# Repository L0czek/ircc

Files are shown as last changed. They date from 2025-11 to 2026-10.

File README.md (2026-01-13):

# Resonant Converter Controller

This repository contains a work-in-progress resonant converter controller project based on the STM32G474 microcontroller. The system splits responsibilities between the MCU (`controller`) and a host application (`host`) running on an x86 machine for configuration, logging, and waveform retrieval.

**Goals**
- Implement a phase-shifted resonant converter controller using the STM32G474 high-resolution timers.
- Provide over-current and other protections using built-in ADCs and comparator peripherals.
- Log waveforms to local SRAM for later retrieval by the host.
- Provide a PC-side host binary to configure and interact with the MCU.

Repository layout
- [controller](controller): MCU firmware (STM32 HAL-based). Core control logic lives here.
- [host](host): Host-side application that communicates with the MCU (x86 binary).
- [target](target): CubeMX / board-specific projects and HAL integration for different targets/boards.
- [pcb](pcb): KiCad PCB design files for the controller hardware.
- [protocol](protocol): Protocol definitions and protobufs used by host/MCU.
- [external](external): Third-party libraries and dependencies (e.g., nanpb, drivers).
- [build](build): Top-level build artifacts and CMake cache (generated during builds).

Quick start

Build host part (x86):

1. Enter the host directory and create a build directory:

```bash
cd host
mkdir -p build && cd build
cmake ..
make -j
```

The produced host binary will be in `host/build` (or as specified by the host CMakeLists).

Build MCU firmware:

1. Edit or inspect the CubeMX project in the appropriate `target/*` folder (for your chosen board). Generate code from CubeMX if you modify pin/peripheral configuration.
2. Use CMake from the top-level CMake to build the firmware. Example (from project root):

```bash
mkdir -p build-mcu && cd build-mcu
cmake -DCMAKE_TOOLCHAIN_FILE=cmake/gcc-arm-none-eabi.cmake ..
make -j
```

Flashing and debugging
- An OpenOCD config is available at `build/openocd.cfg` for target debugging.
- Typical workflow using the repository make targets:

	1. Start OpenOCD to provide the debug server:

		 ```bash
		 make openocd
		 ```

	2. In a separate terminal, flash or debug the firmware:

		 - To flash and run the firmware:

			 ```bash
			 make run
			 ```

		 - To spawn `gdb` for interactive debugging (connects to the OpenOCD server):

			 ```bash
			 make gdb
			 ```

- Or use your preferred OpenOCD/ST-Link workflow if you have a different setup.

Protocol and message formats
- Communication between host and MCU uses a UART serial link and the message definitions in the [protocol](protocol) directory (protobuf/nanopb). Regenerate or inspect generated code if you change `.proto` files.

Design notes
- The controller firmware uses the STM32G474 high-resolution timers to implement phase-shift control for MOSFET/IGBT bridge switching.
- ADCs, comparators, and timers are used for protections, sampling, and logging to SRAM.

Acknowledgements
- Third-party libraries are located in `external/` — see their respective LICENSE files for details.

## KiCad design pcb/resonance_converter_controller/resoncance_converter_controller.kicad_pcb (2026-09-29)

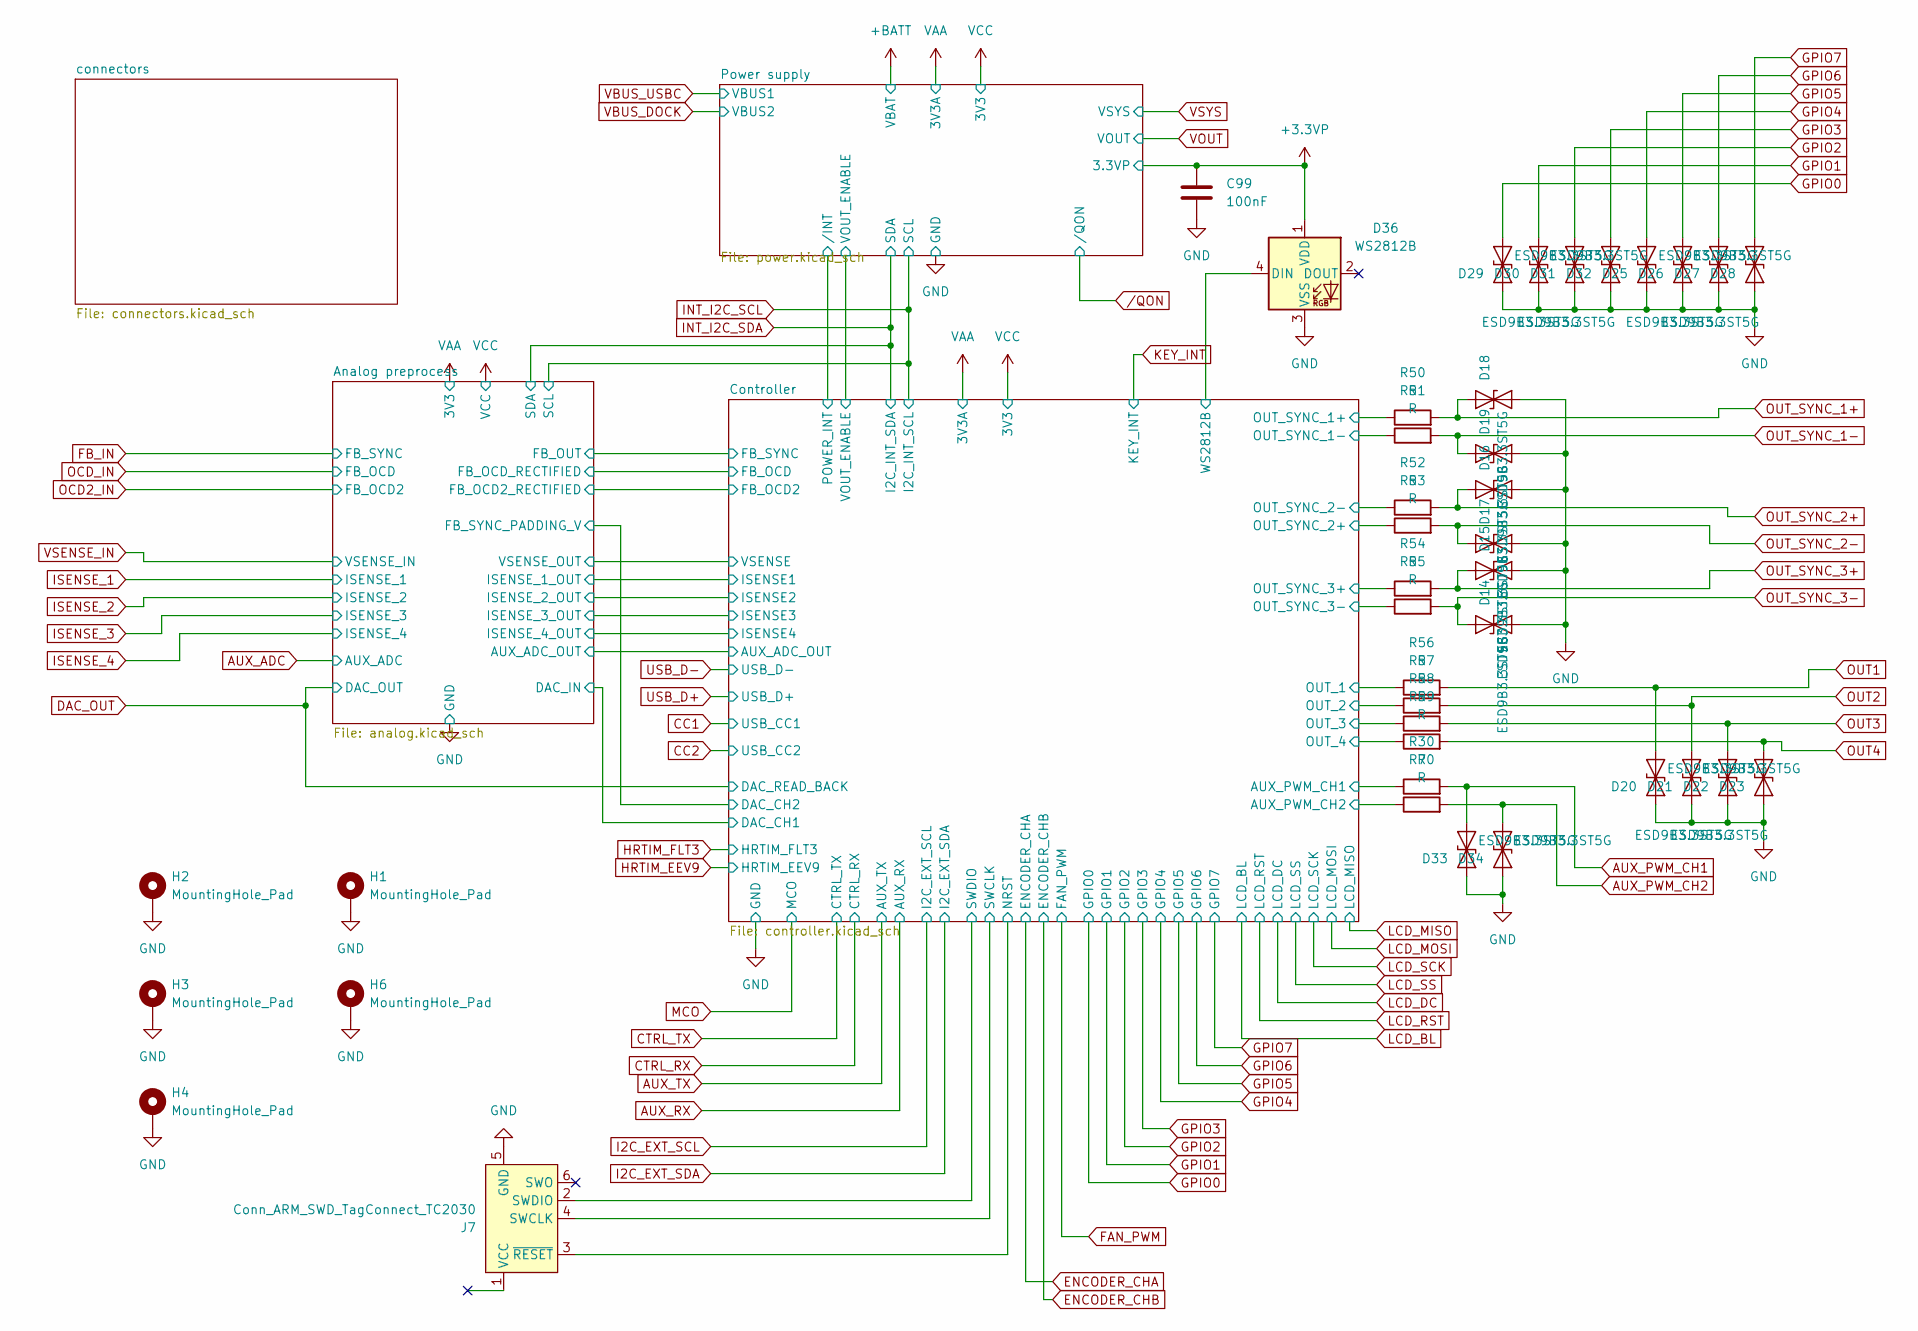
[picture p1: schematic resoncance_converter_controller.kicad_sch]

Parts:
C99: 100nF; C_0402_1005Metric
D14, D15, D16, D17, D18, D19, D20, D21, D22, D23, D25, D26, D27, D28, D29, D30, D31, D32, D33, D34: ESD9B3.3ST5G; D_SOD-923
D36: WS2812B; LED_WS2812B-Mini_PLCC4_3.5x3.5mm
H1, H2, H3, H4, H6: MountingHole_Pad; MountingHole_2.2mm_M2_Pad_Via
J7: Conn_ARM_SWD_TagConnect_TC2030; Tag-Connect_TC2030-IDC-FP_2x03_P1.27mm_Vertical
R30, R50, R51, R52, R53, R54, R55, R56, R57, R58, R59, R70: R; R_0402_1005Metric

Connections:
+3.3VP: C99.1, D36.1 (VDD); also elsewhere on the board
/Controller/AUX_PWM_CH1: R30.1; also elsewhere on the board
/Controller/AUX_PWM_CH2: R70.1; also elsewhere on the board
/Controller/OUT_1: R56.1; also elsewhere on the board
/Controller/OUT_2: R57.1; also elsewhere on the board
/Controller/OUT_3: R58.1; also elsewhere on the board
/Controller/OUT_4: R59.1; also elsewhere on the board
/Controller/OUT_SYNC_1+: R50.1; also elsewhere on the board
/Controller/OUT_SYNC_1-: R51.1; also elsewhere on the board
/Controller/OUT_SYNC_2+: R53.1; also elsewhere on the board
/Controller/OUT_SYNC_2-: R52.1; also elsewhere on the board
/Controller/OUT_SYNC_3+: R54.1; also elsewhere on the board
/Controller/OUT_SYNC_3-: R55.1; also elsewhere on the board
/Controller/WS2812B: D36.4 (DIN); also elsewhere on the board
AUX_PWM_CH1: D33.1 (A1), R30.2; also elsewhere on the board
AUX_PWM_CH2: D34.1 (A1), R70.2; also elsewhere on the board
GND: C99.2, D14.1 (A1), D15.1 (A1), D16.1 (A1), D17.1 (A1), D18.1 (A1), D19.1 (A1), D20.2 (A2), D21.2 (A2), D22.2 (A2), D23.2 (A2), D25.2 (A2), D26.2 (A2), D27.2 (A2), D28.2 (A2), D29.2 (A2), D30.2 (A2), D31.2 (A2), D32.2 (A2), D33.2 (A2), D34.2 (A2), D36.3 (VSS), H1.1 (1_1), H2.1 (1_1), H3.1 (1_1), H4.1 (1_1), H6.1 (1_1), J7.5 (GND); also elsewhere on the board
GPIO0: D29.1 (A1); also elsewhere on the board
GPIO1: D30.1 (A1); also elsewhere on the board
GPIO2: D31.1 (A1); also elsewhere on the board
GPIO3: D32.1 (A1); also elsewhere on the board
GPIO4: D25.1 (A1); also elsewhere on the board
GPIO5: D26.1 (A1); also elsewhere on the board
GPIO6: D27.1 (A1); also elsewhere on the board
GPIO7: D28.1 (A1); also elsewhere on the board
NRST: J7.3 (~RESET); also elsewhere on the board
OUT1: D20.1 (A1), R56.2; also elsewhere on the board
OUT2: D21.1 (A1), R57.2; also elsewhere on the board
OUT3: D22.1 (A1), R58.2; also elsewhere on the board
OUT4: D23.1 (A1), R59.2; also elsewhere on the board
OUT_SYNC_1+: D18.2 (A2), R50.2; also elsewhere on the board
OUT_SYNC_1-: D19.2 (A2), R51.2; also elsewhere on the board
OUT_SYNC_2+: D16.2 (A2), R52.2; also elsewhere on the board
OUT_SYNC_2-: D17.2 (A2), R53.2; also elsewhere on the board
OUT_SYNC_3+: D15.2 (A2), R54.2; also elsewhere on the board
OUT_SYNC_3-: D14.2 (A2), R55.2; also elsewhere on the board
SWCLK: J7.4 (SWCLK); also elsewhere on the board
SWDIO: J7.2 (SWDIO); also elsewhere on the board

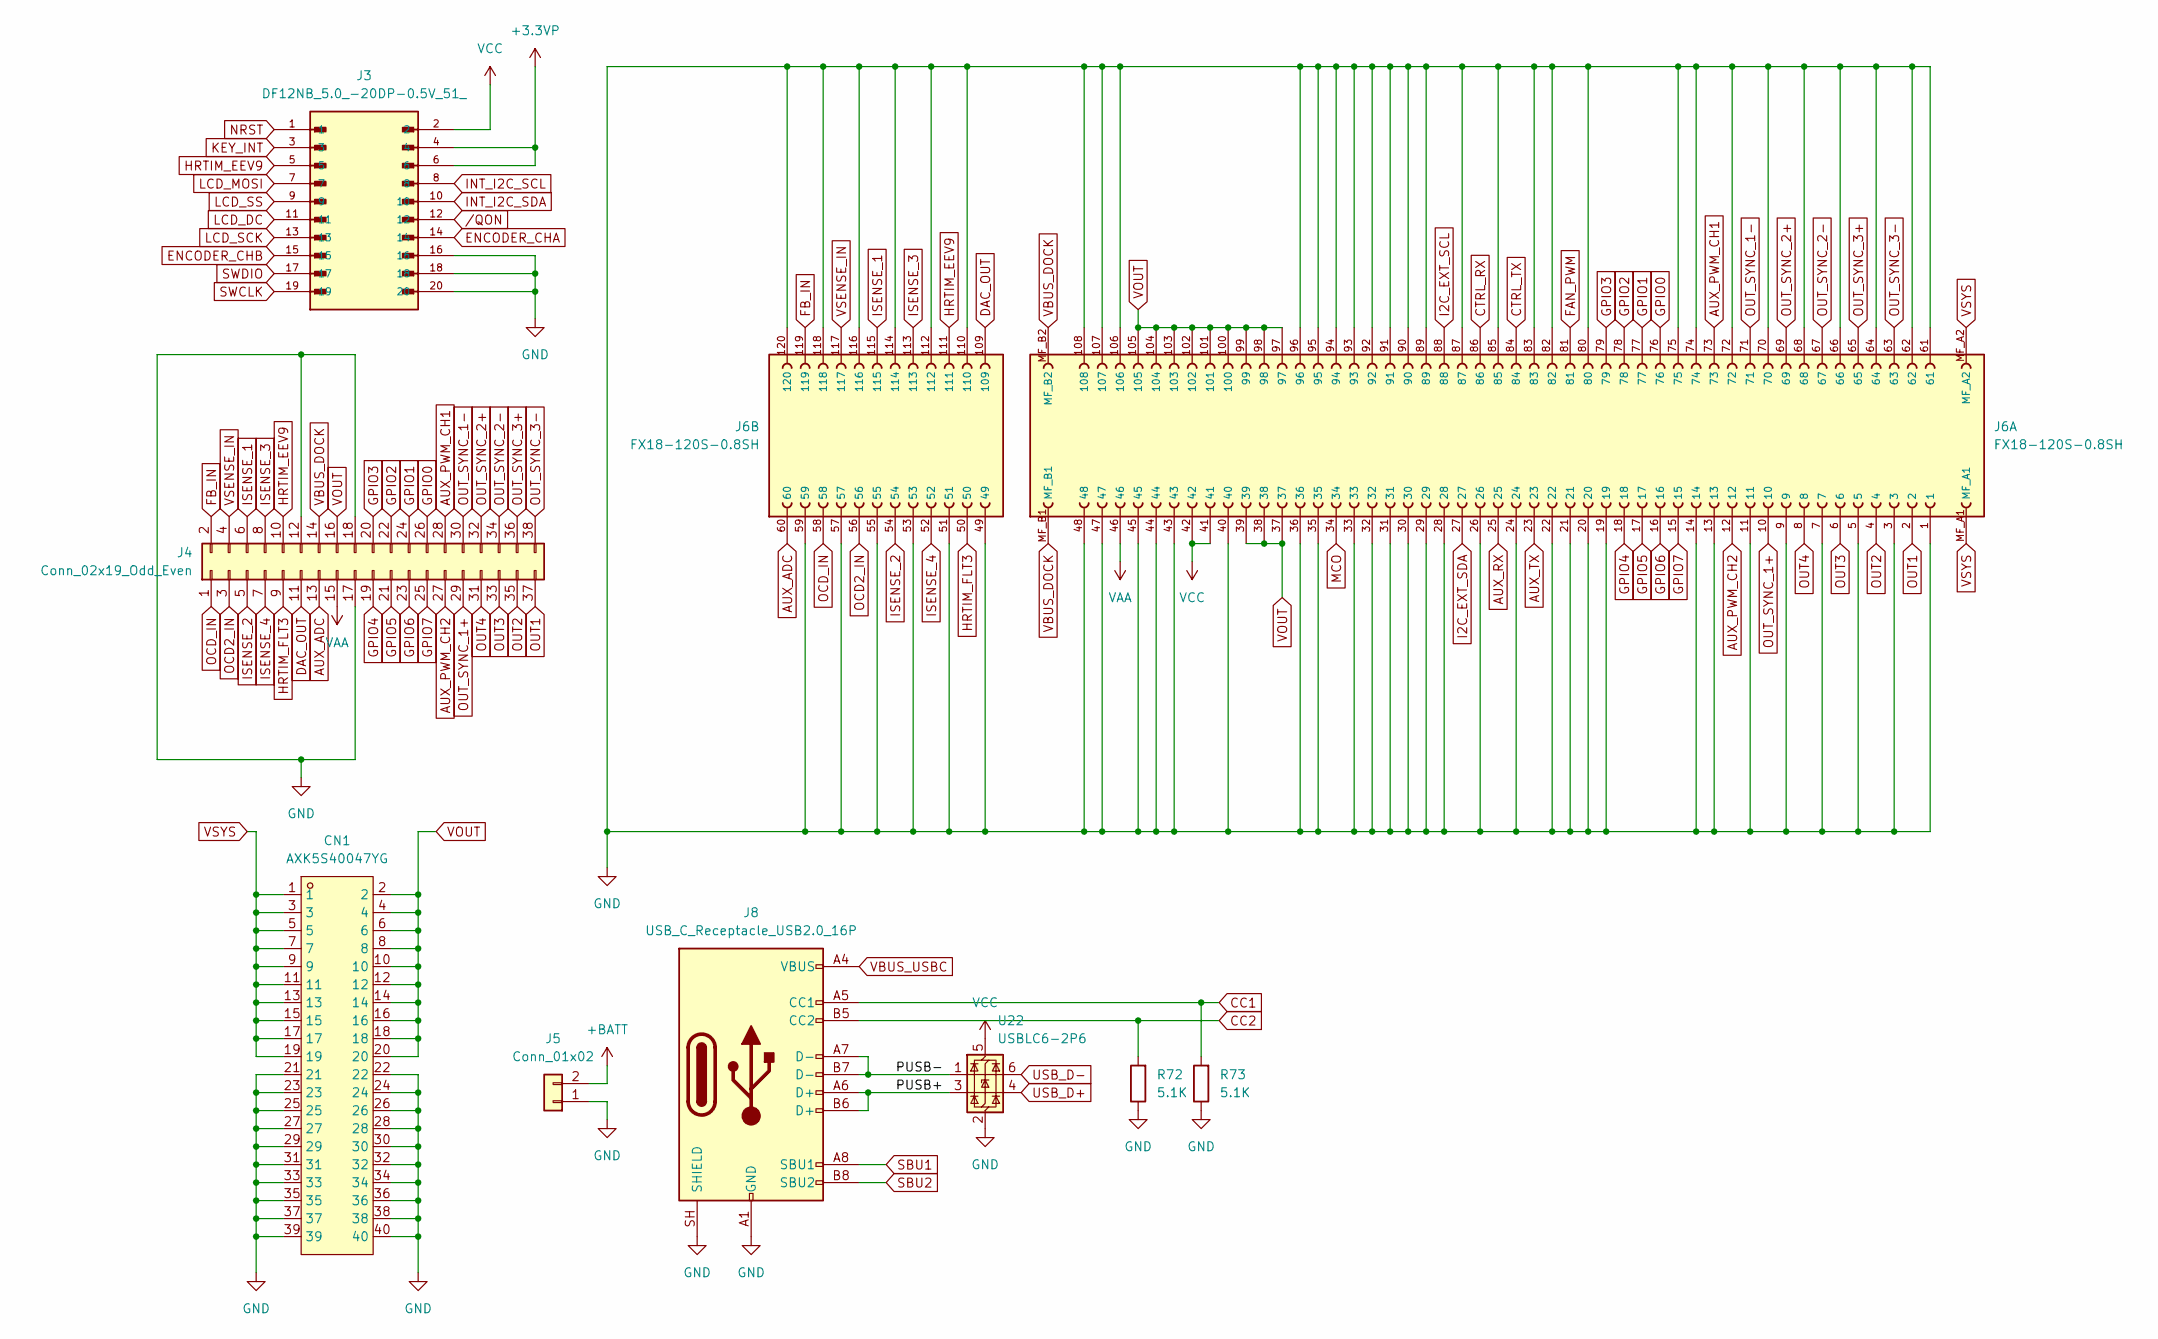
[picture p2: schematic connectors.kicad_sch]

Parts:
CN1: AXK5S40047YG; CONN-SMD_40P-P0.50_AXK5S40047YG; LCSC Part C3647996
J3: DF12NB_5.0_-20DP-0.5V_51_; HRS_DF12NB_5.0_-20DP-0.5V_51_
J4: Conn_02x19_Odd_Even; PinSocket_2x19_P2.54mm_Vertical_SMD
J5: Conn_01x02; AMASS_XT30U-M_1x02_P5.0mm_Vertical
J6: FX18-120S-0.8SH; HIROSE_FX18-120S-0.8SH; PARTREV 1
J8: USB_C_Receptacle_USB2.0_16P; USB_C_Receptacle_GCT_USB4105-xx-A_16P_TopMnt_Horizontal
R72, R73: 5.1K; R_0402_1005Metric
U22: USBLC6-2P6; SOT-666

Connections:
+3.3VP: J3.4, J3.6; also elsewhere on the board
+BATT: J5.2; also elsewhere on the board
/connectors/PUSB+: J8.A6 (D+), J8.B6 (D+), U22.3 (I/O2)
/connectors/PUSB-: J8.A7 (D-), J8.B7 (D-), U22.1 (I/O1)
AUX_ADC: J4.13, J6.60; also elsewhere on the board
AUX_PWM_CH1: J4.28, J6.73; also elsewhere on the board
AUX_PWM_CH2: J4.27, J6.12; also elsewhere on the board
AUX_RX: J6.25; also elsewhere on the board
AUX_TX: J6.23; also elsewhere on the board
CC1: J8.A5 (CC1), R73.2; also elsewhere on the board
CC2: J8.B5 (CC2), R72.2; also elsewhere on the board
CTRL_RX: J6.86; also elsewhere on the board
CTRL_TX: J6.84; also elsewhere on the board
DAC_OUT: J4.11, J6.109; also elsewhere on the board
ENCODER_CHA: J3.14; also elsewhere on the board
ENCODER_CHB: J3.15; also elsewhere on the board
FAN_PWM: J6.81; also elsewhere on the board
FB_IN: J4.2, J6.119; also elsewhere on the board
GND: CN1.21, CN1.22, CN1.23, CN1.24, CN1.25, CN1.26, CN1.27, CN1.28, CN1.29, CN1.30, CN1.31, CN1.32, CN1.33, CN1.34, CN1.35, CN1.36, CN1.37, CN1.38, CN1.39, CN1.40, J3.16, J3.18, J3.20, J4.12, J4.17, J4.18, J5.1, J6.1, J6.3, J6.5, J6.7, J6.9, J6.11, J6.13, J6.14, J6.19, J6.20, J6.21, J6.22, J6.24, J6.26, J6.28, J6.29, J6.30, J6.31, J6.32, J6.33, J6.35, J6.36, J6.40, J6.43, J6.44, J6.45, J6.47, J6.48, J6.49, J6.51, J6.53, J6.55, J6.57, J6.59, J6.61, J6.62, J6.64, J6.66, J6.68, J6.70, J6.72, J6.74, J6.75, J6.80, J6.82, J6.83, J6.85, J6.87, J6.89, J6.90, J6.91, J6.92, J6.93, J6.94, J6.95, J6.96, J6.106, J6.107, J6.108, J6.110, J6.112, J6.114, J6.116, J6.118, J6.120, J8.A1 (GND), J8.A12 (GND), J8.B1 (GND), J8.B12 (GND), J8.SH (SHIELD), R72.1, R73.1, U22.2 (GND); also elsewhere on the board
GPIO0: J4.26, J6.76; also elsewhere on the board
GPIO1: J4.24, J6.77; also elsewhere on the board
GPIO2: J4.22, J6.78; also elsewhere on the board
GPIO3: J4.20, J6.79; also elsewhere on the board
GPIO4: J4.19, J6.18; also elsewhere on the board
GPIO5: J4.21, J6.17; also elsewhere on the board
GPIO6: J4.23, J6.16; also elsewhere on the board
GPIO7: J4.25, J6.15; also elsewhere on the board
HRTIM_EEV9: J3.5, J4.10, J6.111; also elsewhere on the board
HRTIM_FLT3: J4.9, J6.50; also elsewhere on the board
I2C_EXT_SCL: J6.88; also elsewhere on the board
I2C_EXT_SDA: J6.27; also elsewhere on the board
INT_I2C_SCL: J3.8; also elsewhere on the board
INT_I2C_SDA: J3.10; also elsewhere on the board
ISENSE_1: J4.6, J6.115; also elsewhere on the board
ISENSE_2: J4.5, J6.54; also elsewhere on the board
ISENSE_3: J4.8, J6.113; also elsewhere on the board
ISENSE_4: J4.7, J6.52; also elsewhere on the board
KEY_INT: J3.3; also elsewhere on the board
LCD_DC: J3.11; also elsewhere on the board
LCD_MOSI: J3.7; also elsewhere on the board
LCD_SCK: J3.13; also elsewhere on the board
LCD_SS: J3.9; also elsewhere on the board
MCO: J6.34; also elsewhere on the board
NRST: J3.1; also elsewhere on the board
OCD2_IN: J4.3, J6.56; also elsewhere on the board
OCD_IN: J4.1, J6.58; also elsewhere on the board
OUT1: J4.37, J6.2; also elsewhere on the board
OUT2: J4.35, J6.4; also elsewhere on the board
OUT3: J4.33, J6.6; also elsewhere on the board
OUT4: J4.31, J6.8; also elsewhere on the board
OUT_SYNC_1+: J4.29, J6.10; also elsewhere on the board
OUT_SYNC_1-: J4.30, J6.71; also elsewhere on the board
OUT_SYNC_2+: J4.32, J6.69; also elsewhere on the board
OUT_SYNC_2-: J4.34, J6.67; also elsewhere on the board
OUT_SYNC_3+: J4.36, J6.65; also elsewhere on the board
OUT_SYNC_3-: J4.38, J6.63; also elsewhere on the board
SBU1: J8.A8 (SBU1); also elsewhere on the board
SBU2: J8.B8 (SBU2); also elsewhere on the board
SWCLK: J3.19; also elsewhere on the board
SWDIO: J3.17; also elsewhere on the board
USB_D+: U22.4 (I/O2); also elsewhere on the board
USB_D-: U22.6 (I/O1); also elsewhere on the board
VAA: J4.15, J6.46; also elsewhere on the board
VBUS_DOCK: J4.14, J6.MF_B1, J6.MF_B2; also elsewhere on the board
VBUS_USBC: J8.A4 (VBUS), J8.A9 (VBUS), J8.B4 (VBUS), J8.B9 (VBUS); also elsewhere on the board
VCC: J3.2, J6.41, J6.42, U22.5 (VBUS); also elsewhere on the board
VOUT: CN1.2, CN1.4, CN1.6, CN1.8, CN1.10, CN1.12, CN1.14, CN1.16, CN1.18, CN1.20, J4.16, J6.37, J6.38, J6.39, J6.97, J6.98, J6.99, J6.100, J6.101, J6.102, J6.103, J6.104, J6.105; also elsewhere on the board
VSENSE_IN: J4.4, J6.117; also elsewhere on the board
VSYS: CN1.1, CN1.3, CN1.5, CN1.7, CN1.9, CN1.11, CN1.13, CN1.15, CN1.17, CN1.19, J6.MF_A1, J6.MF_A2; also elsewhere on the board
/QON: J3.12; also elsewhere on the board

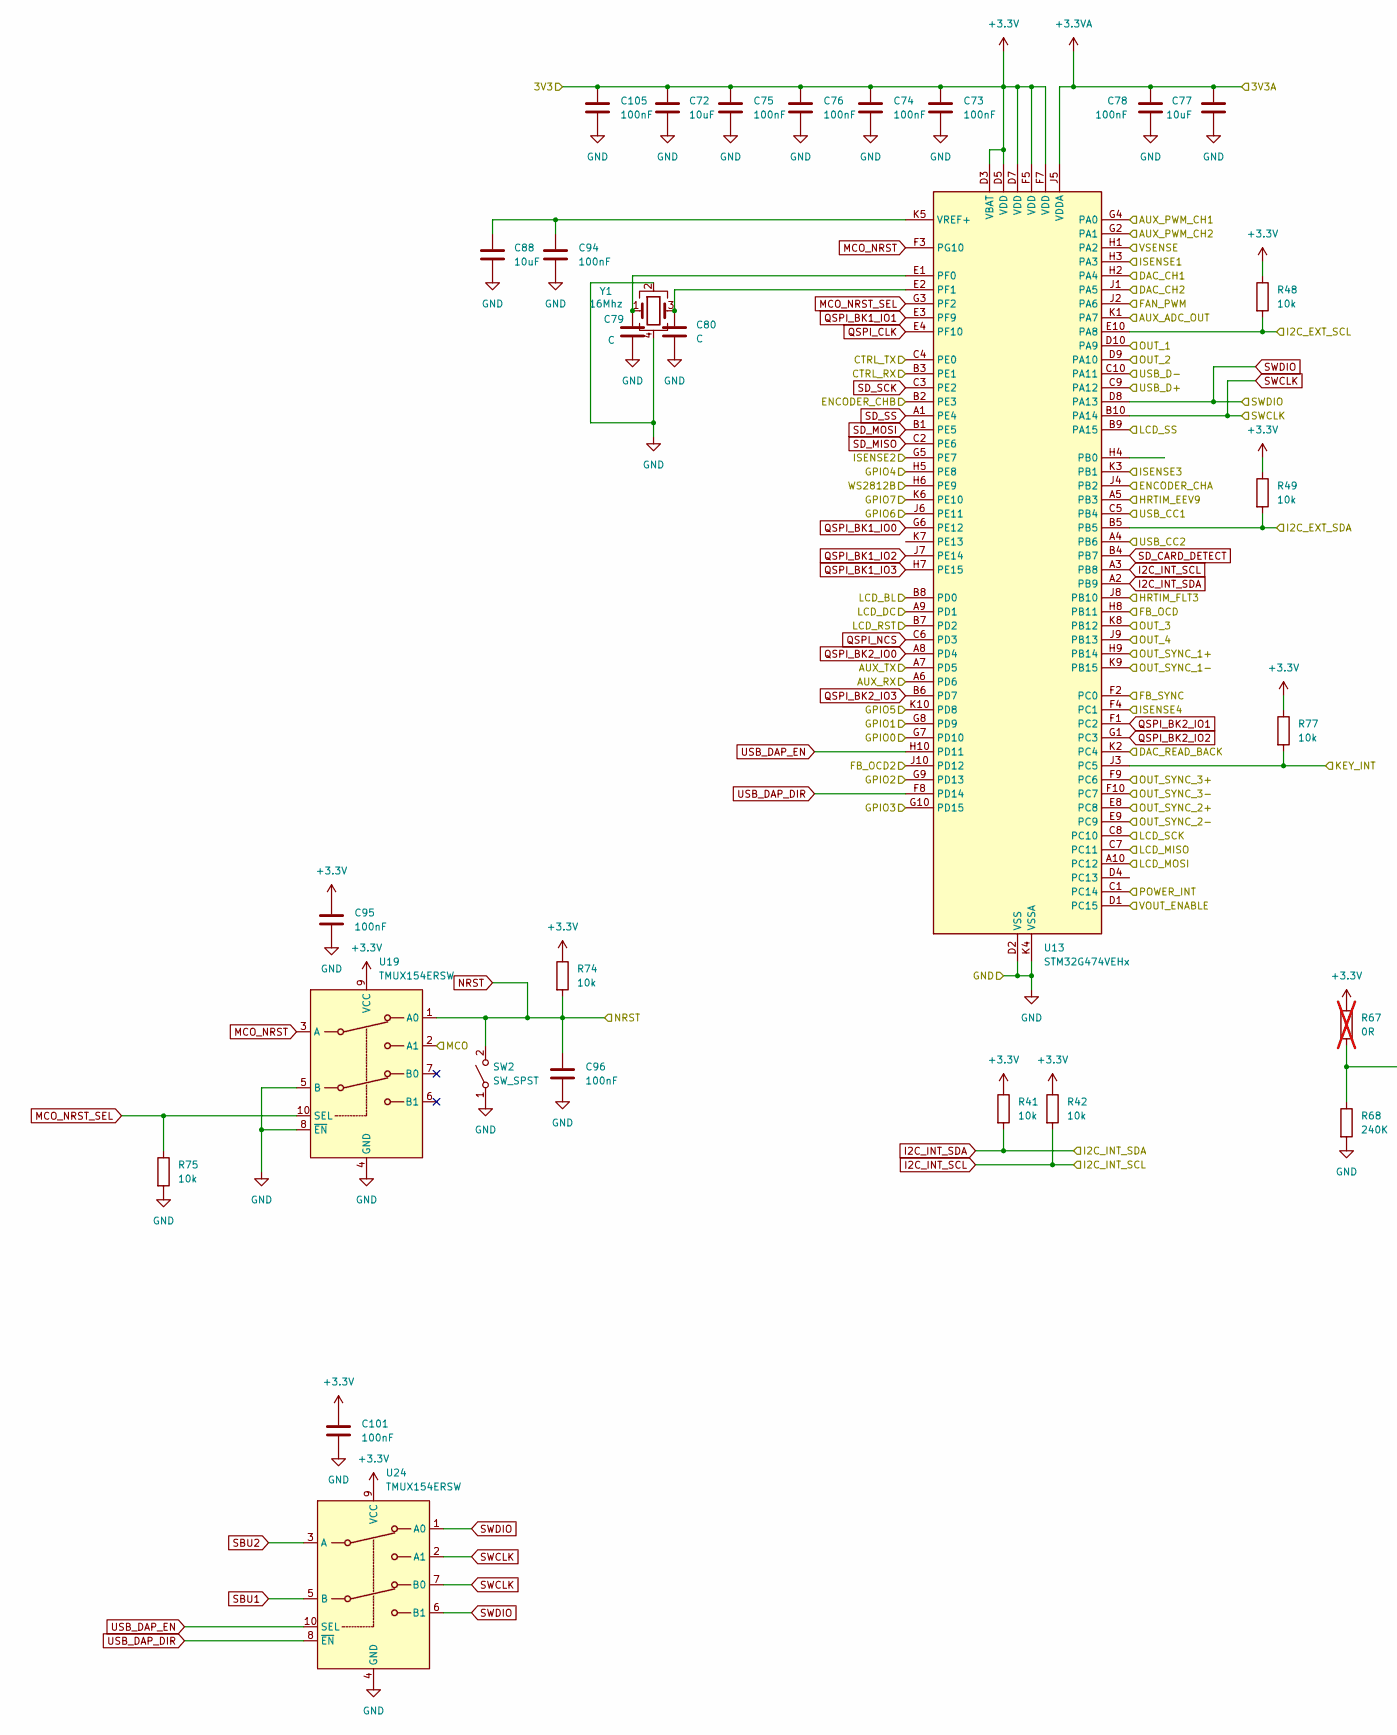
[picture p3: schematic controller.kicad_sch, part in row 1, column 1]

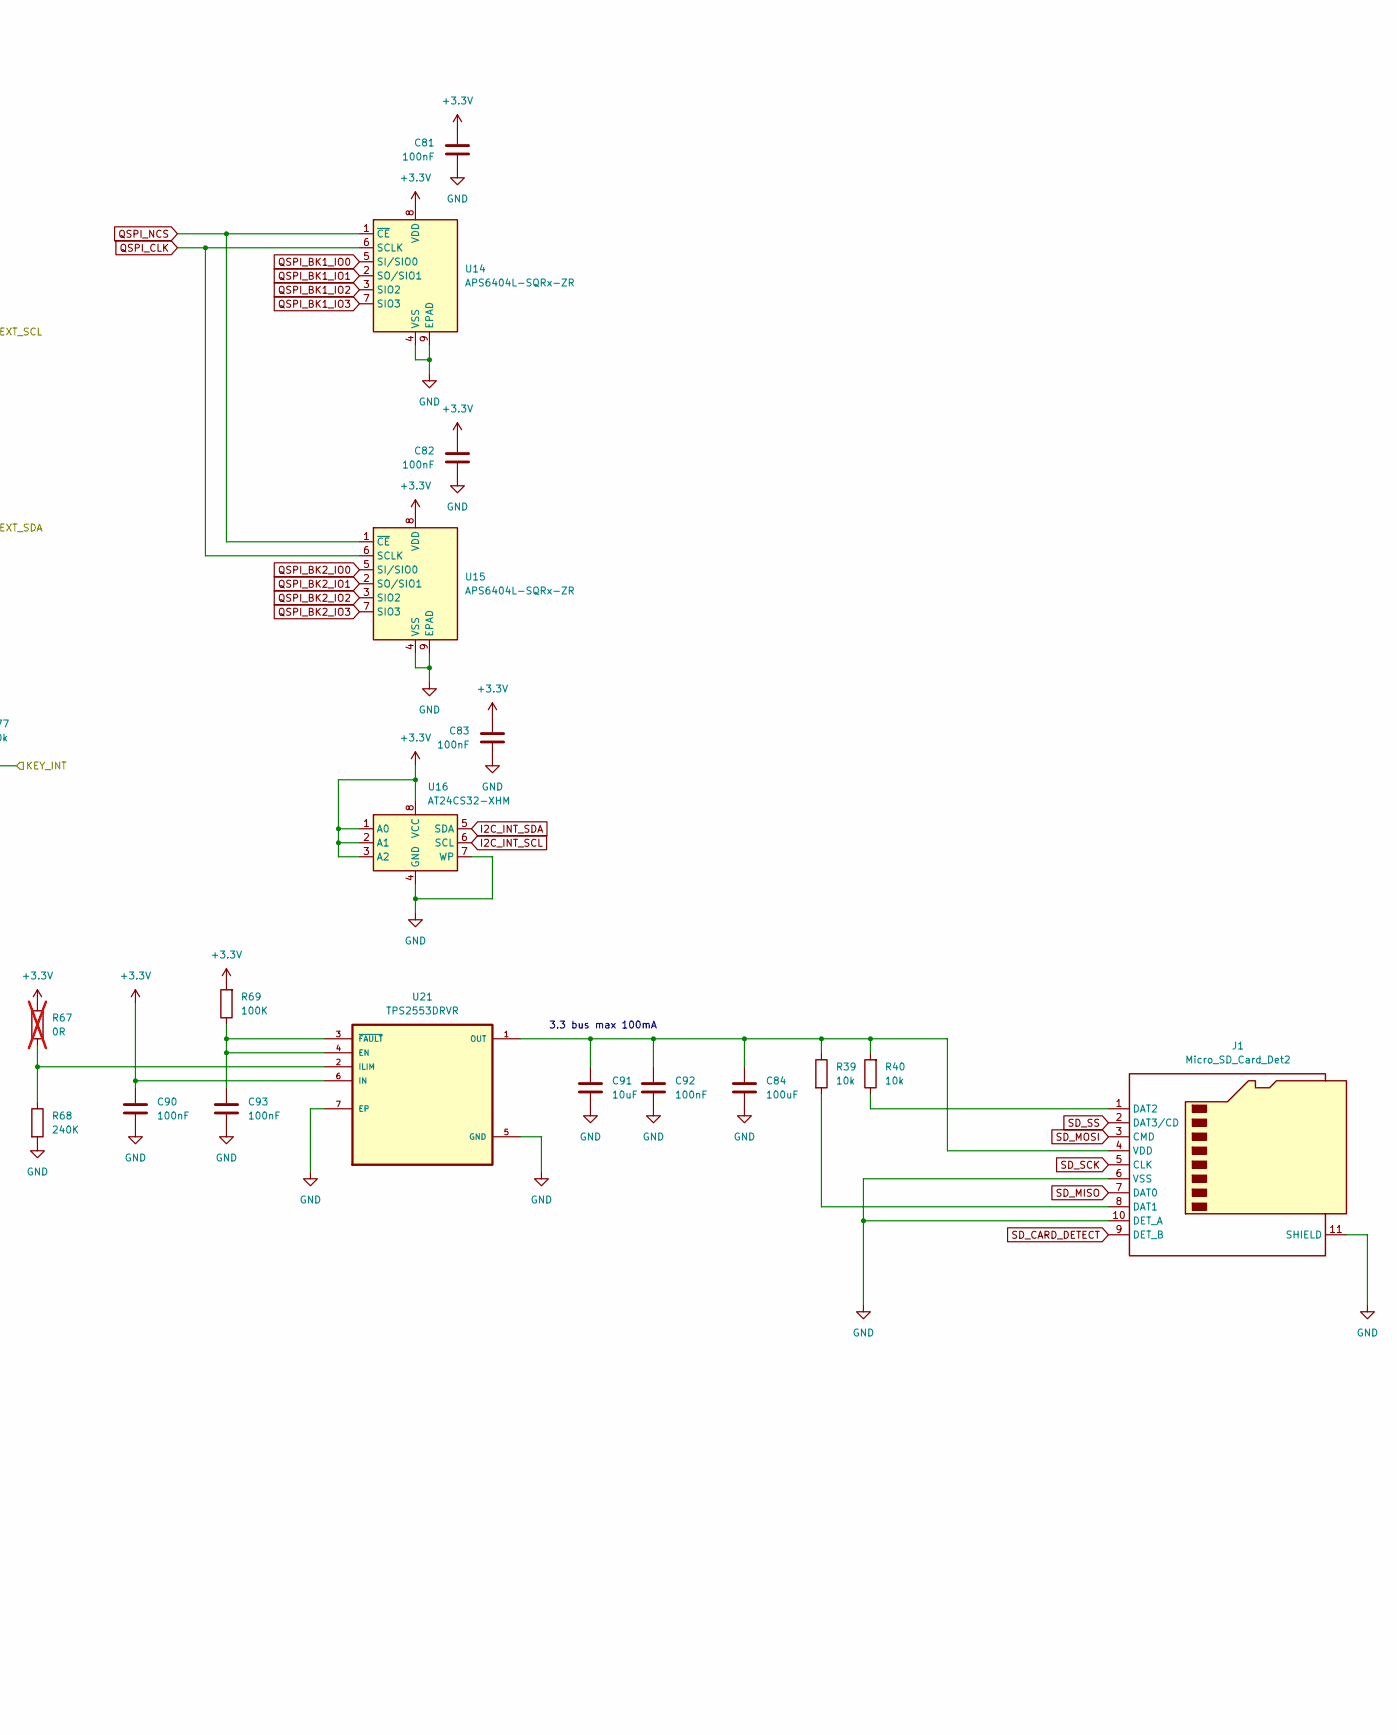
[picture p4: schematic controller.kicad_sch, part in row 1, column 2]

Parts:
C72, C77: 10uF; C_0805_2012Metric
C73, C74, C75, C76, C78, C81, C82, C83, C90, C92, C93, C94, C95, C96, C101, C105: 100nF; C_0402_1005Metric
C79, C80: C; C_0402_1005Metric
C84: 100uF; C_1206_3216Metric
C88: 10uF; C_0402_1005Metric
C91: 10uF; C_1206_3216Metric
J1: Micro_SD_Card_Det2; microSD_HC_Hirose_DM3BT-DSF-PEJS
R39, R40, R41, R42, R48, R49, R74, R75, R77: 10k; R_0402_1005Metric
R67: 0R; R_0402_1005Metric; not fitted
R68: 240K; R_0402_1005Metric
R69: 100K; R_0402_1005Metric
SW2: SW_SPST; SW_SPST_EVQPE1
U13: STM32G474VEHx; TFBGA-100_8x8mm_Layout10x10_P0.8mm
U14, U15: APS6404L-SQRx-ZR; Winbond_USON-8-1EP_3x2mm_P0.5mm_EP0.2x1.6mm
U16: AT24CS32-XHM; TSSOP-8_4.4x3mm_P0.65mm
U19, U24: TMUX154ERSW; UQFN-10_1.4x1.8mm_P0.4mm
U21: TPS2553DRVR; SON65P200X200X80-7N
Y1: 16Mhz; Crystal_SMD_3225-4Pin_3.2x2.5mm

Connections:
/Analog preprocess/DAC_IN: U13.H2 (PA4); also elsewhere on the board
/Analog preprocess/FB_OCD2_RECTIFIED: U13.J10 (PD12); also elsewhere on the board
/Analog preprocess/FB_OCD_RECTIFIED: U13.H8 (PB11); also elsewhere on the board
/Analog preprocess/FB_OUT: U13.F2 (PC0); also elsewhere on the board
/Analog preprocess/FB_SYNC_PADDING_V: U13.J1 (PA5); also elsewhere on the board
/Analog preprocess/VSENSE_OUT: U13.H1 (PA2); also elsewhere on the board
/Controller/AUX_PWM_CH1: U13.G4 (PA0); also elsewhere on the board
/Controller/AUX_PWM_CH2: U13.G2 (PA1); also elsewhere on the board
/Controller/OUT_1: U13.D10 (PA9); also elsewhere on the board
/Controller/OUT_2: U13.D9 (PA10); also elsewhere on the board
/Controller/OUT_3: U13.K8 (PB12); also elsewhere on the board
/Controller/OUT_4: U13.J9 (PB13); also elsewhere on the board
/Controller/OUT_SYNC_1+: U13.H9 (PB14); also elsewhere on the board
/Controller/OUT_SYNC_1-: U13.K9 (PB15); also elsewhere on the board
/Controller/OUT_SYNC_2+: U13.E8 (PC8); also elsewhere on the board
/Controller/OUT_SYNC_2-: U13.E9 (PC9); also elsewhere on the board
/Controller/OUT_SYNC_3+: U13.F9 (PC6); also elsewhere on the board
/Controller/OUT_SYNC_3-: U13.F10 (PC7); also elsewhere on the board
/Controller/VOUT_ENABLE: U13.D1 (PC15); also elsewhere on the board
/Controller/WS2812B: U13.H6 (PE9); also elsewhere on the board
AUX_ADC: U13.K1 (PA7); also elsewhere on the board
AUX_RX: U13.A6 (PD6); also elsewhere on the board
AUX_TX: U13.A7 (PD5); also elsewhere on the board
CC1: U13.C5 (PB4); also elsewhere on the board
CC2: U13.A4 (PB6); also elsewhere on the board
CTRL_RX: U13.B3 (PE1); also elsewhere on the board
CTRL_TX: U13.C4 (PE0); also elsewhere on the board
DAC_OUT: U13.K2 (PC4); also elsewhere on the board
ENCODER_CHA: U13.J4 (PB2); also elsewhere on the board
ENCODER_CHB: U13.B2 (PE3); also elsewhere on the board
FAN_PWM: U13.J2 (PA6); also elsewhere on the board
GND: C72.2, C73.2, C74.2, C75.2, C76.2, C77.2, C78.2, C79.2, C80.2, C81.2, C82.2, C83.2, C84.2, C88.2, C90.2, C91.2, C92.2, C93.2, C94.2, C95.2, C96.2, C101.2, C105.2, J1.6 (VSS), J1.10 (DET_A), J1.11 (SHIELD), R68.2, R75.2, SW2.1 (A), U13.D2 (VSS), U13.D6 (VSS), U13.E5 (VSS), U13.E6 (VSS), U13.E7 (VSS), U13.F6 (VSS), U13.K4 (VSSA), U14.4 (VSS), U14.9 (EPAD), U15.4 (VSS), U15.9 (EPAD), U16.4 (GND), U16.7 (WP), U19.4 (GND), U19.5 (B), U19.8 (~EN), U21.5 (GND), U21.7 (EP), U24.4 (GND), Y1.2, Y1.4; also elsewhere on the board
GPIO0: U13.G7 (PD10); also elsewhere on the board
GPIO1: U13.G8 (PD9); also elsewhere on the board
GPIO2: U13.G9 (PD13); also elsewhere on the board
GPIO3: U13.G10 (PD15); also elsewhere on the board
GPIO4: U13.H5 (PE8); also elsewhere on the board
GPIO5: U13.K10 (PD8); also elsewhere on the board
GPIO6: U13.J6 (PE11); also elsewhere on the board
GPIO7: U13.K6 (PE10); also elsewhere on the board
HRTIM_EEV9: U13.A5 (PB3); also elsewhere on the board
HRTIM_FLT3: U13.J8 (PB10); also elsewhere on the board
I2C_EXT_SCL: R48.2, U13.E10 (PA8); also elsewhere on the board
I2C_EXT_SDA: R49.2, U13.B5; also elsewhere on the board
INT_I2C_SCL: R42.2, U13.A3 (PB8), U16.6 (SCL); also elsewhere on the board
INT_I2C_SDA: R41.2, U13.A2 (PB9), U16.5 (SDA); also elsewhere on the board
ISENSE_1_DPOT: U13.H3 (PA3); also elsewhere on the board
ISENSE_2_DPOT: U13.G5 (PE7); also elsewhere on the board
ISENSE_3_DPOT: U13.K3 (PB1); also elsewhere on the board
ISENSE_4_DPOT: U13.F4 (PC1); also elsewhere on the board
KEY_INT: R77.2, U13.J3 (PC5); also elsewhere on the board
LCD_BL: U13.B8 (PD0)
LCD_DC: U13.A9 (PD1); also elsewhere on the board
LCD_MISO: U13.C7 (PC11)
LCD_MOSI: U13.A10 (PC12); also elsewhere on the board
LCD_RST: U13.B7 (PD2)
LCD_SCK: U13.C8 (PC10); also elsewhere on the board
LCD_SS: U13.B9 (PA15); also elsewhere on the board
MCO: U19.2 (A1); also elsewhere on the board
MCO_NRST: U13.F3 (PG10), U19.3 (A)
MCO_NRST_SEL: R75.1, U13.G3 (PF2), U19.10 (SEL)
NRST: C96.1, R74.2, SW2.2 (B), U19.1 (A0); also elsewhere on the board
unnamed: J1.8 (DAT1), R39.2
unnamed: J1.1 (DAT2), R40.1
unnamed: C84.1, C91.1, C92.1, J1.4 (VDD), R39.1, R40.2, U21.1 (OUT)
unnamed: C79.1, U13.E1 (PF0), Y1.1
unnamed: C80.1, U13.E2 (PF1), Y1.3
unnamed: C88.1, C94.1, U13.K5 (VREF+)
unnamed: C93.1, R69.1, U21.3 (~FAULT), U21.4 (EN)
unnamed: R67.2, R68.1, U21.2 (ILIM)
QSPI_BK1_IO0: U13.G6 (PE12), U14.5 (SI/SIO0)
QSPI_BK1_IO1: U13.E3 (PF9), U14.2 (SO/SIO1)
QSPI_BK1_IO2: U13.J7 (PE14), U14.3 (SIO2)
QSPI_BK1_IO3: U13.H7 (PE15), U14.7 (SIO3)
QSPI_BK2_IO0: U13.A8 (PD4), U15.5 (SI/SIO0)
QSPI_BK2_IO1: U13.F1 (PC2), U15.2 (SO/SIO1)
QSPI_BK2_IO2: U13.G1 (PC3), U15.3 (SIO2)
QSPI_BK2_IO3: U13.B6 (PD7), U15.7 (SIO3)
QSPI_CLK: U13.E4 (PF10), U14.6 (SCLK), U15.6 (SCLK)
QSPI_NCS: U13.C6 (PD3), U14.1 (~CE), U15.1 (~CE)
SBU1: U24.5 (B); also elsewhere on the board
SBU2: U24.3 (A); also elsewhere on the board
SD_CARD_DETECT: J1.9 (DET_B), U13.B4 (PB7)
SD_MISO: J1.7 (DAT0), U13.C2 (PE6)
SD_MOSI: J1.3 (CMD), U13.B1 (PE5)
SD_SCK: J1.5 (CLK), U13.C3 (PE2)
SD_SS: J1.2 (DAT3/CD), U13.A1 (PE4)
SWCLK: U13.B10 (PA14), U24.2 (A1), U24.7 (B0); also elsewhere on the board
SWDIO: U13.D8 (PA13), U24.1 (A0), U24.6 (B1); also elsewhere on the board
USB_D+: U13.C9 (PA12); also elsewhere on the board
USB_D-: U13.C10 (PA11); also elsewhere on the board
USB_DAP_DIR: U13.F8 (PD14), U24.8 (~EN)
USB_DAP_EN: U13.H10 (PD11), U24.10 (SEL)
VAA: C77.1, C78.1, U13.J5 (VDDA); also elsewhere on the board
VCC: C72.1, C73.1, C74.1, C75.1, C76.1, C81.1, C82.1, C83.1, C90.1, C95.1, C101.1, C105.1, R41.1, R42.1, R48.1, R49.1, R67.1, R69.2, R74.1, R77.1, U13.D3 (VBAT), U13.D5 (VDD), U13.D7 (VDD), U13.F5 (VDD), U13.F7 (VDD), U14.8 (VDD), U15.8 (VDD), U16.1 (A0), U16.2 (A1), U16.3 (A2), U16.8 (VCC), U19.9 (VCC), U21.6 (IN), U24.9 (VCC); also elsewhere on the board
/INT: U13.C1 (PC14); also elsewhere on the board

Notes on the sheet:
3.3 bus max 100mA

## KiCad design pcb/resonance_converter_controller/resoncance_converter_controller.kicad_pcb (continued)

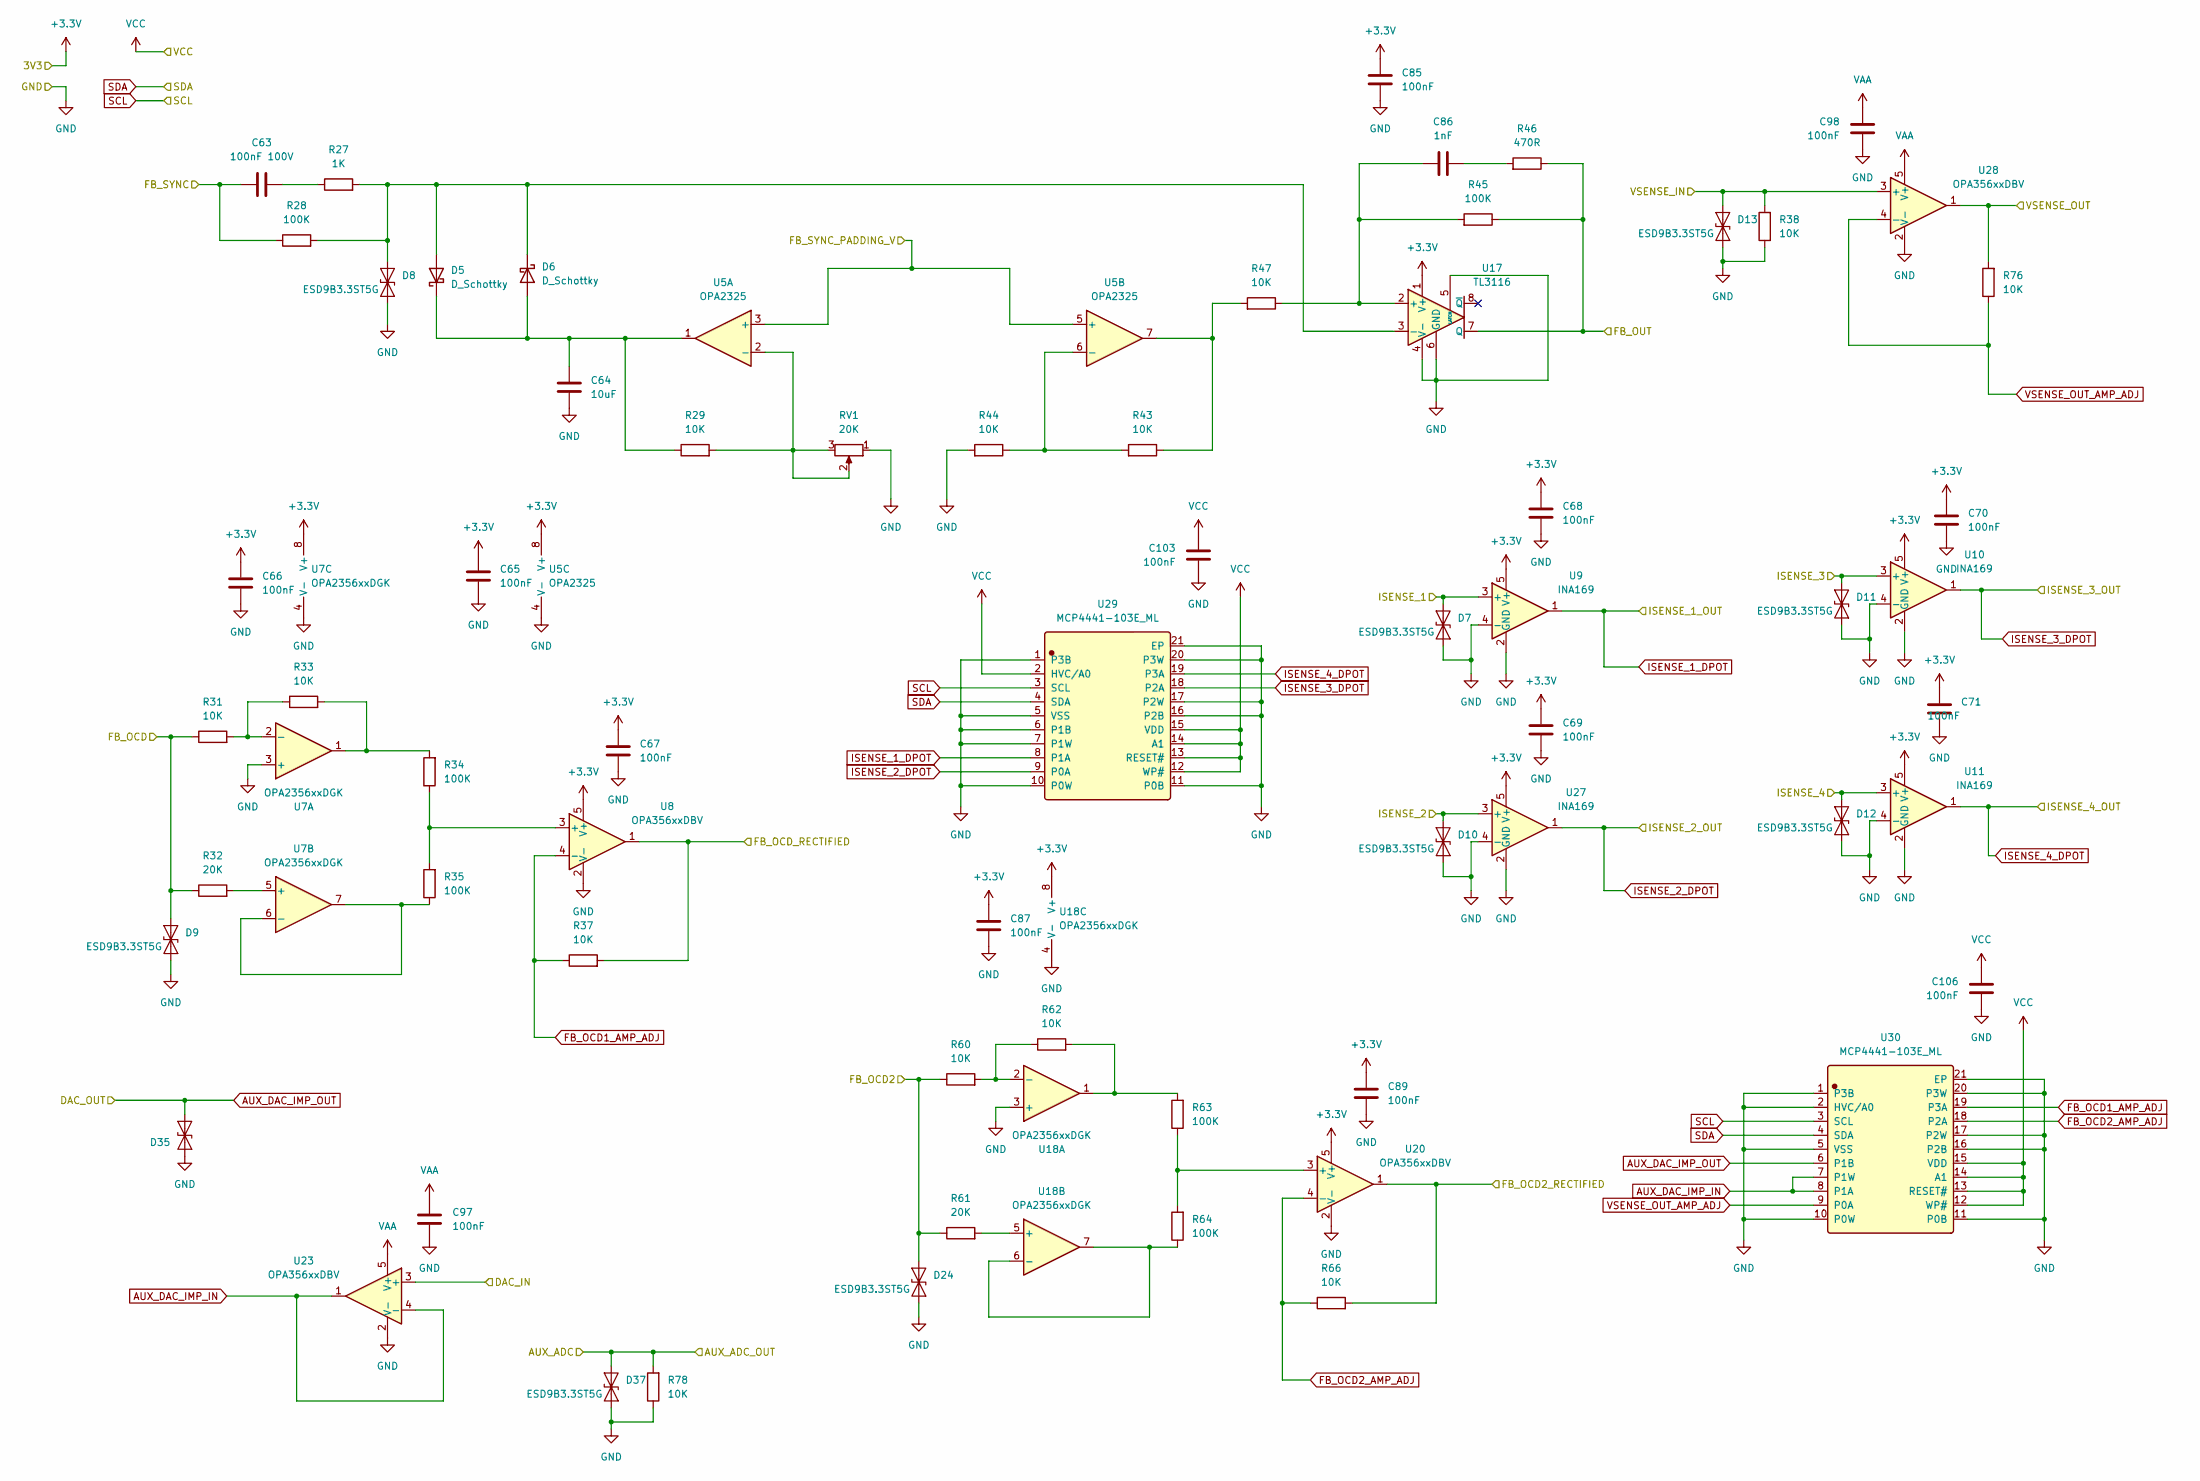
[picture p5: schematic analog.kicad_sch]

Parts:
C63: 100nF 100V; C_1206_3216Metric
C64: 10uF; C_1210_3225Metric
C65, C66, C67, C68, C69, C70, C71, C85, C87, C89, C97, C98, C103, C106: 100nF; C_0402_1005Metric
C86: 1nF; C_0402_1005Metric
D5, D6: D_Schottky; D_SOD-123
D7, D8, D9, D10, D11, D12, D13, D24, D35, D37: ESD9B3.3ST5G; D_SOD-923
R27: 1K; R_1206_3216Metric
R28: 100K; R_1206_3216Metric
R29, R31, R33, R37, R38, R43, R44, R47, R60, R62, R66, R76, R78: 10K; R_0402_1005Metric
R32, R61: 20K; R_0402_1005Metric
R34, R35, R45, R63, R64: 100K; R_0402_1005Metric
R46: 470R; R_0402_1005Metric
RV1: 20K; Potentiometer_Bourns_3269W_Vertical
U5: OPA2325; VSSOP-8_3x3mm_P0.65mm
U7, U18: OPA2356xxDGK; VSSOP-8_3x3mm_P0.65mm
U8, U20, U23, U28: OPA356xxDBV; SOT-23-5
U9, U10, U11, U27: INA169; SOT-23-5
U17: TL3116; TSSOP-8_4.4x3mm_P0.65mm
U29, U30: MCP4441-103E_ML; Texas_RGP0020H_VQFN-20-1EP_4x4mm_P0.5mm_EP2.4x2.4mm_Thermal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; Manufacturer Part MCP4441-103E/ML; LCSC C637735

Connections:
/Analog preprocess/DAC_IN: U23.3 (+); also elsewhere on the board
/Analog preprocess/FB_OCD2_RECTIFIED: R66.2, U20.1; also elsewhere on the board
/Analog preprocess/FB_OCD_RECTIFIED: R37.2, U8.1; also elsewhere on the board
/Analog preprocess/FB_OUT: R45.1, R46.1, U17.7 (Q); also elsewhere on the board
/Analog preprocess/FB_SYNC_PADDING_V: U5.3 (+), U5.5 (+); also elsewhere on the board
/Analog preprocess/VSENSE_OUT: R76.2, U28.1; also elsewhere on the board
AUX_ADC: D37.2 (A2), R78.2; also elsewhere on the board
AUX_DAC_IMP_IN: U23.1, U23.4 (-), U30.7 (P1W), U30.8 (P1A)
DAC_OUT: D35.1 (A1), U30.6 (P1B); also elsewhere on the board
FB_IN: C63.1, R28.1; also elsewhere on the board
FB_OCD1_AMP_ADJ: R37.1, U8.4 (-), U30.19 (P3A)
FB_OCD2_AMP_ADJ: R66.1, U20.4 (-), U30.18 (P2A)
GND: C64.1, C65.1, C66.1, C67.1, C68.1, C69.1, C70.1, C71.1, C85.1, C87.1, C89.1, C97.2, C98.2, C103.2, C106.2, D7.1 (A1), D8.1 (A1), D9.1 (A1), D10.1 (A1), D11.1 (A1), D12.1 (A1), D13.1 (A1), D24.1 (A1), D35.2 (A2), D37.1 (A1), R38.1, R44.2, R78.1, RV1.1, U5.4 (V-), U7.3 (+), U7.4 (V-), U8.2 (V-), U9.2 (GND), U9.4 (-), U10.2 (GND), U10.4 (-), U11.2 (GND), U11.4 (-), U17.4 (V-), U17.5 (LATCH), U17.6 (GND), U18.3 (+), U18.4 (V-), U20.2 (V-), U23.2 (V-), U27.2 (GND), U27.4 (-), U28.2 (V-), U29.1 (P3B), U29.5 (VSS), U29.6 (P1B), U29.7 (P1W), U29.10 (P0W), U29.11 (P0B), U29.16 (P2B), U29.17 (P2W), U29.20 (P3W), U29.21 (EP), U30.1 (P3B), U30.2 (HVC/A0), U30.5 (VSS), U30.10 (P0W), U30.11 (P0B), U30.16 (P2B), U30.17 (P2W), U30.20 (P3W), U30.21 (EP); also elsewhere on the board
INT_I2C_SCL: U29.3 (SCL), U30.3 (SCL); also elsewhere on the board
INT_I2C_SDA: U29.4 (SDA), U30.4 (SDA); also elsewhere on the board
ISENSE_1: D7.2 (A2), U9.3 (+); also elsewhere on the board
ISENSE_1_DPOT: U9.1, U29.8 (P1A); also elsewhere on the board
ISENSE_2: D10.2 (A2), U27.3 (+); also elsewhere on the board
ISENSE_2_DPOT: U27.1, U29.9 (P0A); also elsewhere on the board
ISENSE_3: D11.2 (A2), U10.3 (+); also elsewhere on the board
ISENSE_3_DPOT: U10.1, U29.18 (P2A); also elsewhere on the board
ISENSE_4: D12.2 (A2), U11.3 (+); also elsewhere on the board
ISENSE_4_DPOT: U11.1, U29.19 (P3A); also elsewhere on the board
unnamed: C63.2, R27.1
unnamed: C86.1, R46.2
unnamed: D5.2 (A), D6.1 (K), D8.2 (A2), R27.2, R28.2, U17.3 (-)
unnamed: C64.2, D5.1 (K), D6.2 (A), R29.1, U5.1
unnamed: R33.2, R34.2, U7.1
unnamed: R43.1, R47.2, U5.7
unnamed: R62.2, R63.2, U18.1
unnamed: R29.2, RV1.2, RV1.3, U5.2 (-)
unnamed: R43.2, R44.1, U5.6 (-)
unnamed: R31.2, R33.1, U7.2 (-)
unnamed: R32.2, U7.5 (+)
unnamed: R35.1, U7.6 (-), U7.7
unnamed: R34.1, R35.2, U8.3 (+)
unnamed: C86.2, R45.2, R47.1, U17.2 (+)
unnamed: R60.2, R62.1, U18.2 (-)
unnamed: R61.2, U18.5 (+)
unnamed: R64.1, U18.6 (-), U18.7
unnamed: R63.1, R64.2, U20.3 (+)
OCD2_IN: D24.2 (A2), R60.1, R61.1; also elsewhere on the board
OCD_IN: D9.2 (A2), R31.1, R32.1; also elsewhere on the board
VAA: C65.2, C66.2, C67.2, C68.2, C69.2, C70.2, C71.2, C85.2, C87.2, C89.2, C97.1, C98.1, U5.8 (V+), U7.8 (V+), U8.5 (V+), U9.5 (V+), U10.5 (V+), U11.5 (V+), U17.1 (V+), U18.8 (V+), U20.5 (V+), U23.5 (V+), U27.5 (V+), U28.5 (V+); also elsewhere on the board
VCC: C103.1, C106.1, U29.2 (HVC/A0), U29.12 (WP#), U29.13 (RESET#), U29.14 (A1), U29.15 (VDD), U30.12 (WP#), U30.13 (RESET#), U30.14 (A1), U30.15 (VDD); also elsewhere on the board
VSENSE_IN: D13.2 (A2), R38.2, U28.3 (+); also elsewhere on the board
VSENSE_OUT_AMP_ADJ: R76.1, U28.4 (-), U30.9 (P0A)

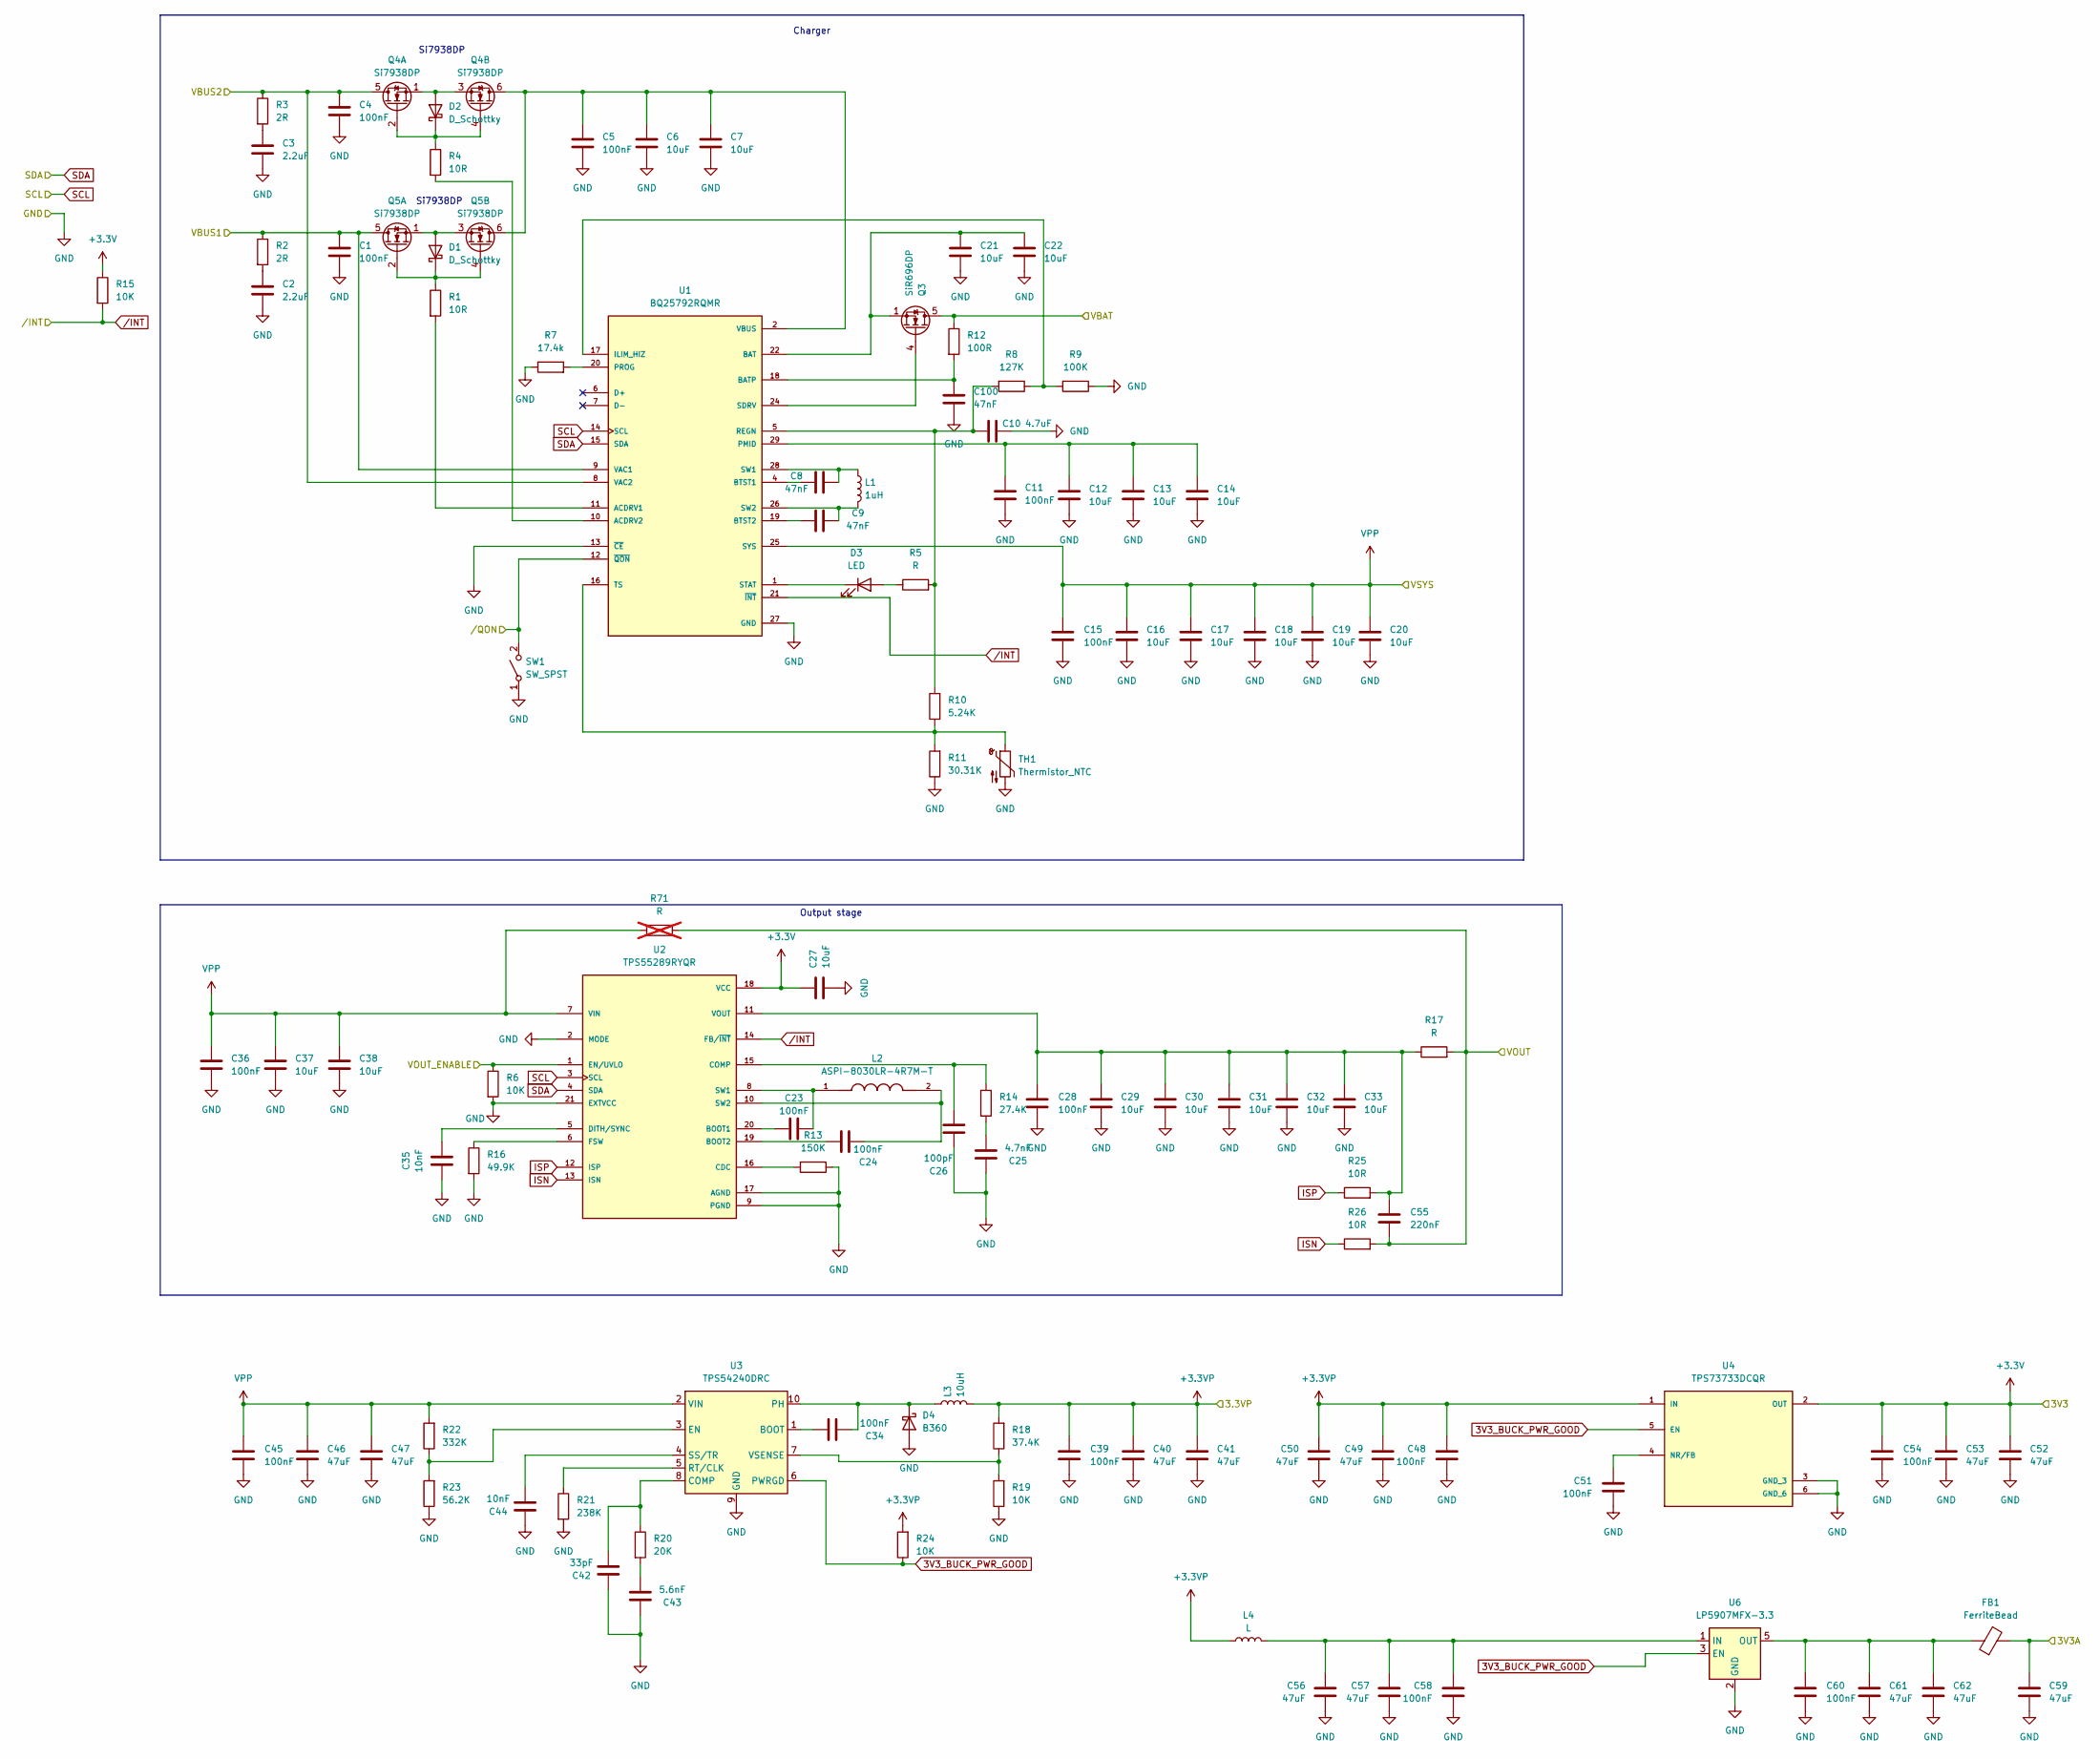
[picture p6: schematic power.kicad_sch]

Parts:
C1, C4, C5, C11, C15, C23, C24, C28, C34, C36, C39, C45, C48, C51, C54, C58, C60: 100nF; C_0402_1005Metric
C2, C3: 2.2uF; C_1206_3216Metric
C6, C7, C12, C13, C14, C16, C17, C18, C19, C20, C21, C22, C27, C29, C30, C31, C32, C33, C37, C38: 10uF; C_1206_3216Metric
C8, C9, C100: 47nF; C_0402_1005Metric
C10: 4.7uF; C_1206_3216Metric
C25: 4.7nF; C_0402_1005Metric
C26: 100pF; C_0402_1005Metric
C35, C44: 10nF; C_0402_1005Metric
C40, C41, C46, C47, C49, C50, C52, C53, C56, C57, C59, C61, C62: 47uF; C_1206_3216Metric
C42: 33pF; C_0402_1005Metric
C43: 5.6nF; C_0402_1005Metric
C55: 220nF; C_0402_1005Metric
D1, D2: D_Schottky; D_SOD-123
D3: LED; LED_0805_2012Metric
D4: B360; D_SMB
FB1: FerriteBead; L_0805_2012Metric
L1: 1uH; L_10.4x10.4_H4.8
L2: ASPI-8030LR-4R7M-T; IND_ASPI-8030LR-4R7M-T; PARTREV 6/28/2021
L3: 10uH; C_2220_5750Metric
L4: L; L_1812_4532Metric
Q3: SiR696DP; PowerPAK_SO-8_Single
Q4, Q5: Si7938DP; PowerPAK_SO-8_Dual
R1, R4, R25, R26: 10R; R_0402_1005Metric
R2, R3: 2R; R_1206_3216Metric
R5: R; R_0402_1005Metric
R6, R15, R19, R24: 10K; R_0402_1005Metric
R7: 17.4k; R_0402_1005Metric
R8: 127K; R_0402_1005Metric
R9: 100K; R_0402_1005Metric
R10: 5.24K; R_0402_1005Metric
R11: 30.31K; R_0402_1005Metric
R12: 100R; R_0402_1005Metric
R13: 150K; R_0402_1005Metric
R14: 27.4K; R_0402_1005Metric
R16: 49.9K; R_0402_1005Metric
R17: R; R_2512_6332Metric
R18: 37.4K; R_0402_1005Metric
R20: 20K; R_0402_1005Metric
R21: 238K; R_0402_1005Metric
R22: 332K; R_0402_1005Metric
R23: 56.2K; R_0402_1005Metric
R71: R; R_1206_3216Metric; not fitted
SW1: SW_SPST; SW_SPST_EVQPE1
TH1: Thermistor_NTC; R_0603_1608Metric
U1: BQ25792RQMR; QFN40P400X400X100-29N; PARTREV 11/2019
U2: TPS55289RYQR; VREG_TPS55289RYQR; PARTREV August 2022
U3: TPS54240DRC; Texas_DRC0010J_ThermalVias
U4: TPS73733DCQR; IC_TPS73733DCQR; PARTREV R
U6: LP5907MFX-3.3; SOT-23-5

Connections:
3V3_BUCK_PWR_GOOD: R24.1, U3.6 (PWRGD), U4.5 (EN), U6.3 (EN)
+3.3VP: C39.1, C40.1, C41.1, C48.1, C49.1, C50.1, L3.2, L4.1, R18.2, R24.2, U4.1 (IN); also elsewhere on the board
+BATT: Q3.5 (D), R12.1; also elsewhere on the board
/Controller/VOUT_ENABLE: R6.1, U2.1 (EN/UVLO); also elsewhere on the board
BAT: C21.1, C22.1, Q3.1 (S), Q3.2 (S), Q3.3 (S), U1.22 (BAT), U1.23 (BAT)
GND: C1.2, C2.2, C3.2, C4.2, C5.2, C6.2, C7.2, C10.2, C11.2, C12.2, C13.2, C14.2, C15.2, C16.2, C17.2, C18.2, C19.2, C20.2, C21.2, C22.2, C25.1, C26.1, C27.2, C28.2, C29.2, C30.2, C31.2, C32.2, C33.2, C35.1, C36.2, C37.2, C38.2, C39.2, C40.2, C41.2, C42.1, C43.1, C44.1, C45.2, C46.2, C47.2, C48.2, C49.2, C50.2, C51.2, C52.2, C53.2, C54.2, C56.2, C57.2, C58.2, C59.2, C60.2, C61.2, C62.2, C100.2, D4.2 (A), R6.2, R7.1, R9.1, R11.1, R13.1, R16.2, R19.1, R21.2, R23.1, SW1.1 (A), TH1.2, U1.13 (~CE), U1.27 (GND), U2.2 (MODE), U2.9 (PGND), U2.17 (AGND), U2.21 (EXTVCC), U3.9 (GND), U3.11 (GND), U4.3 (GND_3), U4.6 (GND_6), U6.2 (GND); also elsewhere on the board
INT_I2C_SCL: U1.14 (SCL), U2.3 (SCL); also elsewhere on the board
INT_I2C_SDA: U1.15 (SDA), U2.4 (SDA); also elsewhere on the board
ISN: R26.1, U2.13 (ISN)
ISP: R25.1, U2.12 (ISP)
unnamed: C2.1, R2.2
unnamed: C3.1, R3.2
unnamed: C25.2, R14.2
unnamed: C43.2, R20.2
unnamed: D1.2 (A), Q5.1 (S1), Q5.3 (S2)
unnamed: D1.1 (K), Q5.2 (G1), Q5.4 (G2), R1.1
unnamed: D2.2 (A), Q4.1 (S1), Q4.3 (S2)
unnamed: D2.1 (K), Q4.2 (G1), Q4.4 (G2), R4.1
unnamed: D3.2 (A), R5.1
unnamed: D3.1 (K), U1.1 (STAT)
unnamed: C34.1, D4.1 (K), L3.1, U3.10 (PH)
unnamed: Q3.4 (G), U1.24 (SDRV)
unnamed: R1.2, U1.11 (ACDRV1)
unnamed: R4.2, U1.10 (ACDRV2)
unnamed: C100.1, R12.2, U1.18 (BATP)
unnamed: C8.1, U1.4 (BTST1)
unnamed: C9.1, U1.19 (BTST2)
unnamed: R8.1, R9.2, U1.17 (ILIM_HIZ)
unnamed: C11.1, C12.1, C13.1, C14.1, U1.29 (PMID)
unnamed: R7.2, U1.20 (PROG)
unnamed: C10.1, R5.2, R8.2, R10.2, U1.5 (REGN)
unnamed: C8.2, L1.1, U1.28 (SW1)
unnamed: C9.2, L1.2, U1.26 (SW2)
unnamed: R10.1, R11.2, TH1.1, U1.16 (TS)
unnamed: C23.1, U2.20 (BOOT1)
unnamed: C24.2, U2.19 (BOOT2)
unnamed: R13.2, U2.16 (CDC)
unnamed: C26.2, R14.1, U2.15 (COMP)
unnamed: C35.2, U2.5 (DITH/SYNC)
unnamed: R16.1, U2.6 (FSW)
unnamed: C23.2, L2.1, U2.8 (SW1)
unnamed: C24.1, L2.2, U2.10 (SW2)
unnamed: C28.1, C29.1, C30.1, C31.1, C32.1, C33.1, C55.1, R17.1, R25.2, U2.11 (VOUT)
unnamed: C34.2, U3.1 (BOOT)
unnamed: C42.2, R20.1, U3.8 (COMP)
unnamed: R22.1, R23.2, U3.3 (EN)
unnamed: R21.1, U3.5 (RT/CLK)
unnamed: C44.2, U3.4 (SS/TR)
unnamed: R18.1, R19.2, U3.7 (VSENSE)
unnamed: C51.1, U4.4 (NR/FB)
unnamed: C56.1, C57.1, C58.1, L4.2, U6.1 (IN)
unnamed: C60.1, C61.1, C62.1, FB1.1, U6.5 (OUT)
VAA: C59.1, FB1.2; also elsewhere on the board
VBUS: C5.1, C6.1, C7.1, Q4.6 (D2), Q5.6 (D2), U1.2 (VBUS), U1.3 (VBUS)
VBUS_DOCK: C4.1, Q4.5 (D1), R3.1, U1.8 (VAC2); also elsewhere on the board
VBUS_USBC: C1.1, Q5.5 (D1), R2.1, U1.9 (VAC1); also elsewhere on the board
VCC: C27.1, C52.1, C53.1, C54.1, R15.1, U2.18 (VCC), U4.2 (OUT); also elsewhere on the board
VOUT: C55.2, R17.2, R26.2, R71.2; also elsewhere on the board
VSYS: C15.1, C16.1, C17.1, C18.1, C19.1, C20.1, C36.1, C37.1, C38.1, C45.1, C46.1, C47.1, R22.2, R71.1, U1.25 (SYS), U2.7 (VIN), U3.2 (VIN); also elsewhere on the board
/INT: R15.2, U1.21 (~INT), U2.14 (FB/~INT); also elsewhere on the board
/QON: SW1.2 (B), U1.12 (~QON); also elsewhere on the board

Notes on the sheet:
Output stage
Si7938DP
Charger

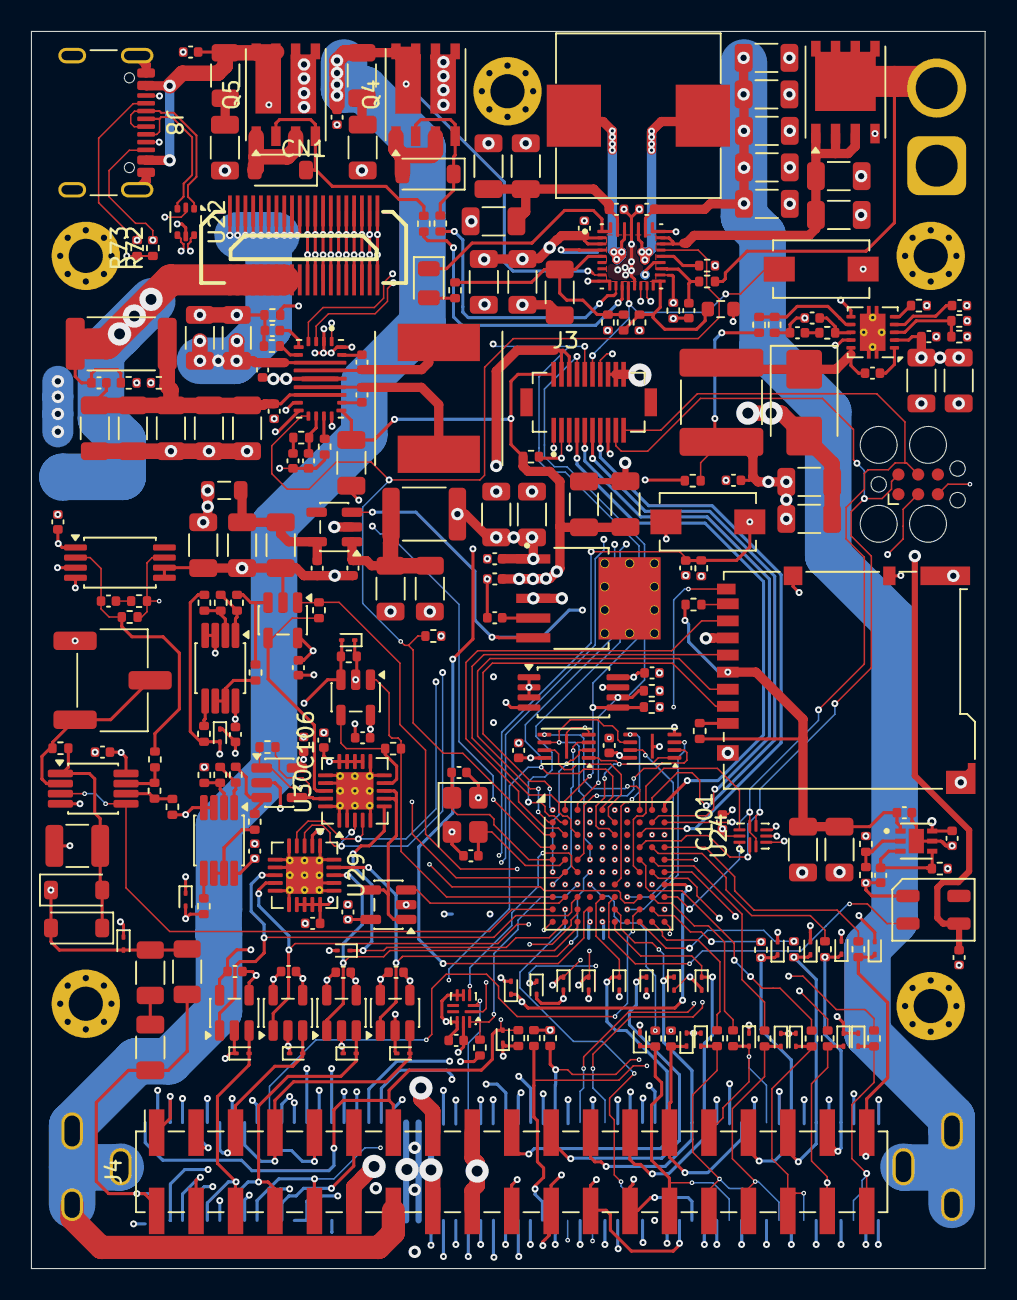
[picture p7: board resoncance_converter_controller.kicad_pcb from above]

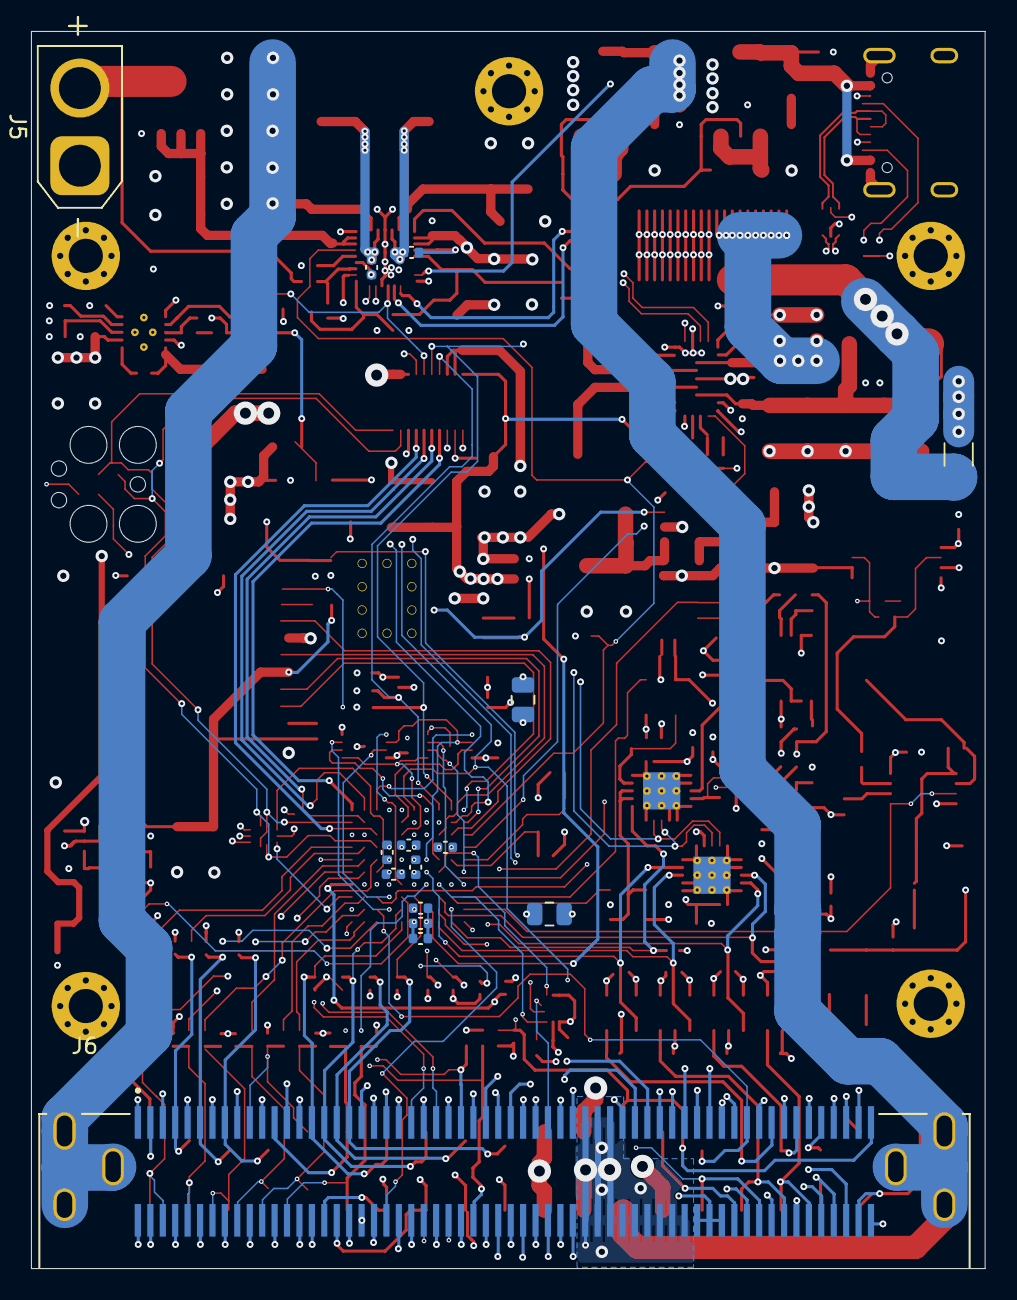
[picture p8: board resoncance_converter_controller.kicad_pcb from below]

Board: 6 copper layers, 61.4 x 79.7 mm, 270 parts (15 on the bottom side), 191 nets.

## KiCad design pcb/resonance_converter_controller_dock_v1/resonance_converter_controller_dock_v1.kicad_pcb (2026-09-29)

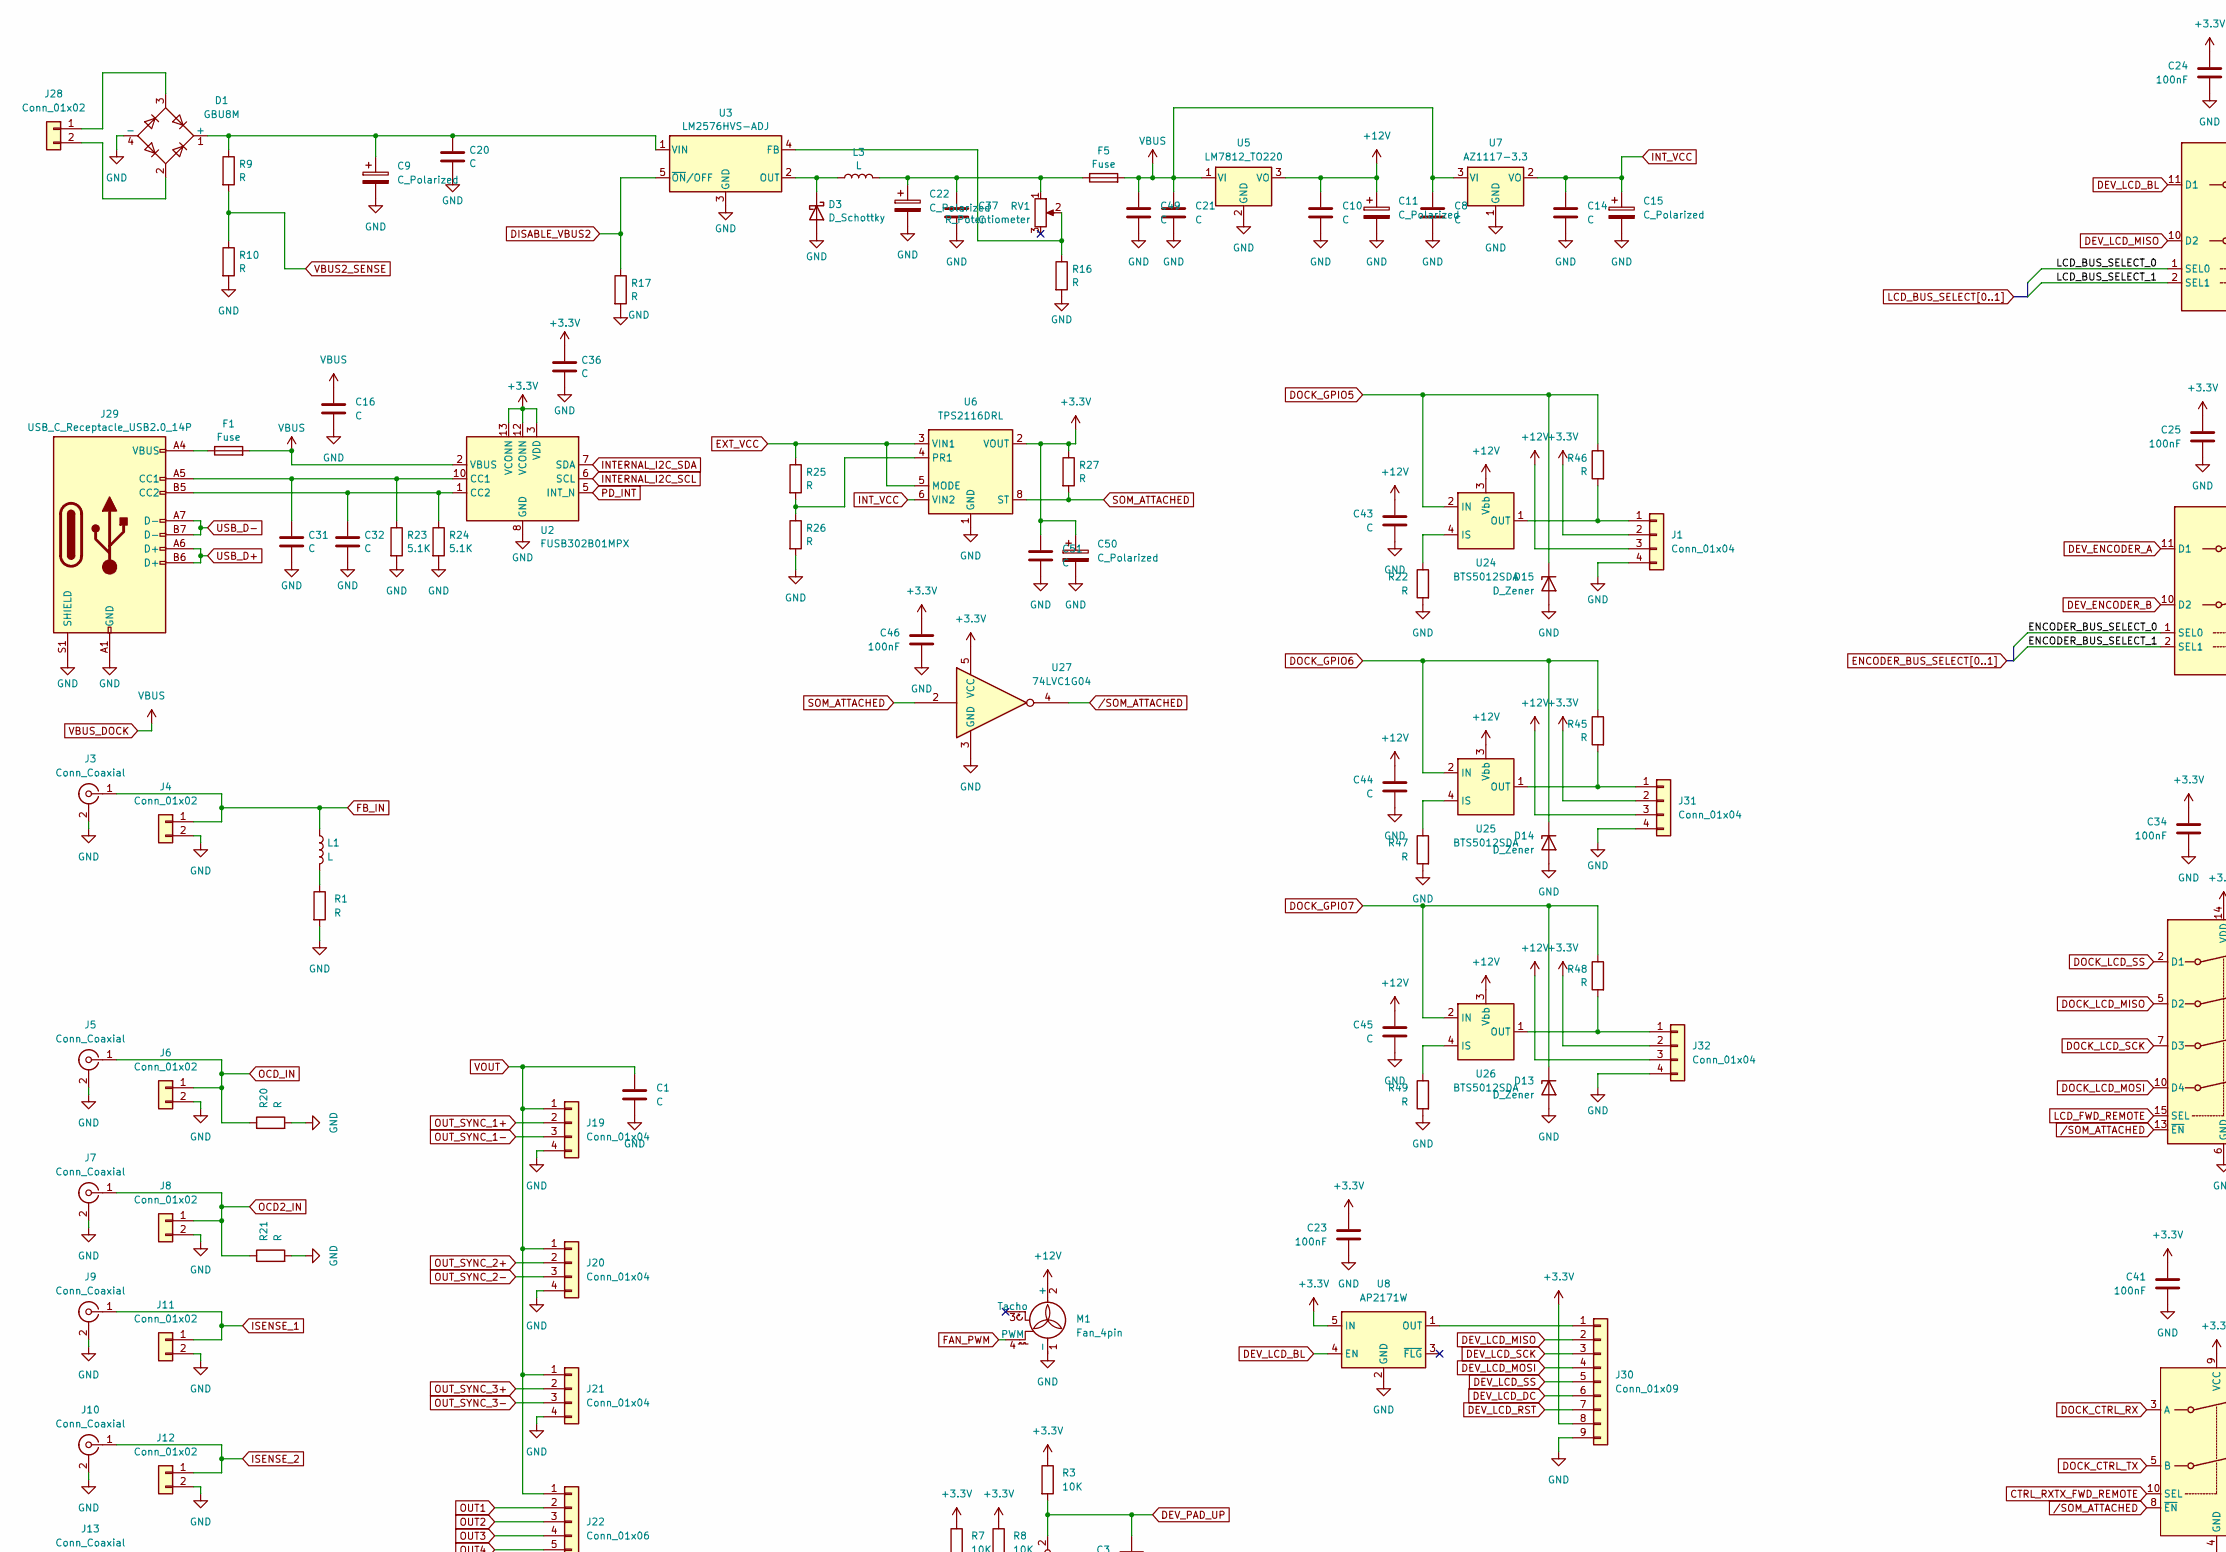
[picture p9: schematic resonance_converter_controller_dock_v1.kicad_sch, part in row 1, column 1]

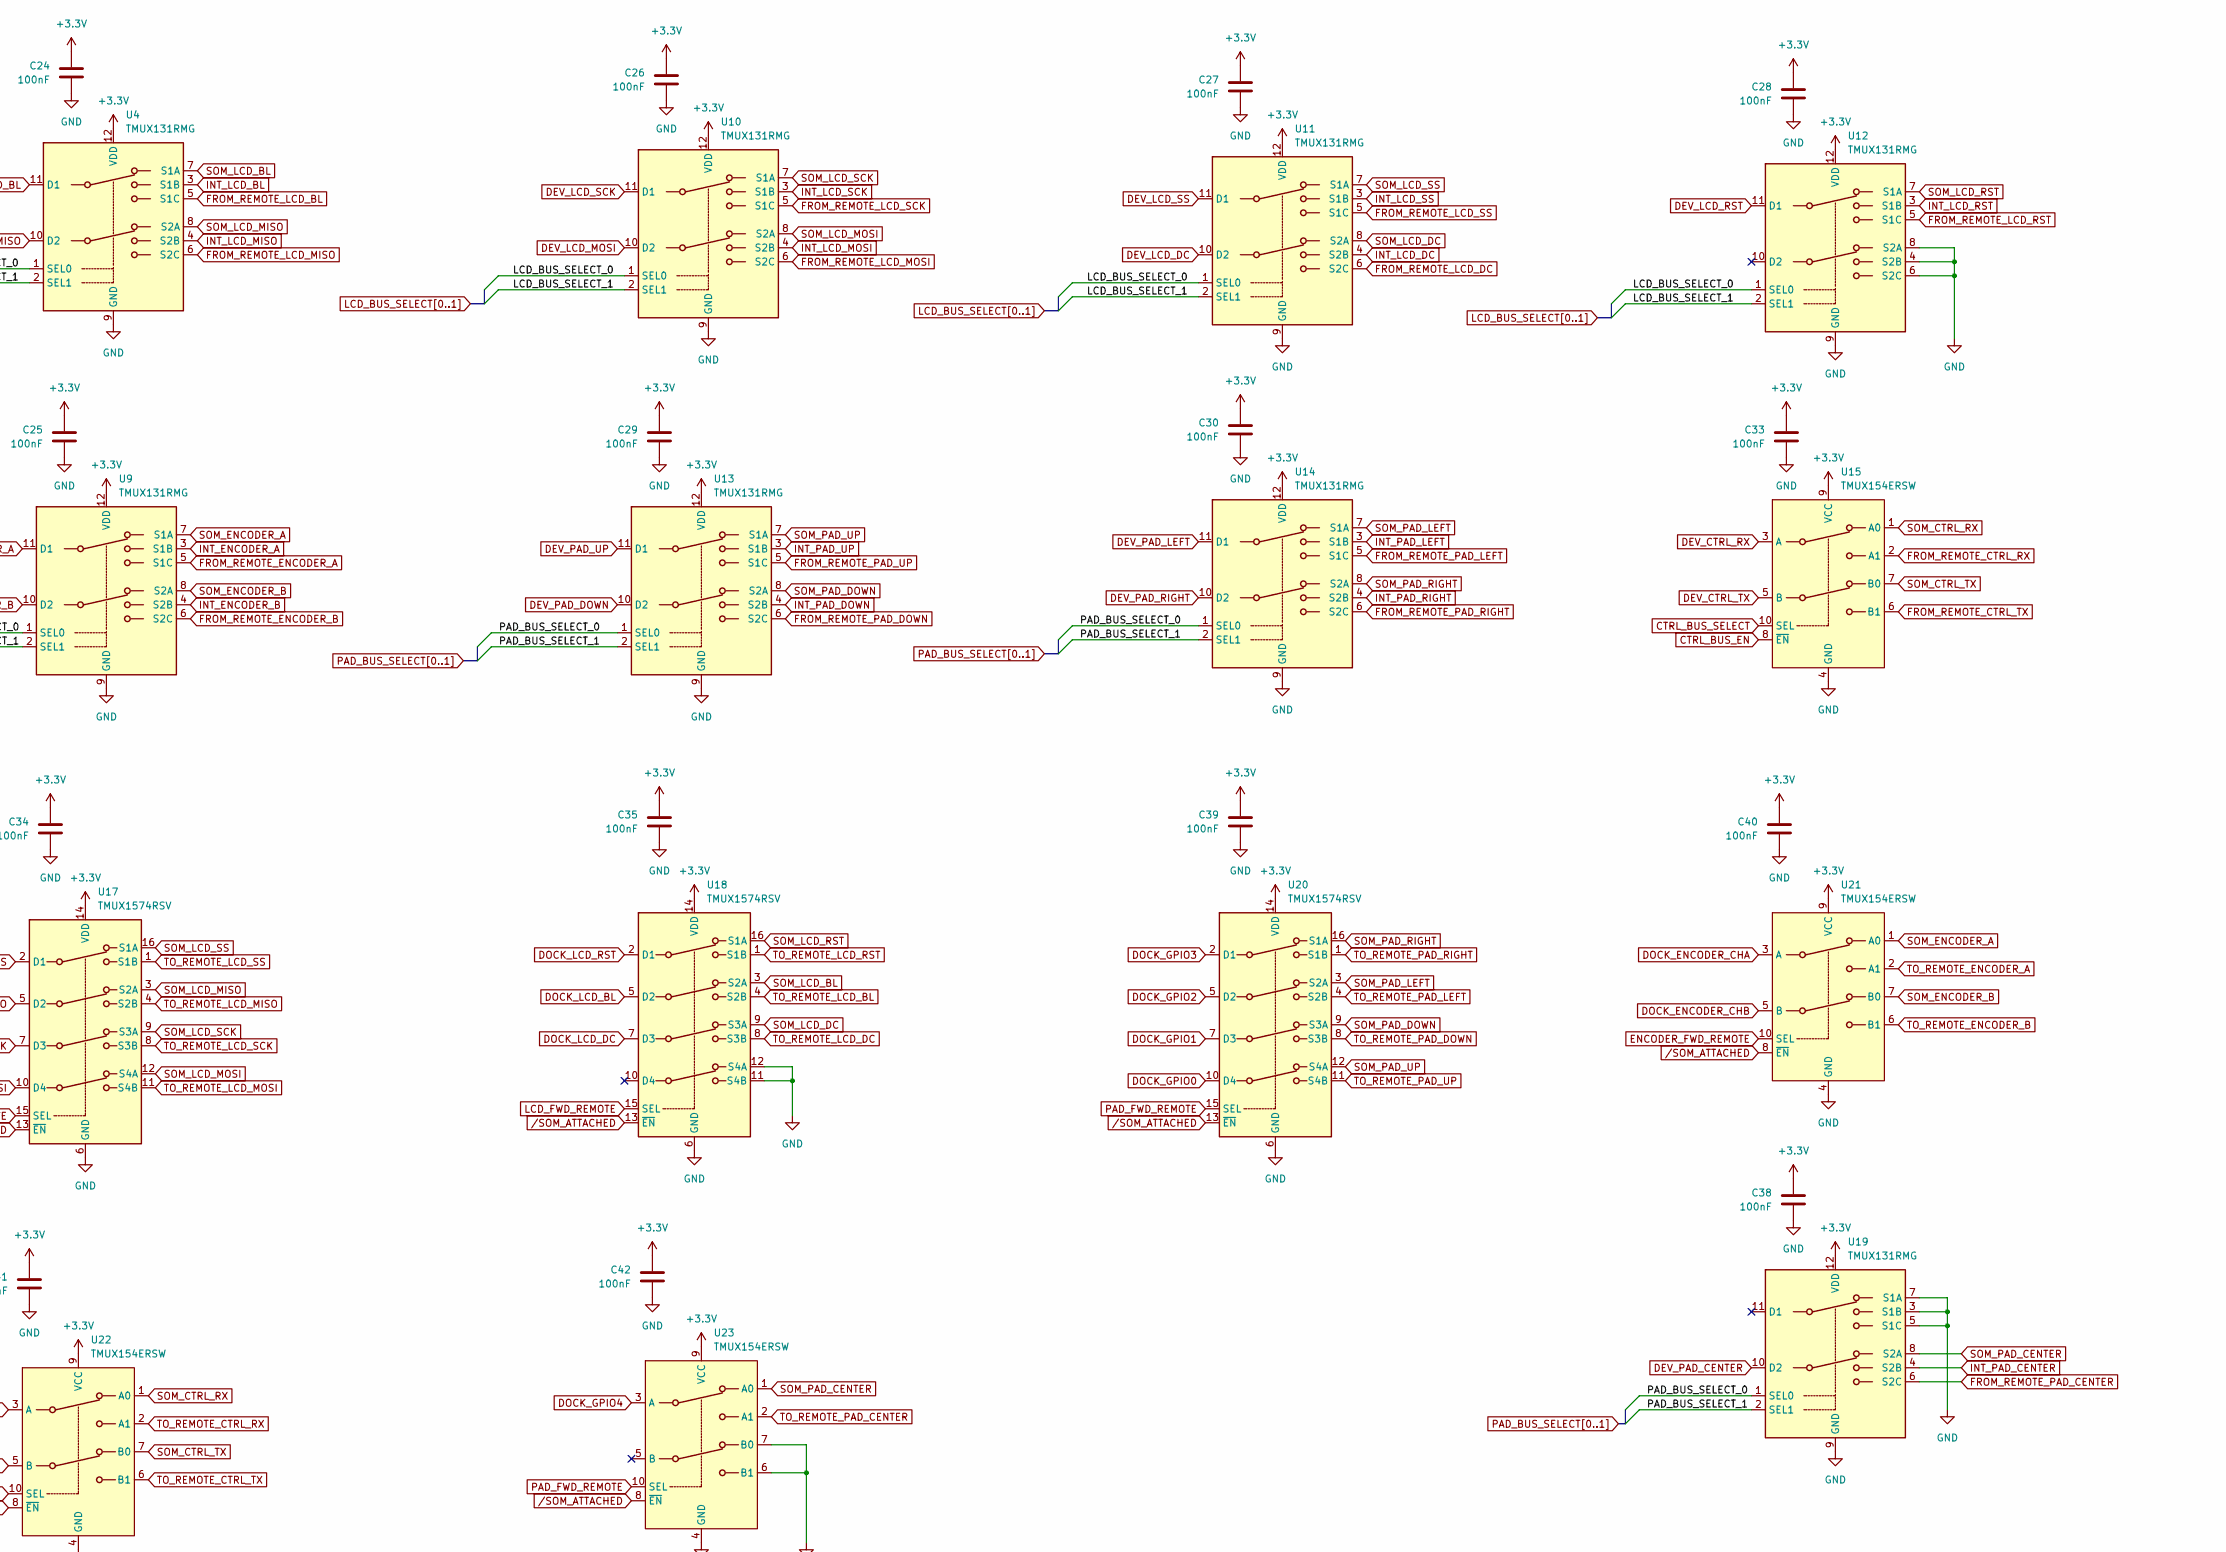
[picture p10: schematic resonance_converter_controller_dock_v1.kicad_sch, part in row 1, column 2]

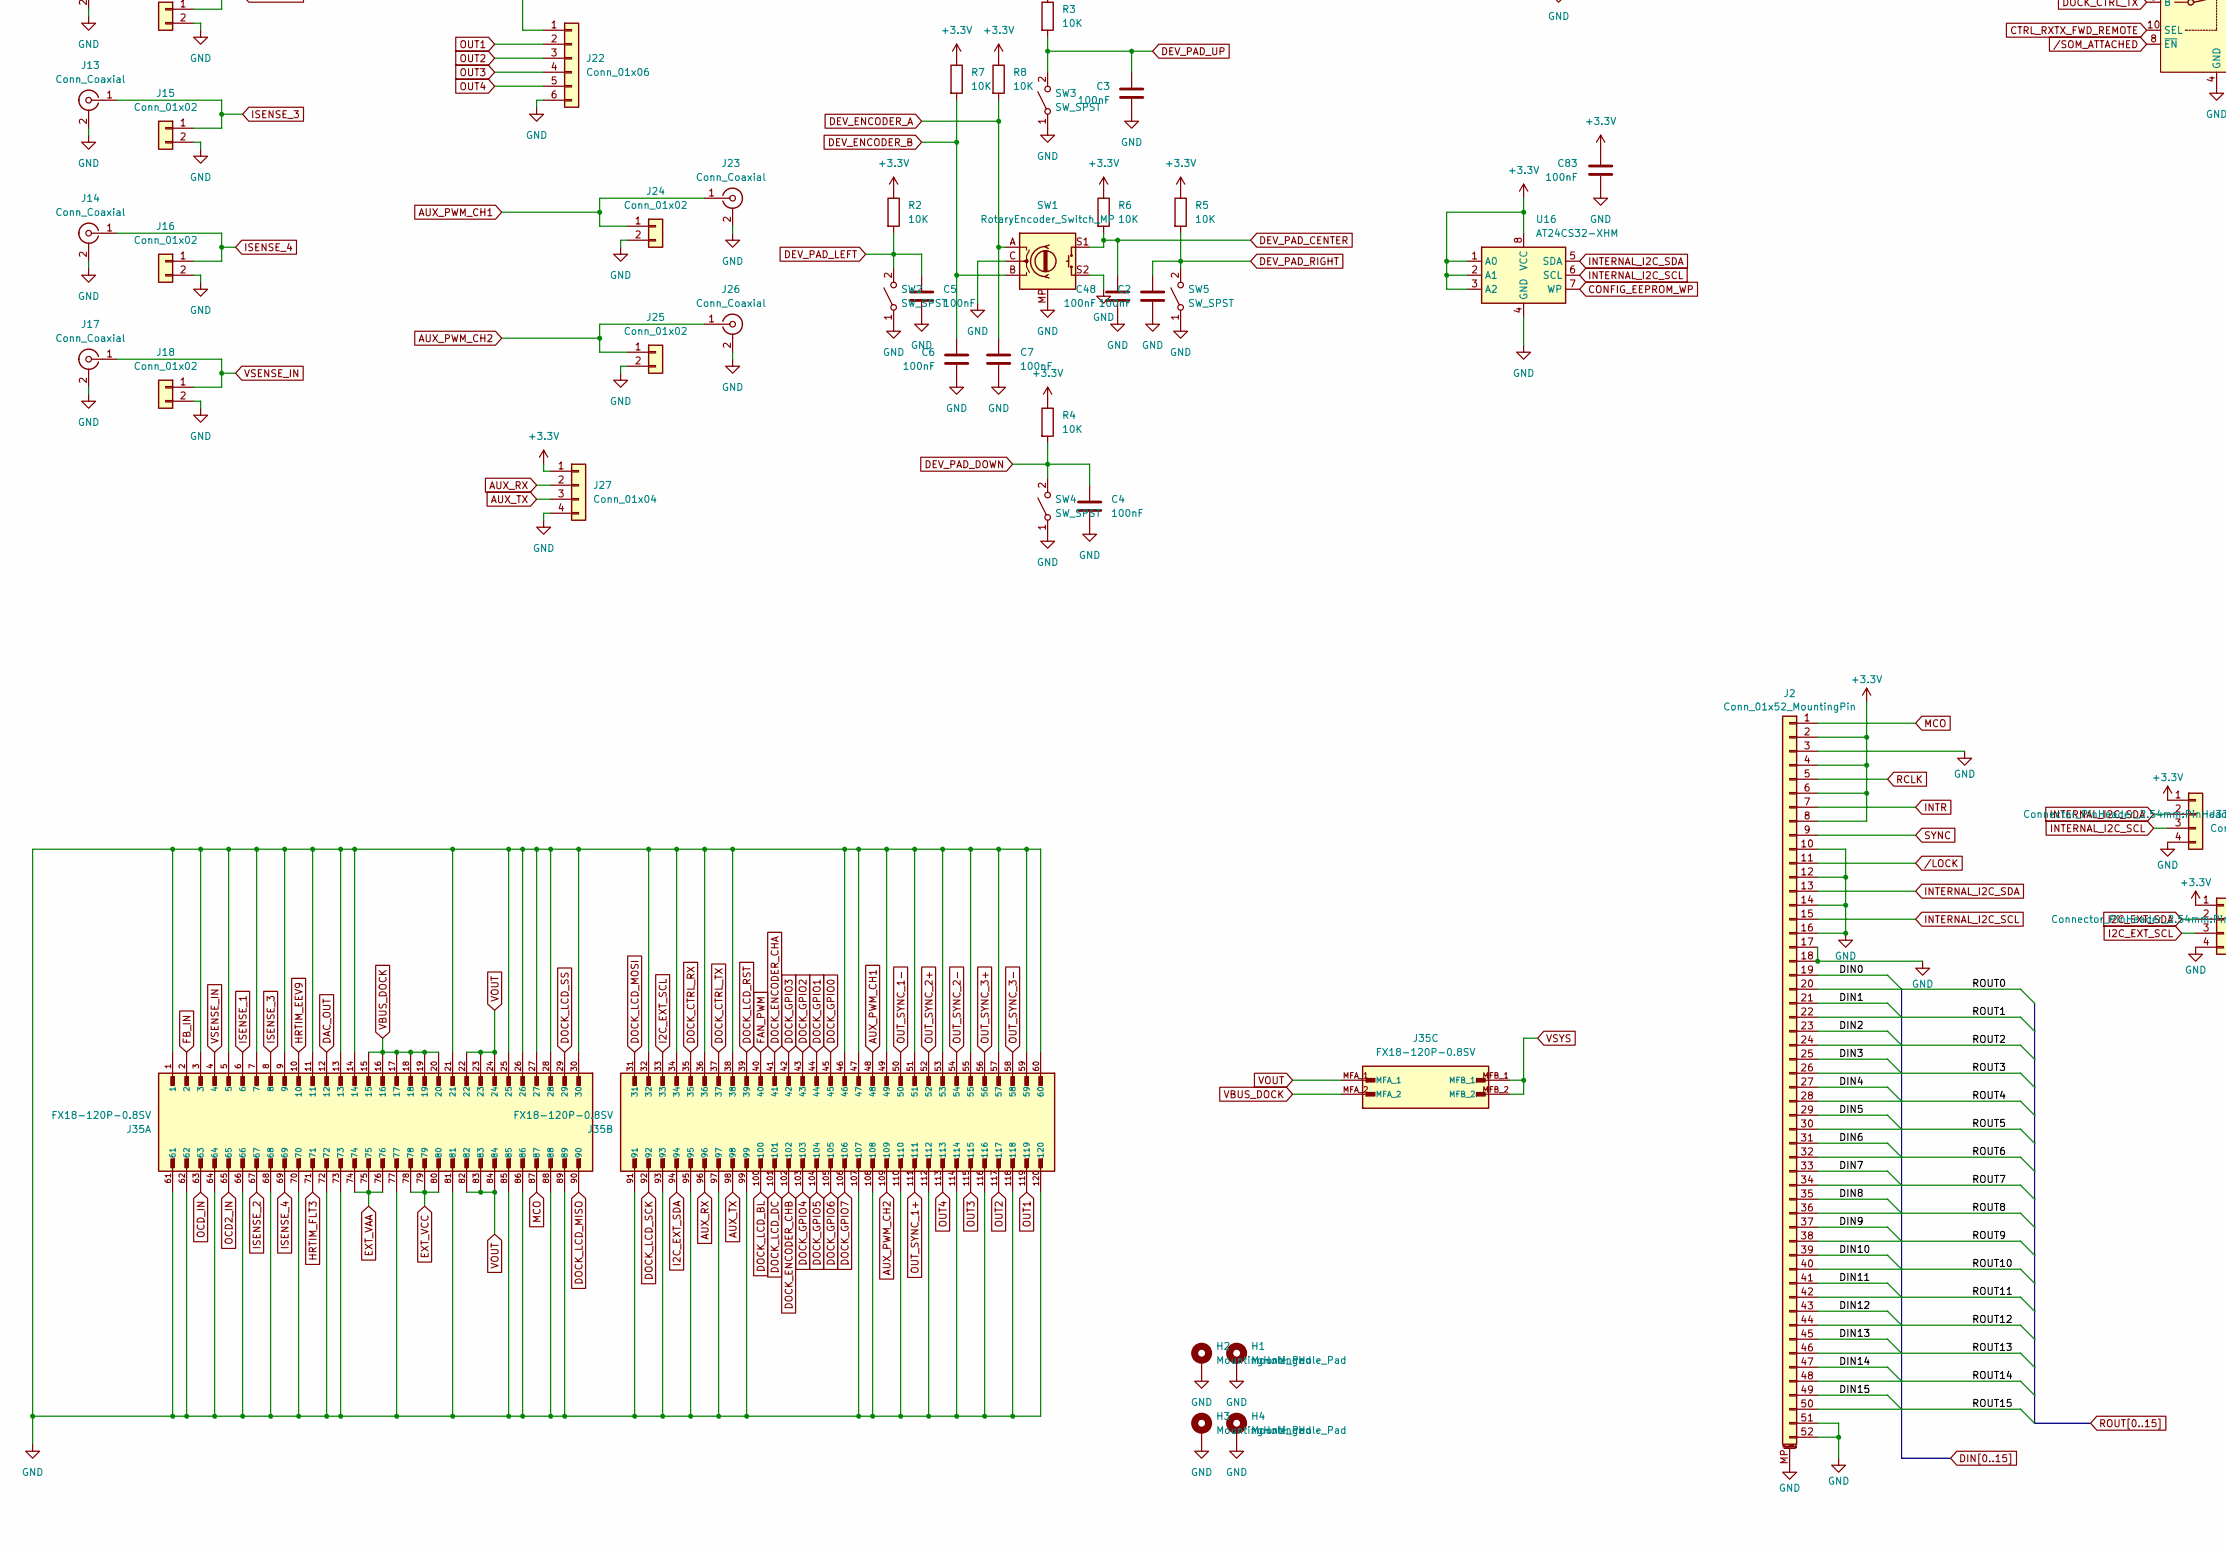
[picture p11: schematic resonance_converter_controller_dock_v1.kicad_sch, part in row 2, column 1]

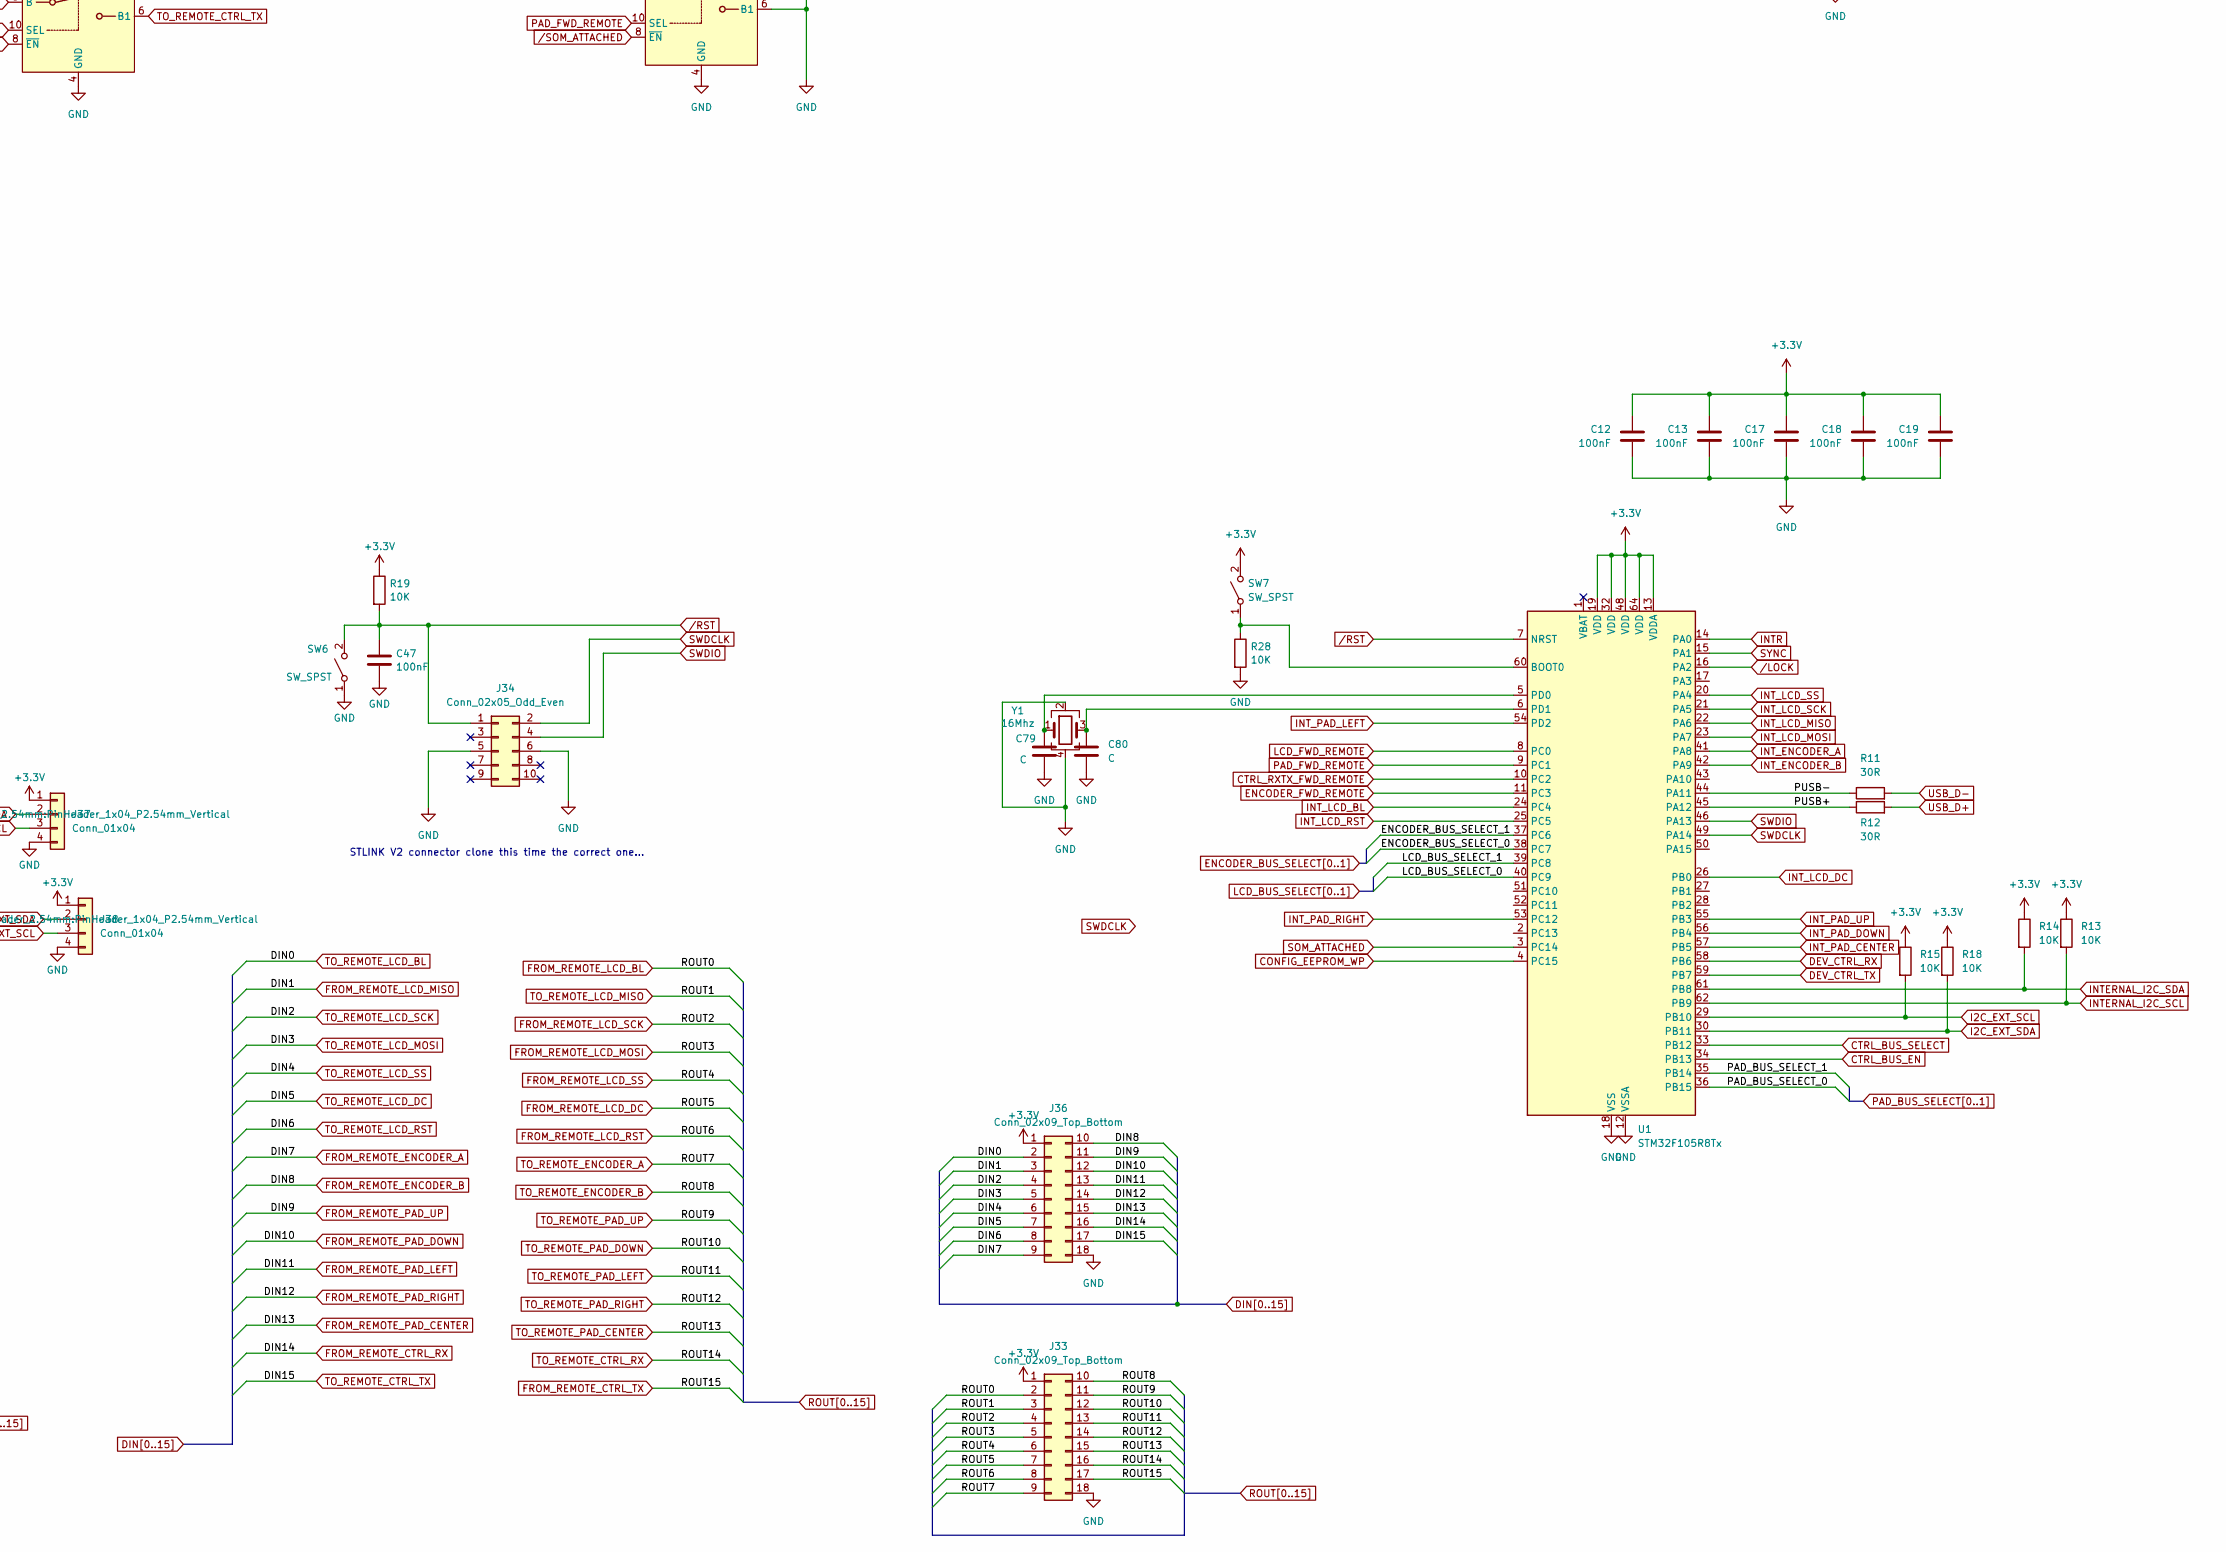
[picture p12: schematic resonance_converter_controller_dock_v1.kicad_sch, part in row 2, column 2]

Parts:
C1, C16, C37, C49, C51: C; C_2220_5750Metric
C2, C3, C4, C5, C6, C7, C12, C13, C17, C18, C19, C23, C24, C25, C26, C27, C28, C29, C30, C33, C34, C35, C38, C39, C40, C41, C42, C46, C47, C48, C83: 100nF; C_0402_1005Metric
C8, C10, C14, C20, C21, C31, C32, C36, C43, C44, C45, C79, C80: C; C_0402_1005Metric
C9, C22: C_Polarized; CP_Radial_D30.0mm_P10.00mm_SnapIn
C11, C15, C50: C_Polarized; CP_Radial_D10.0mm_P5.00mm_P7.50mm
D1: GBU8M; Diode_Bridge_Vishay_GBU
D3: D_Schottky; D_SMB
D13, D14, D15: D_Zener; D_SOD-323
F1, F5: Fuse; Fuse_0805_2012Metric
H1, H2, H3, H4: MountingHole_Pad; MountingHole_3.2mm_M3_Pad_Via
J1, J19, J20, J21, J27, J31, J32: Conn_01x04; JST_PH_S4B-PH-K_1x04_P2.00mm_Horizontal
J2: Conn_01x52_MountingPin; BUS_PCI_Express_Mini_Full
J3, J5, J7, J9, J10, J13, J14, J17, J23, J26: Conn_Coaxial; SMA_Amphenol_901-143_Horizontal
J4, J6, J8, J11, J12, J15, J16, J18, J24, J25, J28: Conn_01x02; PhoenixContact_MCV_1,5_2-G-5.08_1x02_P5.08mm_Vertical
J22: Conn_01x06; JST_PH_S6B-PH-K_1x06_P2.00mm_Horizontal
J29: USB_C_Receptacle_USB2.0_14P; USB_C_Receptacle_G-Switch_GT-USB-7010ASV
J30: Conn_01x09; JST_XH_B9B-XH-AM_1x09_P2.50mm_Vertical
J33, J36: Conn_02x09_Top_Bottom; PinHeader_2x09_P2.54mm_Vertical
J34: Conn_02x05_Odd_Even; IDC-Header_2x05_P2.54mm_Vertical
J35: FX18-120P-0.8SV; HIROSE_FX18-120P-0.8SV; PARTREV 11.07.21
J37, J38: Conn_01x04; PinHeader_1x04_P2.54mm_Vertical
L1: L; L_Radial_D10.0mm_P5.00mm_Neosid_SD12k_style3
L3: L; L_Bourns_SRP1038C_10.0x10.0mm
M1: Fan_4pin; FanPinHeader_1x04_P2.54mm_Vertical
R1, R20, R21: R; R_Axial_Power_L20.0mm_W6.4mm_P22.40mm
R2, R3, R4, R5, R6, R7, R8, R13, R14, R15, R18, R19, R28: 10K; R_0402_1005Metric
R9, R10, R16, R17, R22, R25, R26, R27, R45, R46, R47, R48, R49: R; R_0402_1005Metric
R11, R12: 30R; R_0402_1005Metric
R23, R24: 5.1K; R_0402_1005Metric
RV1: R_Potentiometer; Potentiometer_Bourns_3269W_Vertical
SW1: RotaryEncoder_Switch_MP; RotaryEncoder_Alps_EC11E-Switch_Vertical_H20mm_MountingHoles
SW2, SW3, SW4, SW5: SW_SPST; SW_Cherry_MX_1.00u_PCB
SW6: SW_SPST; SW_SPST_B3S-1000
SW7: SW_SPST; SW_SPST_EVQPE1
U1: STM32F105R8Tx; LQFP-64_10x10mm_P0.5mm
U2: FUSB302B01MPX; WQFN-14-1EP_2.5x2.5mm_P0.5mm_EP1.45x1.45mm
U3: LM2576HVS-ADJ; TO-263-5_TabPin3
U4, U9, U10, U11, U12, U13, U14, U19: TMUX131RMG; Texas_RMG0012A_WQFN-12_1.8x1.8mm_P0.4mm
U5: LM7812_TO220; TO-263-2
U6: TPS2116DRL; SOT-583-8
U7: AZ1117-3.3; TO-263-2
U8: AP2171W; SOT-23-5
U15, U21, U22, U23: TMUX154ERSW; UQFN-10_1.4x1.8mm_P0.4mm
U16: AT24CS32-XHM; TSSOP-8_4.4x3mm_P0.65mm
U17, U18, U20: TMUX1574RSV; UQFN-16_1.8x2.6mm_P0.4mm
U24, U25, U26: BTS5012SDA; TO-252-4
U27: 74LVC1G04; Texas_R-PDSO-G5_DCK-5
Y1: 16Mhz; Crystal_SMD_3225-4Pin_3.2x2.5mm

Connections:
+3.3V: C12.1, C13.1, C17.1, C18.1, C19.1, C23.1, C24.1, C25.1, C26.1, C27.1, C28.1, C29.1, C30.1, C33.1, C34.1, C35.1, C36.1, C38.1, C39.1, C40.1, C41.1, C42.1, C46.1, C50.1, C51.1, C83.1, J1.2, J2.2, J2.4, J2.6, J2.8, J27.1, J30.8, J31.2, J32.2, J33.1, J36.1, J37.1, J38.1, R2.1, R3.1, R4.1, R5.1, R6.1, R7.1, R8.1, R13.1, R14.1, R15.1, R18.1, R19.1, R27.1, SW7.2 (B), U1.13 (VDDA), U1.19 (VDD), U1.32 (VDD), U1.48 (VDD), U1.64 (VDD), U2.3 (VDD), U2.4 (VDD), U2.12 (VCONN), U2.13 (VCONN), U4.12 (VDD), U6.2 (VOUT), U6.7 (VOUT), U8.5 (IN), U9.12 (VDD), U10.12 (VDD), U11.12 (VDD), U12.12 (VDD), U13.12 (VDD), U14.12 (VDD), U15.9 (VCC), U16.1 (A0), U16.2 (A1), U16.3 (A2), U16.8 (VCC), U17.14 (VDD), U18.14 (VDD), U19.12 (VDD), U20.14 (VDD), U21.9 (VCC), U22.9 (VCC), U23.9 (VCC), U27.5 (VCC)
+12V: C10.1, C11.1, C43.1, C44.1, C45.1, J1.3, J31.3, J32.3, M1.2 (+), U5.3 (VO), U24.3 (Vbb), U25.3 (Vbb), U26.3 (Vbb)
/ENCODER_BUS_SELECT_0: U1.38 (PC7), U9.1 (SEL0)
/ENCODER_BUS_SELECT_1: U1.37 (PC6), U9.2 (SEL1)
/LCD_BUS_SELECT_0: U1.40 (PC9), U4.1 (SEL0), U10.1 (SEL0), U11.1 (SEL0), U12.1 (SEL0)
/LCD_BUS_SELECT_1: U1.39 (PC8), U4.2 (SEL1), U10.2 (SEL1), U11.2 (SEL1), U12.2 (SEL1)
/PAD_BUS_SELECT_0: U1.36 (PB15), U13.1 (SEL0), U14.1 (SEL0), U19.1 (SEL0)
/PAD_BUS_SELECT_1: U1.35 (PB14), U13.2 (SEL1), U14.2 (SEL1), U19.2 (SEL1)
/PUSB+: R12.1, U1.45 (PA12)
/PUSB-: R11.1, U1.44 (PA11)
AUX_PWM_CH1: J23.1 (In), J24.1, J35.48
AUX_PWM_CH2: J25.1, J26.1 (In), J35.109
AUX_RX: J27.2, J35.96
AUX_TX: J27.3, J35.98
CONFIG_EEPROM_WP: U1.4 (PC15), U16.7 (WP)
CTRL_BUS_EN: U1.34 (PB13), U15.8 (~EN)
CTRL_BUS_SELECT: U1.33 (PB12), U15.10 (SEL)
CTRL_RXTX_FWD_REMOTE: U1.10 (PC2), U22.10 (SEL)
DAC_OUT: J35.12
DEV_CTRL_RX: U1.58 (PB6), U15.3 (A)
DEV_CTRL_TX: U1.59 (PB7), U15.5 (B)
DEV_ENCODER_A: C7.1, R8.2, SW1.A, U9.11 (D1)
DEV_ENCODER_B: C6.1, R7.2, SW1.B, U9.10 (D2)
DEV_LCD_BL: U4.11 (D1), U8.4 (EN)
DEV_LCD_DC: J30.6, U11.10 (D2)
DEV_LCD_MISO: J30.2, U4.10 (D2)
DEV_LCD_MOSI: J30.4, U10.10 (D2)
DEV_LCD_RST: J30.7, U12.11 (D1)
DEV_LCD_SCK: J30.3, U10.11 (D1)
DEV_LCD_SS: J30.5, U11.11 (D1)
DEV_PAD_CENTER: C48.1, R6.2, SW1.S1, U19.10 (D2)
DEV_PAD_DOWN: C4.1, R4.2, SW4.2 (B), U13.10 (D2)
DEV_PAD_LEFT: C5.1, R2.2, SW2.2 (B), U14.11 (D1)
DEV_PAD_RIGHT: C2.1, R5.2, SW5.2 (B), U14.10 (D2)
DEV_PAD_UP: C3.1, R3.2, SW3.2 (B), U13.11 (D1)
DISABLE_VBUS2: R17.1, U3.5 (~ON/OFF)
DOCK_CTRL_RX: J35.35, U22.3 (A)
DOCK_CTRL_TX: J35.37, U22.5 (B)
DOCK_ENCODER_CHA: J35.41, U21.3 (A)
DOCK_ENCODER_CHB: J35.102, U21.5 (B)
DOCK_GPIO0: J35.45, U20.10 (D4)
DOCK_GPIO1: J35.44, U20.7 (D3)
DOCK_GPIO2: J35.43, U20.5 (D2)
DOCK_GPIO3: J35.42, U20.2 (D1)
DOCK_GPIO4: J35.103, U23.3 (A)
DOCK_GPIO5: D15.1 (K), J35.104, R46.1, U24.2 (IN)
DOCK_GPIO6: D14.1 (K), J35.105, R45.1, U25.2 (IN)
DOCK_GPIO7: D13.1 (K), J35.106, R48.1, U26.2 (IN)
DOCK_LCD_BL: J35.100, U18.5 (D2)
DOCK_LCD_DC: J35.101, U18.7 (D3)
DOCK_LCD_MISO: J35.90, U17.5 (D2)
DOCK_LCD_MOSI: J35.31, U17.10 (D4)
DOCK_LCD_RST: J35.39, U18.2 (D1)
DOCK_LCD_SCK: J35.92, U17.7 (D3)
DOCK_LCD_SS: J35.29, U17.2 (D1)
ENCODER_FWD_REMOTE: U1.11 (PC3), U21.10 (SEL)
EXT_VAA: J35.74, J35.75, J35.76
EXT_VCC: J35.78, J35.79, J35.80, R25.1, U6.3 (VIN1), U6.5 (MODE)
FAN_PWM: J35.40, M1.4 (PWM)
FB_IN: J3.1 (In), J4.1, J35.2, L1.1
FROM_REMOTE_CTRL_RX: J2.47, J36.16, U15.2 (A1)
FROM_REMOTE_CTRL_TX: J2.50, J33.17, U15.6 (B1)
FROM_REMOTE_ENCODER_A: J2.33, J36.9, U9.5 (S1C)
FROM_REMOTE_ENCODER_B: J2.35, J36.10, U9.6 (S2C)
FROM_REMOTE_LCD_BL: J2.20, J33.2, U4.5 (S1C)
FROM_REMOTE_LCD_DC: J2.30, J33.7, U11.6 (S2C)
FROM_REMOTE_LCD_MISO: J2.21, J36.3, U4.6 (S2C)
FROM_REMOTE_LCD_MOSI: J2.26, J33.5, U10.6 (S2C)
FROM_REMOTE_LCD_RST: J2.32, J33.8, U12.5 (S1C)
FROM_REMOTE_LCD_SCK: J2.24, J33.4, U10.5 (S1C)
FROM_REMOTE_LCD_SS: J2.28, J33.6, U11.5 (S1C)
FROM_REMOTE_PAD_CENTER: J2.45, J36.15, U19.6 (S2C)
FROM_REMOTE_PAD_DOWN: J2.39, J36.12, U13.6 (S2C)
FROM_REMOTE_PAD_LEFT: J2.41, J36.13, U14.5 (S1C)
FROM_REMOTE_PAD_RIGHT: J2.43, J36.14, U14.6 (S2C)
FROM_REMOTE_PAD_UP: J2.37, J36.11, U13.5 (S1C)
GND: C1.2, C2.2, C3.2, C4.2, C5.2, C6.2, C7.2, C8.2, C9.2, C10.2, C11.2, C12.2, C13.2, C14.2, C15.2, C16.2, C17.2, C18.2, C19.2, C20.2, C21.2, C22.2, C23.2, C24.2, C25.2, C26.2, C27.2, C28.2, C29.2, C30.2, C31.2, C32.2, C33.2, C34.2, C35.2, C36.2, C37.2, C38.2, C39.2, C40.2, C41.2, C42.2, C43.2, C44.2, C45.2, C46.2, C47.2, C48.2, C49.2, C50.2, C51.2, C79.2, C80.2, C83.2, D1.4 (-), D3.2 (A), D13.2 (A), D14.2 (A), D15.2 (A), H1.1, H2.1, H3.1, H4.1, J1.4, J2.3, J2.10, J2.12, J2.14, J2.16, J2.17, J2.18, J2.51, J2.52, J2.MP (MountPin), J3.2 (Ext), J4.2, J5.2 (Ext), J6.2, J7.2 (Ext), J8.2, J9.2 (Ext), J10.2 (Ext), J11.2, J12.2, J13.2 (Ext), J14.2 (Ext), J15.2, J16.2, J17.2 (Ext), J18.2, J19.4, J20.4, J21.4, J22.6, J23.2 (Ext), J24.2, J25.2, J26.2 (Ext), J27.4, J29.A1 (GND), J29.A12 (GND), J29.B1 (GND), J29.B12 (GND), J29.S1 (SHIELD), J30.9, J31.4, J32.4, J33.18, J34.5, J34.6, J35.1, J35.3, J35.5, J35.7, J35.9, J35.11, J35.13, J35.14, J35.21, J35.25, J35.26, J35.27, J35.28, J35.30, J35.32, J35.34, J35.36, J35.38, J35.46, J35.47, J35.49, J35.51, J35.53, J35.55, J35.57, J35.59, J35.60, J35.61, J35.62, J35.64, J35.66, J35.68, J35.70, J35.72, J35.73, J35.77, J35.81, J35.85, J35.86, J35.88, J35.89, J35.91, J35.93, J35.95, J35.97, J35.99, J35.107, J35.108, J35.110, J35.112, J35.114, J35.116, J35.118, J35.120, J36.18, J37.4, J38.4, M1.1 (-), R1.2, R10.2, R16.2, R17.2, R20.2, R21.2, R22.2, R23.2, R24.2, R26.2, R28.2, R47.2, R49.2, SW1.C, SW1.MP, SW1.S2, SW2.1 (A), SW3.1 (A), SW4.1 (A), SW5.1 (A), SW6.1 (A), U1.12 (VSSA), U1.18 (VSS), U1.31 (VSS), U1.47 (VSS), U1.63 (VSS), U2.8 (GND), U2.9 (GND), U2.15 (GND), U3.3 (GND), U4.9 (GND), U5.2 (GND), U6.1 (GND), U7.1 (GND), U8.2 (GND), U9.9 (GND), U10.9 (GND), U11.9 (GND), U12.4 (S2B), U12.6 (S2C), U12.8 (S2A), U12.9 (GND), U13.9 (GND), U14.9 (GND), U15.4 (GND), U16.4 (GND), U17.6 (GND), U18.6 (GND), U18.11 (S4B), U18.12 (S4A), U19.3 (S1B), U19.5 (S1C)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
HRTIM_EEV9: J35.10
HRTIM_FLT3: J35.71
I2C_EXT_SCL: J35.33, J38.3, R15.2, U1.29 (PB10)
I2C_EXT_SDA: J35.94, J38.2, R18.2, U1.30 (PB11)
INTERNAL_I2C_SCL: J2.15, J37.3, R13.2, U1.62 (PB9), U2.6 (SCL), U16.6 (SCL)
INTERNAL_I2C_SDA: J2.13, J37.2, R14.2, U1.61 (PB8), U2.7 (SDA), U16.5 (SDA)
INTR: J2.7, U1.14 (PA0)
INT_ENCODER_A: U1.41 (PA8), U9.3 (S1B)
INT_ENCODER_B: U1.42 (PA9), U9.4 (S2B)
INT_LCD_BL: U1.24 (PC4), U4.3 (S1B)
INT_LCD_DC: U1.26 (PB0), U11.4 (S2B)
INT_LCD_MISO: U1.22 (PA6), U4.4 (S2B)
INT_LCD_MOSI: U1.23 (PA7), U10.4 (S2B)
INT_LCD_RST: U1.25 (PC5), U12.3 (S1B)
INT_LCD_SCK: U1.21 (PA5), U10.3 (S1B)
INT_LCD_SS: U1.20 (PA4), U11.3 (S1B)
INT_PAD_CENTER: U1.57 (PB5), U19.4 (S2B)
INT_PAD_DOWN: U1.56 (PB4), U13.4 (S2B)
INT_PAD_LEFT: U1.54 (PD2), U14.3 (S1B)
INT_PAD_RIGHT: U1.53 (PC12), U14.4 (S2B)
INT_PAD_UP: U1.55 (PB3), U13.3 (S1B)
INT_VCC: C14.1, C15.1, U6.6 (VIN2), U7.2 (VO)
ISENSE_1: J9.1 (In), J11.1, J35.6
ISENSE_2: J10.1 (In), J12.1, J35.67
ISENSE_3: J13.1 (In), J15.1, J35.8
ISENSE_4: J14.1 (In), J16.1, J35.69
LCD_FWD_REMOTE: U1.8 (PC0), U17.15 (SEL), U18.15 (SEL)
MCO: J2.1, J35.87
unnamed: C22.1, C37.1, F5.1, L3.2, RV1.1
unnamed: C9.1, C20.1, D1.1 (+), R9.1, U3.1 (VIN)
unnamed: D3.1 (K), L3.1, U3.2 (OUT)
unnamed: F1.1, J29.A4 (VBUS), J29.A9 (VBUS), J29.B4 (VBUS), J29.B9 (VBUS)
unnamed: J1.1, R46.2, U24.1 (OUT), U24.5 (OUT)
unnamed: D1.3, J28.1
unnamed: D1.2, J28.2
unnamed: C31.1, J29.A5 (CC1), R23.1, U2.10 (CC1), U2.11 (CC1)
unnamed: C32.1, J29.B5 (CC2), R24.1, U2.1 (CC2), U2.14 (CC2)
unnamed: J30.1, U8.1 (OUT)
unnamed: J31.1, R45.2, U25.1 (OUT), U25.5 (OUT)
unnamed: J32.1, R48.2, U26.1 (OUT), U26.5 (OUT)
unnamed: L1.2, R1.1
unnamed: R28.1, SW7.1 (A), U1.60 (BOOT0)
unnamed: C79.1, U1.5 (PD0), Y1.1
unnamed: C80.1, U1.6 (PD1), Y1.3
unnamed: R16.1, RV1.2, U3.4 (FB)
unnamed: R25.2, R26.1, U6.4 (PR1)
unnamed: R22.1, U24.4 (IS)
unnamed: R47.1, U25.4 (IS)
unnamed: R49.1, U26.4 (IS)
OCD2_IN: J7.1 (In), J8.1, J35.65, R21.1
OCD_IN: J5.1 (In), J6.1, J35.63, R20.1
OUT1: J22.2, J35.119
OUT2: J22.3, J35.117
OUT3: J22.4, J35.115
OUT4: J22.5, J35.113
OUT_SYNC_1+: J19.2, J35.111
OUT_SYNC_1-: J19.3, J35.50
OUT_SYNC_2+: J20.2, J35.52
OUT_SYNC_2-: J20.3, J35.54
OUT_SYNC_3+: J21.2, J35.56
OUT_SYNC_3-: J21.3, J35.58
PAD_FWD_REMOTE: U1.9 (PC1), U20.15 (SEL), U23.10 (SEL)
PD_INT: U2.5 (INT_N)
RCLK: J2.5
SOM_ATTACHED: R27.2, U1.3 (PC14), U6.8 (ST), U27.2
SOM_CTRL_RX: U15.1 (A0), U22.1 (A0)
SOM_CTRL_TX: U15.7 (B0), U22.7 (B0)
SOM_ENCODER_A: U9.7 (S1A), U21.1 (A0)
SOM_ENCODER_B: U9.8 (S2A), U21.7 (B0)
SOM_LCD_BL: U4.7 (S1A), U18.3 (S2A)
SOM_LCD_DC: U11.8 (S2A), U18.9 (S3A)
SOM_LCD_MISO: U4.8 (S2A), U17.3 (S2A)
SOM_LCD_MOSI: U10.8 (S2A), U17.12 (S4A)
SOM_LCD_RST: U12.7 (S1A), U18.16 (S1A)
SOM_LCD_SCK: U10.7 (S1A), U17.9 (S3A)
SOM_LCD_SS: U11.7 (S1A), U17.16 (S1A)
SOM_PAD_CENTER: U19.8 (S2A), U23.1 (A0)
SOM_PAD_DOWN: U13.8 (S2A), U20.9 (S3A)
SOM_PAD_LEFT: U14.7 (S1A), U20.3 (S2A)
SOM_PAD_RIGHT: U14.8 (S2A), U20.16 (S1A)
SOM_PAD_UP: U13.7 (S1A), U20.12 (S4A)
SWDCLK: J34.2, U1.49 (PA14)
SWDIO: J34.4, U1.46 (PA13)
SYNC: J2.9, U1.15 (PA1)
TO_REMOTE_CTRL_RX: J2.48, J33.16, U22.2 (A1)
TO_REMOTE_CTRL_TX: J2.49, J36.17, U22.6 (B1)
TO_REMOTE_ENCODER_A: J2.34, J33.9, U21.2 (A1)
TO_REMOTE_ENCODER_B: J2.36, J33.10, U21.6 (B1)
TO_REMOTE_LCD_BL: J2.19, J36.2, U18.4 (S2B)
TO_REMOTE_LCD_DC: J2.29, J36.7, U18.8 (S3B)
TO_REMOTE_LCD_MISO: J2.22, J33.3, U17.4 (S2B)
TO_REMOTE_LCD_MOSI: J2.25, J36.5, U17.11 (S4B)
TO_REMOTE_LCD_RST: J2.31, J36.8, U18.1 (S1B)
TO_REMOTE_LCD_SCK: J2.23, J36.4, U17.8 (S3B)
TO_REMOTE_LCD_SS: J2.27, J36.6, U17.1 (S1B)
TO_REMOTE_PAD_CENTER: J2.46, J33.15, U23.2 (A1)
TO_REMOTE_PAD_DOWN: J2.40, J33.12, U20.8 (S3B)
TO_REMOTE_PAD_LEFT: J2.42, J33.13, U20.4 (S2B)
TO_REMOTE_PAD_RIGHT: J2.44, J33.14, U20.1 (S1B)
TO_REMOTE_PAD_UP: J2.38, J33.11, U20.11 (S4B)
USB_D+: J29.A6 (D+), J29.B6 (D+), R12.2
USB_D-: J29.A7 (D-), J29.B7 (D-), R11.2
VBUS2_SENSE: R9.2, R10.1
VBUS_DOCK: C8.1, C16.1, C21.1, C49.1, F1.2, F5.2, J35.15, J35.16, J35.17, J35.18, J35.19, J35.20, J35.MFA_2, U2.2 (VBUS), U5.1 (VI), U7.3 (VI)
VOUT: C1.1, J19.1, J20.1, J21.1, J22.1, J35.22, J35.23, J35.24, J35.82, J35.83, J35.84, J35.MFA_1
VSENSE_IN: J17.1 (In), J18.1, J35.4
VSYS: J35.MFB_1, J35.MFB_2
/LOCK: J2.11, U1.16 (PA2)
/RST: C47.1, J34.1, R19.2, SW6.2 (B), U1.7 (NRST)
/SOM_ATTACHED: U17.13 (~EN), U18.13 (~EN), U20.13 (~EN), U21.8 (~EN), U22.8 (~EN), U23.8 (~EN), U27.4

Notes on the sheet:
STLINK V2 connector clone this time the correct one...


Board: 4 copper layers, 166.4 x 156.2 mm, 175 parts (0 on the bottom side), 182 nets.

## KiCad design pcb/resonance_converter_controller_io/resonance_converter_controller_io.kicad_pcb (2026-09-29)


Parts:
C1, C2, C3, C4, C5, C6, C7, C8, C9, C11, C14, C15, C19, C20: 100nF; C_0402_1005Metric
C10, C16: C; C_0805_2012Metric; not fitted
C12, C13, C41, C50: 47uF; C_1206_3216Metric
C17, C18: C; C_0805_2012Metric
D1: D_Schottky; D_SMA
H1, H2, H3, H4, H6: MountingHole_Pad; MountingHole_2.2mm_M2_Pad_Via
J1: DF12NB_5.0_-20DP-0.5V_51_; HRS_DF12NB_5.0_-20DP-0.5V_51_
J2: Conn_01x30_MountingPin; Hirose_FH12-30S-0.5SH_1x30-1MP_P0.50mm_Horizontal
J3, J4: Conn_01x02; PhoenixContact_MCV_1,5_2-G-3.5_1x02_P3.50mm_Vertical
J7: Conn_ARM_SWD_TagConnect_TC2030; Tag-Connect_TC2030-IDC-FP_2x03_P1.27mm_Vertical
L1: 4.7uH; L_1210_3225Metric
R1, R2, R3, R4, R5, R14: 0; R_0402_1005Metric
R6: 0; R_0402_1005Metric; not fitted
R7, R8: 10K; R_0402_1005Metric
R9: 0; R_0805_2012Metric
R11: 536K; R_0402_1005Metric
R12: 60.4; R_0402_1005Metric
S1: JS5208; SW_JS5208; PARTREV D; DigiKey_Part_Number EG4561-ND
SW1: RotaryEncoder_Switch_MP; RotaryEncoder_Alps_EC11E-Switch_Vertical_H20mm_MountingHoles
SW2, SW3, SW4, SW5: SW_SPST; SW_SPST_EVQPE1
U1: PCF8574RGTR; QFN50P300X300X100-17N; PARTREV J; DigiKey_Part_Number 296-21238-1-ND
U2: TLV61047DDC; SOT-23-5
U3: AXK6S40647YG; CONN-SMD_40P_AXK6S40547YG; LCSC Part C3651273

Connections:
+3.3V: C9.1, C50.1, J2.9, J2.10, R1.1, R3.1, R5.1, R6.1, R7.1, R8.1, U1.1 (VCC)
+3.3VP: C11.1, C41.1, J1.16, J1.18, L1.1, U2.5 (VIN)
+7V: C12.1, C13.1, C18.2, D1.1 (K), J2.28, R11.1
CENTER: C4.1, S1.3, U1.6 (P1)
DEV_PAD_CENTER: C14.1, SW1.S1, U1.5 (P0)
DOWN: C1.1, S1.6, U1.7 (P2)
GND: C1.2, C2.2, C3.2, C4.2, C5.2, C6.2, C7.2, C8.2, C9.2, C11.2, C12.2, C13.2, C14.2, C15.2, C17.1, C18.1, C19.2, C20.2, C41.2, C50.2, H1.1 (1_1), H2.1 (1_1), H3.1 (1_1), H4.1 (1_1), H6.1 (1_1), J1.2, J1.4, J1.6, J2.1, J2.8, J2.11, J2.12, J2.16, J2.17, J2.20, J2.21, J2.22, J2.23, J2.24, J2.25, J2.29, J2.30, J2.MP (MountPin), J3.2, J4.2, J7.5 (GND), R2.2, R4.2, R9.1, R12.2, R14.2, S1.1, SW1.C, SW1.MP, SW1.S2, SW2.1 (A), SW3.1 (A), SW4.1 (A), SW5.1 (A), U1.9 (GND), U1.17 (EXP), U2.2 (GND), U3.1, U3.2, U3.3, U3.4, U3.5, U3.6, U3.7, U3.8, U3.9, U3.10, U3.11, U3.12, U3.13, U3.14, U3.15, U3.16, U3.17, U3.18, U3.19, U3.20
HRTIM_EEV9: C15.1, J1.15, SW4.2 (B)
INT_I2C_SCL: J1.14, U1.15 (SCL)
INT_I2C_SDA: J1.12, U1.16 (SDA)
KEY_INT: J1.17, U1.14 (~INT)
LEFT: C5.1, S1.2, U1.8 (P3)
LOCAL_ENCODER_CHA: C7.1, J1.8, R8.2, SW1.A
LOCAL_ENCODER_CHB: C6.1, J1.5, R7.2, SW1.B
LOCAL_LCD_DC: J1.9, J2.15
LOCAL_LCD_MOSI: J1.13, J2.19
LOCAL_LCD_SCK: J1.7, J2.18
LOCAL_LCD_SS: J1.11, J2.13
NRST: C19.1, J1.19, J7.3 (~RESET), SW3.2 (B)
unnamed: D1.2 (A), L1.2, U2.1 (SW)
unnamed: C10.2, J2.2
unnamed: C10.1, J2.3
unnamed: C16.2, J2.4
unnamed: C16.1, J2.5
unnamed: J2.6, R6.2
unnamed: J2.26, R9.2
unnamed: C17.2, J2.27
unnamed: R1.2, R2.1, U1.2 (A0)
unnamed: R3.2, R4.1, U1.3 (A1)
unnamed: R5.2, R14.1, U1.4 (A2)
unnamed: R11.2, R12.1, U2.3 (FB)
OLED_RST: J2.14, U1.12 (P6), U2.4 (EN)
RIGHT: C2.1, S1.5, U1.10 (P4)
SHUTDOWN: C8.1, SW5.2 (B), U1.13 (P7)
SWCLK: J1.1, J7.4 (SWCLK)
SWDIO: J1.3, J7.2 (SWDIO)
UP: C3.1, S1.4, U1.11 (P5)
VCC: J1.20
VOUT: J3.1, U3.21, U3.23, U3.25, U3.27, U3.29, U3.31, U3.33, U3.35, U3.37, U3.39
VSYS: J4.1, U3.22, U3.24, U3.26, U3.28, U3.30, U3.32, U3.34, U3.36, U3.38, U3.40
/QON: C20.1, J1.10, SW2.2 (B)



Board: 4 copper layers, 61.4 x 79.6 mm, 55 parts (9 on the bottom side), 40 nets.

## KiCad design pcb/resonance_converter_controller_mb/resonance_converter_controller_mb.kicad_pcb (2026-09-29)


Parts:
C1, C2: C_Polarized; CP_Elec_10x10
C3, C4, C5, C6: C; C_0805_2012Metric
C7, C8: 100nF; C_0805_2012Metric
C9, C10: 10uF; C_0805_2012Metric
D4: D_Zener; D_SMC
D5: LED; LED_1206_3216Metric
D6: D_Zener; D_MiniMELF
D7, D8, D9: D; D_SMA
F1, F2: Fuse; Fuseholder_Clip-5x20mm_Keystone_3518P_Inline_P23.11x6.76mm_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
H1, H2, H3, H6: MountingHole_Pad; MountingHole_2.2mm_M2_Pad_Via
J3: Conn_01x02; AMASS_XT30PW-M_1x02_P2.50mm_Horizontal
J5, J6: Conn_01x04_MountingPin; JST_SH_SM04B-SRSS-TB_1x04-1MP_P1.00mm_Horizontal
Q1, Q2: Q_NPN_BEC; SOT-23
Q3: Q_PMOS_GDS; TO-263-2
R1, R2, R3, R4, R5, R6: 0R; R_0805_2012Metric
R7, R10, R12: 10K; R_0805_2012Metric
R8, R56, R58: R; R_0805_2012Metric
R9: 100K; R_0805_2012Metric
R11: 100R; R_0805_2012Metric
RV1: R_Potentiometer; Potentiometer_Bourns_3269W_Vertical
U1: PCF8574RGTR; QFN50P300X300X100-17N; PARTREV J; DigiKey_Part_Number 296-21238-1-ND
U2: TL431D; SOIC-8_3.9x4.9mm_P1.27mm
U3: LP2950-3.3_TO252; TO-252-2
U4: LTC4311CSC6; SC70-SC6; MANUFACTURER_PART_NUMBER ltc4311csc6#pbf
U5: 74LVC1G14

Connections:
+3.3V: C1.1, C4.1, C5.1, C6.1, D5.2 (A), F1.2, R4.1, R5.1, R6.1, R7.1, U1.1 (VCC), U4.1 (VCC), U4.3 (ENABLE), U5.5 (VCC); also elsewhere on the board
CONNECT_VDD_TO_VBUS_DOCK: U1.6 (P1), U5.2; also elsewhere on the board
DOCK_CTRL_RX: J6.4; also elsewhere on the board
DOCK_CTRL_TX: J6.3; also elsewhere on the board
DOCK_GPIO0: R7.2, U1.14 (~INT); also elsewhere on the board
EXT_VCC: D7.1 (K), D8.1 (K), D9.1 (K), F1.1; also elsewhere on the board
GND: C1.2, C2.2, C4.2, C5.2, C6.2, C7.2, C8.2, C9.2, C10.2, D4.2 (A), H1.1 (1_1), H2.1 (1_1), H3.1 (1_1), H6.1 (1_1), J3.1, J5.1, J5.MP (MountPin), J6.1, J6.MP (MountPin), Q1.2 (E), Q2.2 (E), R1.2, R2.2, R3.2, R58.2, U1.9 (GND), U1.17 (EXP), U3.2 (GND), U4.2 (GND_2), U4.5 (GND), U5.3 (GND); also elsewhere on the board
I2C_EXT_SCL: J5.4, U1.15 (SCL), U4.6 (BUS1); also elsewhere on the board
I2C_EXT_SDA: J5.3, U1.16 (SDA), U4.4 (BUS2); also elsewhere on the board
unnamed: C3.2, R11.2
unnamed: D5.1 (K), R8.1
unnamed: D6.2 (A), Q3.1 (G), R9.2, R10.1, R11.1
unnamed: D7.2 (A), J5.2
unnamed: D8.2 (A), J6.2
unnamed: C7.1, C9.1, D9.2 (A), U3.3 (VO)
unnamed: F2.1, J3.2
unnamed: Q1.1 (B), R58.1, RV1.3, U2.2 (A), U2.3 (A), U2.6 (A), U2.7 (A)
unnamed: Q2.1 (B), R12.2
unnamed: Q2.3 (C), R10.2
unnamed 53: R12.1, U5.4; also elsewhere on the board
unnamed: R3.1, R4.2, U1.2 (A0)
unnamed: R2.1, R5.2, U1.3 (A1)
unnamed: R1.1, R6.2, U1.4 (A2)
unnamed: R56.2, RV1.1, U2.1 (K)
unnamed: RV1.2, U2.8 (REF)
VBUS_DOCK: C3.1, Q3.2 (D); also elsewhere on the board
VDD: C2.1, C8.1, C10.1, D4.1 (K), D6.1 (K), F2.2, Q3.3 (S), R9.1, R56.1, U3.1 (VI)
VDD_PRESENT: Q1.3 (C), R8.2, U1.5 (P0)

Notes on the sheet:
SLOT 2
SLOT 3
SLOT 1


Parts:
D1: D; D_SMA
J1: FX18-120P-0.8SV; HIROSE_FX18-120P-0.8SV; PARTREV 11.07.21

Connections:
AUX_ADC: J1.61; also elsewhere on the board
AUX_PWM_CH1: J1.48; also elsewhere on the board
AUX_PWM_CH2: J1.109; also elsewhere on the board
AUX_RX: J1.96; also elsewhere on the board
AUX_TX: J1.98; also elsewhere on the board
DAC_OUT: J1.12; also elsewhere on the board
DOCK_CTRL_RX: J1.35; also elsewhere on the board
DOCK_CTRL_TX: J1.37; also elsewhere on the board
DOCK_ENCODER_CHA: J1.41; also elsewhere on the board
DOCK_ENCODER_CHB: J1.102; also elsewhere on the board
DOCK_GPIO0: J1.45; also elsewhere on the board
DOCK_GPIO1: J1.44; also elsewhere on the board
DOCK_GPIO2: J1.43; also elsewhere on the board
DOCK_GPIO3: J1.42; also elsewhere on the board
DOCK_GPIO4: J1.103; also elsewhere on the board
DOCK_GPIO5: J1.104; also elsewhere on the board
DOCK_GPIO6: J1.105; also elsewhere on the board
DOCK_GPIO7: J1.106; also elsewhere on the board
DOCK_LCD_BL: J1.100; also elsewhere on the board
DOCK_LCD_DC: J1.101; also elsewhere on the board
DOCK_LCD_MISO: J1.90; also elsewhere on the board
DOCK_LCD_MOSI: J1.31; also elsewhere on the board
DOCK_LCD_RST: J1.39; also elsewhere on the board
DOCK_LCD_SCK: J1.92; also elsewhere on the board
DOCK_LCD_SS: J1.29; also elsewhere on the board
EXT_VCC: D1.1 (K); also elsewhere on the board
FAN_PWM: J1.40; also elsewhere on the board
FB_IN: J1.2; also elsewhere on the board
GND: J1.1, J1.3, J1.5, J1.7, J1.9, J1.11, J1.13, J1.14, J1.21, J1.25, J1.26, J1.27, J1.28, J1.30, J1.32, J1.34, J1.36, J1.38, J1.46, J1.47, J1.49, J1.51, J1.53, J1.55, J1.57, J1.59, J1.60, J1.62, J1.64, J1.66, J1.68, J1.70, J1.72, J1.73, J1.77, J1.81, J1.85, J1.86, J1.88, J1.89, J1.91, J1.93, J1.95, J1.97, J1.99, J1.107, J1.108, J1.110, J1.112, J1.114, J1.116, J1.118, J1.120; also elsewhere on the board
HRTIM_EEV9: J1.10; also elsewhere on the board
HRTIM_FLT3: J1.71; also elsewhere on the board
I2C_EXT_SCL: J1.33; also elsewhere on the board
I2C_EXT_SDA: J1.94; also elsewhere on the board
ISENSE_1: J1.6; also elsewhere on the board
ISENSE_2: J1.67; also elsewhere on the board
ISENSE_3: J1.8; also elsewhere on the board
ISENSE_4: J1.69; also elsewhere on the board
MCO: J1.87; also elsewhere on the board
unnamed: D1.2 (A), J1.78, J1.79, J1.80
OCD2_IN: J1.65; also elsewhere on the board
OCD_IN: J1.63; also elsewhere on the board
OUT1: J1.119; also elsewhere on the board
OUT2: J1.117; also elsewhere on the board
OUT3: J1.115; also elsewhere on the board
OUT4: J1.113; also elsewhere on the board
OUT_SYNC_1+: J1.111; also elsewhere on the board
OUT_SYNC_1-: J1.50; also elsewhere on the board
OUT_SYNC_2+: J1.52; also elsewhere on the board
OUT_SYNC_2-: J1.54; also elsewhere on the board
OUT_SYNC_3+: J1.56; also elsewhere on the board
OUT_SYNC_3-: J1.58; also elsewhere on the board
VBUS_DOCK: J1.15, J1.16, J1.17, J1.18, J1.19, J1.20, J1.MFA_2; also elsewhere on the board
VOUT: J1.22, J1.23, J1.24, J1.82, J1.83, J1.84, J1.MFA_1; also elsewhere on the board
VSENSE_IN: J1.4; also elsewhere on the board
VSYS: J1.MFB_1, J1.MFB_2; also elsewhere on the board

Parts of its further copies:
D2, D3: D; D_SMA
J2, J4: FX18-120P-0.8SV; HIROSE_FX18-120P-0.8SV; PARTREV 11.07.21

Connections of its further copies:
AUX_ADC: J2.61, J4.61; also elsewhere on the board
AUX_PWM_CH1: J2.48, J4.48; also elsewhere on the board
AUX_PWM_CH2: J2.109, J4.109; also elsewhere on the board
AUX_RX: J2.96, J4.96; also elsewhere on the board
AUX_TX: J2.98, J4.98; also elsewhere on the board
DAC_OUT: J2.12, J4.12; also elsewhere on the board
DOCK_CTRL_RX: J2.35, J4.35; also elsewhere on the board
DOCK_CTRL_TX: J2.37, J4.37; also elsewhere on the board
DOCK_ENCODER_CHA: J2.41, J4.41; also elsewhere on the board
DOCK_ENCODER_CHB: J2.102, J4.102; also elsewhere on the board
DOCK_GPIO0: J2.45, J4.45; also elsewhere on the board
DOCK_GPIO1: J2.44, J4.44; also elsewhere on the board
DOCK_GPIO2: J2.43, J4.43; also elsewhere on the board
DOCK_GPIO3: J2.42, J4.42; also elsewhere on the board
DOCK_GPIO4: J2.103, J4.103; also elsewhere on the board
DOCK_GPIO5: J2.104, J4.104; also elsewhere on the board
DOCK_GPIO6: J2.105, J4.105; also elsewhere on the board
DOCK_GPIO7: J2.106, J4.106; also elsewhere on the board
DOCK_LCD_BL: J2.100, J4.100; also elsewhere on the board
DOCK_LCD_DC: J2.101, J4.101; also elsewhere on the board
DOCK_LCD_MISO: J2.90, J4.90; also elsewhere on the board
DOCK_LCD_MOSI: J2.31, J4.31; also elsewhere on the board
DOCK_LCD_RST: J2.39, J4.39; also elsewhere on the board
DOCK_LCD_SCK: J2.92, J4.92; also elsewhere on the board
DOCK_LCD_SS: J2.29, J4.29; also elsewhere on the board
EXT_VCC: D2.1 (K), D3.1 (K); also elsewhere on the board
FAN_PWM: J2.40, J4.40; also elsewhere on the board
FB_IN: J2.2, J4.2; also elsewhere on the board
GND: J2.1, J2.3, J2.5, J2.7, J2.9, J2.11, J2.13, J2.14, J2.21, J2.25, J2.26, J2.27, J2.28, J2.30, J2.32, J2.34, J2.36, J2.38, J2.46, J2.47, J2.49, J2.51, J2.53, J2.55, J2.57, J2.59, J2.60, J2.62, J2.64, J2.66, J2.68, J2.70, J2.72, J2.73, J2.77, J2.81, J2.85, J2.86, J2.88, J2.89, J2.91, J2.93, J2.95, J2.97, J2.99, J2.107, J2.108, J2.110, J2.112, J2.114, J2.116, J2.118, J2.120, J4.1, J4.3, J4.5, J4.7, J4.9, J4.11, J4.13, J4.14, J4.21, J4.25, J4.26, J4.27, J4.28, J4.30, J4.32, J4.34, J4.36, J4.38, J4.46, J4.47, J4.49, J4.51, J4.53, J4.55, J4.57, J4.59, J4.60, J4.62, J4.64, J4.66, J4.68, J4.70, J4.72, J4.73, J4.77, J4.81, J4.85, J4.86, J4.88, J4.89, J4.91, J4.93, J4.95, J4.97, J4.99, J4.107, J4.108, J4.110, J4.112, J4.114, J4.116, J4.118, J4.120; also elsewhere on the board
HRTIM_EEV9: J2.10, J4.10; also elsewhere on the board
HRTIM_FLT3: J2.71, J4.71; also elsewhere on the board
I2C_EXT_SCL: J2.33, J4.33; also elsewhere on the board
I2C_EXT_SDA: J2.94, J4.94; also elsewhere on the board
ISENSE_1: J2.6, J4.6; also elsewhere on the board
ISENSE_2: J2.67, J4.67; also elsewhere on the board
ISENSE_3: J2.8, J4.8; also elsewhere on the board
ISENSE_4: J2.69, J4.69; also elsewhere on the board
MCO: J2.87, J4.87; also elsewhere on the board
unnamed: D2.2 (A), J2.78, J2.79, J2.80
unnamed: D3.2 (A), J4.78, J4.79, J4.80
OCD2_IN: J2.65, J4.65; also elsewhere on the board
OCD_IN: J2.63, J4.63; also elsewhere on the board
OUT1: J2.119, J4.119; also elsewhere on the board
OUT2: J2.117, J4.117; also elsewhere on the board
OUT3: J2.115, J4.115; also elsewhere on the board
OUT4: J2.113, J4.113; also elsewhere on the board
OUT_SYNC_1+: J2.111, J4.111; also elsewhere on the board
OUT_SYNC_1-: J2.50, J4.50; also elsewhere on the board
OUT_SYNC_2+: J2.52, J4.52; also elsewhere on the board
OUT_SYNC_2-: J2.54, J4.54; also elsewhere on the board
OUT_SYNC_3+: J2.56, J4.56; also elsewhere on the board
OUT_SYNC_3-: J2.58, J4.58; also elsewhere on the board
VBUS_DOCK: J2.15, J2.16, J2.17, J2.18, J2.19, J2.20, J2.MFA_2, J4.15, J4.16, J4.17, J4.18, J4.19, J4.20, J4.MFA_2; also elsewhere on the board
VOUT: J2.22, J2.23, J2.24, J2.82, J2.83, J2.84, J2.MFA_1, J4.22, J4.23, J4.24, J4.82, J4.83, J4.84, J4.MFA_1; also elsewhere on the board
VSENSE_IN: J2.4, J4.4; also elsewhere on the board
VSYS: J2.MFB_1, J2.MFB_2, J4.MFB_1, J4.MFB_2; also elsewhere on the board


Board: 6 copper layers, 100.0 x 100.0 mm, 54 parts (0 on the bottom side), 77 nets.

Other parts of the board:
U3#2: 74LVC1G04; SOT-23-5

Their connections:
+3.3V: U3#2.5 (VCC); also elsewhere on the board
CONNECT_VDD_TO_VBUS_DOCK: U3#2.2; also elsewhere on the board
GND: U3#2.3 (GND); also elsewhere on the board
unnamed 53: U3#2.4; also elsewhere on the board

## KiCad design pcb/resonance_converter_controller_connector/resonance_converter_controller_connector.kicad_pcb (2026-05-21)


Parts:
D1, D2, D3, D33: ESD9B3.3ST5G; D_SOD-923
H1, H2, H3, H6: MountingHole_Pad; MountingHole_2.2mm_M2_Pad_Via
J1, J2, J3, J15, J16, J17, J19, J20: Conn_01x02; PhoenixContact_MCV_1,5_2-G-5.08_1x02_P5.08mm_Vertical
J4, J7, J8, J9, J10, J11, J21, J22, J23: Conn_01x04; JST_PH_B4B-PH-K_1x04_P2.00mm_Vertical
J5, J12, J24: Conn_01x02; AMASS_XT30U-M_1x02_P5.0mm_Vertical
J13: Conn_01x06; JST_PH_B6B-PH-K_1x06_P2.00mm_Vertical
J14: Conn_02x05_Odd_Even; PinHeader_2x05_P2.54mm_Vertical
J18: Conn_01x08; PhoenixContact_MCV_1,5_8-G-3.5_1x08_P3.50mm_Vertical
L1: L; L_Radial_D12.0mm_P10.00mm_Neosid_SD12_style1
R1, R2, R3: R; TO-220-2_Vertical
R4: R; R_2010_5025Metric
RV1: R_Potentiometer; Potentiometer_Bourns_3269W_Vertical

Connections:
+3.3V: J14.1; also elsewhere on the board
AUX_ADC: D1.1 (A1), J16.1; also elsewhere on the board
AUX_PWM_CH1: D2.1 (A1), J19.1; also elsewhere on the board
AUX_PWM_CH2: D3.1 (A1), J20.1; also elsewhere on the board
DAC_OUT: D33.1 (A1), J15.1; also elsewhere on the board
FB_IN: J1.1, L1.1; also elsewhere on the board
GND: D1.2 (A2), D2.2 (A2), D3.2 (A2), D33.2 (A2), H1.1 (1_1), H2.1 (1_1), H3.1 (1_1), H6.1 (1_1), J1.2, J2.2, J3.2, J4.1, J5.1, J7.1, J8.1, J9.1, J10.1, J11.1, J12.1, J13.1, J14.10, J15.2, J16.2, J17.2, J18.1, J18.3, J18.5, J18.7, J19.2, J20.2, J21.1, J22.1, J23.1, J24.1, R1.2, R2.2, R3.2, RV1.2; also elsewhere on the board
GPIO0: J14.3; also elsewhere on the board
GPIO1: J14.5; also elsewhere on the board
GPIO2: J14.7; also elsewhere on the board
GPIO3: J14.9; also elsewhere on the board
GPIO4: J14.8; also elsewhere on the board
GPIO5: J14.6; also elsewhere on the board
GPIO6: J14.4; also elsewhere on the board
GPIO7: J14.2; also elsewhere on the board
ISENSE_1: J18.2; also elsewhere on the board
ISENSE_2: J18.4; also elsewhere on the board
ISENSE_3: J18.6; also elsewhere on the board
ISENSE_4: J18.8; also elsewhere on the board
unnamed: J17.1, R4.1
unnamed: L1.2, R1.1
OCD2_IN: J3.1, R3.1; also elsewhere on the board
OCD_IN: J2.1, R2.1; also elsewhere on the board
OUT1: J13.5; also elsewhere on the board
OUT2: J13.4; also elsewhere on the board
OUT3: J13.3; also elsewhere on the board
OUT4: J13.2; also elsewhere on the board
OUT_SYNC_1+: J4.3, J9.3, J21.3; also elsewhere on the board
OUT_SYNC_1-: J4.2, J9.2, J21.2; also elsewhere on the board
OUT_SYNC_2+: J7.3, J10.3, J22.3; also elsewhere on the board
OUT_SYNC_2-: J7.2, J10.2, J22.2; also elsewhere on the board
OUT_SYNC_3+: J8.3, J11.3, J23.3; also elsewhere on the board
OUT_SYNC_3-: J8.2, J11.2, J23.2; also elsewhere on the board
VDD: J5.2, J12.2, J24.2; also elsewhere on the board
VPP: J4.4, J7.4, J8.4, J9.4, J10.4, J11.4, J13.6, J21.4, J22.4, J23.4; also elsewhere on the board
VSENSE_IN: R4.2, RV1.1; also elsewhere on the board

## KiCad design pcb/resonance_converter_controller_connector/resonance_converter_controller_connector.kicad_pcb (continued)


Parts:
C2, C6, C12, C14: 100nF; C_0402_1005Metric
C3, C11, C13: C_Polarized; CP_Elec_10x10
C4, C5, C7, C8, C9, C10, C44: C; C_0402_1005Metric
D5: LED; LED_1206_3216Metric
Q1, Q2, Q3, Q4: Q_NMOS_GDS; TO-252-2
Q5: Q_NPN_BEC; SOT-23
R5, R6, R7, R8, R16, R17: 0R; R_0402_1005Metric
R9, R10, R11, R12, R13, R14, R56, R58: R; R_0402_1005Metric
R15, R18: 10K; R_0402_1005Metric
RV2, RV3: R_Potentiometer; Potentiometer_Bourns_3269W_Vertical
SW1: SW_DIP_x01; SW_DIP_SPSTx01_Slide_9.78x4.72mm_W8.61mm_P2.54mm
U1: PCF8574RGTR; QFN50P300X300X100-17N; PARTREV J; DigiKey_Part_Number 296-21238-1-ND
U2: MIC29302AWU; TO-263-5_TabPin3
U3: 74LVC1G04; SOT-23-5
U4, U5, U6, U23: TPS2412D; TSSOP-8_4.4x3mm_P0.65mm
U7: TL431D; SOIC-8_3.9x4.9mm_P1.27mm
U8: AT24CS01-SSHM; SOIC-8_3.9x4.9mm_P1.27mm
U9: UA78M33QDCYRQ1; SOT-223-3_TabPin2

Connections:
+3.3V: C4.1, C5.1, C10.1, C13.1, C14.1, D5.2 (A), R5.1, R15.1, R16.1, R17.1, R18.1, U1.1 (VCC), U3.5 (VCC), U8.8 (VCC), U9.3 (OUT); also elsewhere on the board
DOCK_GPIO0: R18.2, U1.14 (~INT)
ENABLE_VPP_LDO: U1.13 (P7), U3.2
GND: C2.2, C3.2, C4.2, C5.2, C6.2, C10.2, C11.2, C12.2, C13.2, C14.2, Q5.2 (E), R6.2, R7.2, R8.2, R10.2, R11.2, R12.2, R56.2, R58.2, RV2.2, SW1.2, U1.9 (GND), U1.17 (EXP), U2.3 (GND), U3.3 (GND), U4.3 (GND), U4.4 (GND), U5.3 (GND), U5.4 (GND), U6.3 (GND), U6.4 (GND), U8.4 (GND), U9.2 (GND), U23.3 (GND), U23.4 (GND); also elsewhere on the board
I2C_EXT_SCL: U1.15 (SCL), U8.6 (SCL); also elsewhere on the board
I2C_EXT_SDA: U1.16 (SDA), U8.5 (SDA); also elsewhere on the board
unnamed: D5.1 (K), R13.1
unnamed: Q1.1 (G), U4.5 (GATE)
unnamed: Q2.1 (G), U5.5 (GATE)
unnamed: Q3.1 (G), U6.5 (GATE)
unnamed: Q4.1 (G), U23.5 (GATE)
unnamed: C3.1, C6.1, C44.1, Q4.3 (S), R9.1, U2.4 (VOUT), U23.7 (A)
unnamed: Q5.1 (B), R58.1, RV3.3, U7.2 (A), U7.3 (A), U7.6 (A), U7.7 (A)
unnamed: R5.2, R6.1, U1.2 (A0), U8.1 (A0)
unnamed: R7.1, R16.2, U1.3 (A1), U8.2 (A1)
unnamed: R8.1, R17.2, U1.4 (A2), U8.3 (A2)
unnamed: R9.2, RV2.1, U2.5 (ADJ)
unnamed: U2.1 (EN), U3.4
unnamed: C7.2, U4.8 (BYP)
unnamed: R10.1, U4.2 (RSET)
unnamed: C8.2, U5.8 (BYP)
unnamed: R11.1, U5.2 (RSET)
unnamed: C9.2, U6.8 (BYP)
unnamed: R12.1, U6.2 (RSET)
unnamed: R14.2, RV3.1, U7.1 (K)
unnamed: RV3.2, U7.8 (REF)
unnamed: R15.2, SW1.1, U8.7 (WP)
unnamed: C44.2, U23.8 (BYP)
unnamed: R56.1, U23.2 (RSET)
VBUS_DOCK: C8.1, Q2.3 (S), U5.7 (A); also elsewhere on the board
VDD: C2.1, C11.1, C12.1, Q2.2 (D), Q3.2 (D), R14.1, U2.2 (VIN), U5.1 (VDD), U5.6 (C), U6.1 (VDD), U6.6 (C), U9.1 (IN); also elsewhere on the board
VDD_PRESENT: Q5.3 (C), R13.2, U1.5 (P0)
VOUT: C7.1, Q1.3 (S), U4.7 (A); also elsewhere on the board
VPP: Q1.2 (D), Q4.2 (D), U4.1 (VDD), U4.6 (C), U23.1 (VDD), U23.6 (C); also elsewhere on the board
VSYS: C9.1, Q3.3 (S), U6.7 (A); also elsewhere on the board


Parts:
J6: FX18-120S-0.8SH; HIROSE_FX18-120S-0.8SH; PARTREV 1

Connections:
AUX_ADC: J6.60; also elsewhere on the board
AUX_PWM_CH1: J6.73; also elsewhere on the board
AUX_PWM_CH2: J6.12; also elsewhere on the board
AUX_RX: J6.25
AUX_TX: J6.23
CTRL_RX: J6.86
CTRL_TX: J6.84
DAC_OUT: J6.109; also elsewhere on the board
FAN_PWM: J6.81
FB_IN: J6.119; also elsewhere on the board
GND: J6.1, J6.3, J6.5, J6.7, J6.9, J6.11, J6.13, J6.14, J6.22, J6.24, J6.26, J6.28, J6.30, J6.32, J6.33, J6.35, J6.36, J6.40, J6.44, J6.48, J6.49, J6.51, J6.53, J6.55, J6.57, J6.59, J6.61, J6.62, J6.64, J6.66, J6.68, J6.70, J6.72, J6.74, J6.75, J6.83, J6.85, J6.87, J6.89, J6.91, J6.93, J6.94, J6.95, J6.96, J6.100, J6.107, J6.108, J6.110, J6.112, J6.114, J6.116, J6.118, J6.120; also elsewhere on the board
GPIO0: J6.76; also elsewhere on the board
GPIO1: J6.77; also elsewhere on the board
GPIO2: J6.78; also elsewhere on the board
GPIO3: J6.79; also elsewhere on the board
GPIO4: J6.18; also elsewhere on the board
GPIO5: J6.17; also elsewhere on the board
GPIO6: J6.16; also elsewhere on the board
GPIO7: J6.15; also elsewhere on the board
HRTIM_EEV9: J6.111
HRTIM_FLT3: J6.50
I2C_EXT_SCL: J6.88; also elsewhere on the board
I2C_EXT_SDA: J6.27; also elsewhere on the board
ISENSE_1: J6.115; also elsewhere on the board
ISENSE_2: J6.54; also elsewhere on the board
ISENSE_3: J6.113; also elsewhere on the board
ISENSE_4: J6.52; also elsewhere on the board
LCD_BL: J6.21
LCD_MISO: J6.31
LCD_RST: J6.82
MCO: J6.34
OCD2_IN: J6.56; also elsewhere on the board
OCD_IN: J6.58; also elsewhere on the board
OUT1: J6.2; also elsewhere on the board
OUT2: J6.4; also elsewhere on the board
OUT3: J6.6; also elsewhere on the board
OUT4: J6.8; also elsewhere on the board
OUT_SYNC_1+: J6.10; also elsewhere on the board
OUT_SYNC_1-: J6.71; also elsewhere on the board
OUT_SYNC_2+: J6.69; also elsewhere on the board
OUT_SYNC_2-: J6.67; also elsewhere on the board
OUT_SYNC_3+: J6.65; also elsewhere on the board
OUT_SYNC_3-: J6.63; also elsewhere on the board
REMOTE_ENCODER_CHA: J6.80
REMOTE_ENCODER_CHB: J6.19
REMOTE_LCD_DC: J6.20
REMOTE_LCD_MOSI: J6.90
REMOTE_LCD_SCK: J6.29
REMOTE_LCD_SS: J6.92
VAA: J6.45, J6.46, J6.47
VBUS_DOCK: J6.101, J6.102, J6.103, J6.104, J6.105, J6.106, J6.MF_B2; also elsewhere on the board
VCC: J6.41, J6.42, J6.43
VOUT: J6.37, J6.38, J6.39, J6.97, J6.98, J6.99, J6.MF_B1; also elsewhere on the board
VSENSE_IN: J6.117; also elsewhere on the board
VSYS: J6.MF_A1, J6.MF_A2; also elsewhere on the board


Board: 4 copper layers, 86.3 x 100.0 mm, 87 parts (1 on the bottom side), 69 nets.

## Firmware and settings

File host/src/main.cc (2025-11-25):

#include "cli.hpp"
#include "tui.hpp"
#include <boost/log/trivial.hpp>
#include <boost/program_options.hpp>
#include <exception>

#include <boost/log/trivial.hpp>
#include <boost/log/core.hpp>
#include <boost/log/expressions.hpp>

using namespace boost::program_options;

int main(int argc, char **argv) {
    boost::log::core::get()->set_filter(
        boost::log::trivial::severity >= boost::log::trivial::error
    );
    options_description desc("Allowed options");
    add_serial_options(desc);

    variables_map vm;
    try {
        store(parse_command_line(argc, argv, desc), vm);

        if (vm.count("help")) {
            BOOST_LOG_TRIVIAL(error) << desc << "\n";
            return 0;
        }

        notify(vm);
    } catch (const std::exception &ex) {
        BOOST_LOG_TRIVIAL(error) << "Error: " << ex.what() << "\n";
        BOOST_LOG_TRIVIAL(error) << desc << "\n";
        return 1;
    }

    Options cfg = parse_serial_options(vm);
    boost::log::core::get()->set_filter(
        boost::log::trivial::severity >= cfg.loglevel
    );

    try {
        Tui interface(cfg);
        interface.run();
    } catch (const std::exception &e) {
        BOOST_LOG_TRIVIAL(error) << "Error: " << e.what() << "\n";
    }

    return 0;
}

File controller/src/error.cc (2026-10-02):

#include "error.hpp"
#include "stm32g4xx_hal.h"
#include <system_error>
#include <cstring>

// =============================================================================
// ControllerErrorCategory Implementation
// =============================================================================

const char* ControllerErrorCategory::name() const noexcept {
    return "controller";
}

std::string ControllerErrorCategory::message(int error) const {
    switch (static_cast<ControllerError>(error)) {
        case ControllerError::HAL_OK:
            return "HAL operation successful";
        case ControllerError::HAL_ERROR:
            return "HAL operation error";
        case ControllerError::HAL_BUSY:
            return "HAL busy";
        case ControllerError::HAL_TIMEOUT:
            return "HAL timeout";
        
        case ControllerError::BQ25792_None:
            return "BQ25792 no error";
        case ControllerError::BQ25792_HALError:
            return "BQ25792 HAL error";
        case ControllerError::BQ25792_Timeout:
            return "BQ25792 timeout";
        case ControllerError::BQ25792_I2CError:
            return "BQ25792 I2C communication error";
        case ControllerError::BQ25792_InvalidAddress:
            return "BQ25792 invalid register address";
        case ControllerError::BQ25792_InvalidParameter:
            return "BQ25792 invalid parameter";
        case ControllerError::BQ25792_NotInitialized:
            return "BQ25792 not initialized";
        case ControllerError::BQ25792_BatteryNotPresent:
            return "BQ25792 battery not present";
        case ControllerError::BQ25792_FaultDetected:
            return "BQ25792 fault condition detected";
        
        case ControllerError::TPS55289_None:
            return "TPS55289 no error";
        case ControllerError::TPS55289_HALError:
            return "TPS55289 HAL error";
        case ControllerError::TPS55289_Timeout:
            return "TPS55289 timeout";
        case ControllerError::TPS55289_InvalidAddress:
            return "TPS55289 invalid I2C address";
        case ControllerError::TPS55289_InvalidRegister:
            return "TPS55289 invalid register address";
        case ControllerError::TPS55289_NotInitialized:
            return "TPS55289 not initialized";
        case ControllerError::TPS55289_I2CError:
            return "TPS55289 I2C communication error";
        
        case ControllerError::UnknownError:
        default:
            return "Unknown error";
    }
}

const std::error_category& controller_error_category() {
    static ControllerErrorCategory category;
    return category;
}

std::error_condition make_error_condition(ControllerError e) {
    return std::error_condition(
        static_cast<int>(e),
        controller_error_category()
    );
}

// =============================================================================
// BQ25792ErrorCategory Implementation
// =============================================================================

const char* BQ25792ErrorCategory::name() const noexcept {
    return "bq25792";
}

std::string BQ25792ErrorCategory::message(int error) const {
    switch (static_cast<bq25792::ErrorCode>(error)) {
        case bq25792::ErrorCode::None:
            return "BQ25792 no error";
        case bq25792::ErrorCode::HALError:
            return "BQ25792 HAL error";
        case bq25792::ErrorCode::Timeout:
            return "BQ25792 operation timeout";
        case bq25792::ErrorCode::I2CError:
            return "BQ25792 I2C communication error";
        case bq25792::ErrorCode::InvalidAddress:
            return "BQ25792 invalid register address";
        case bq25792::ErrorCode::InvalidParameter:
            return "BQ25792 invalid parameter";
        case bq25792::ErrorCode::NotInitialized:
            return "BQ25792 not initialized";
        case bq25792::ErrorCode::BatteryNotPresent:
            return "BQ25792 battery not present";
        case bq25792::ErrorCode::FaultDetected:
            return "BQ25792 fault condition detected";
        default:
            return "BQ25792 unknown error";
    }
}

const std::error_category& bq25792_error_category() {
    static BQ25792ErrorCategory category;
    return category;
}

// =============================================================================
// TPS55289ErrorCategory Implementation
// =============================================================================

const char* TPS55289ErrorCategory::name() const noexcept {
    return "tps55289";
}

std::string TPS55289ErrorCategory::message(int error) const {
    switch (static_cast<tps55289::ErrorCode>(error)) {
        case tps55289::ErrorCode::None:
            return "TPS55289 no error";
        case tps55289::ErrorCode::HALError:
            return "TPS55289 HAL error";
        case tps55289::ErrorCode::Timeout:
            return "TPS55289 operation timeout";
        case tps55289::ErrorCode::InvalidAddress:
            return "TPS55289 invalid I2C address";
        case tps55289::ErrorCode::InvalidRegister:
            return "TPS55289 invalid register address";
        case tps55289::ErrorCode::NotInitialized:
            return "TPS55289 not initialized";
        case tps55289::ErrorCode::I2CError:
            return "TPS55289 I2C communication error";
        default:
            return "TPS55289 unknown error";
    }
}

const std::error_category& tps55289_error_category() {
    static TPS55289ErrorCategory category;
    return category;
}

// =============================================================================
// DACErrorCategory Implementation
// =============================================================================

const char* DACErrorCategory::name() const noexcept {
    return "dac";
}

std::string DACErrorCategory::message(int error) const {
    switch (static_cast<ControllerError>(error)) {
        case ControllerError::DAC_None:
            return "DAC no error";
        case ControllerError::DAC_ERROR:
            return "DAC general error";
        case ControllerError::DAC_TIMEOUT:
            return "DAC timeout";
        case ControllerError::DAC_INVALID_MODE:
            return "DAC invalid mode";
        case ControllerError::DAC_INVALID_PARAMETER:
            return "DAC invalid parameter";
        case ControllerError::DAC_NOT_INITIALIZED:
            return "DAC not initialized";
        case ControllerError::DAC_DMA_ERROR:
            return "DAC DMA error";
        case ControllerError::DAC_WAVEFORM_ERROR:
            return "DAC waveform generation error";
        default:
            return "DAC unknown error";
    }
}

const std::error_category& dac_error_category() {
    static DACErrorCategory category;
    return category;
}

// =============================================================================
// HAL Status Conversion
// =============================================================================
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

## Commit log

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2025-11-25 Fix a lot of bugs
    [ctl.cc, main.cc, message_handler.cc]
2026-01-13 Start creating pcb for the controller
    [analog.kicad_sch, controller.kicad_sch, output.kicad_sch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]
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2026-03-21 Finish first schematic resivion of the SOM
    [analog.kicad_sch, controller.kicad_sch, resoncance_converter_controller.kicad_pcb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]
2026-03-21 Fix typo
    [analog.kicad_sch, controller.kicad_sch, output.kicad_sch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]
2026-03-23 Create first version of the dock
    [resonance_converter_controller_dock_v1.kicad_pcb, resonance_converter_controller_dock_v1.kicad_sch]
2026-03-23 Update conector in dock
    [resonance_converter_controller_dock_v1.kicad_sch]
2026-03-23 Update conector in som
    [controller.kicad_sch, power.kicad_sch, resoncance_converter_controller.kicad_pcb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]
2026-03-25 Fix errors and make initial component placement in dock
    [resonance_converter_controller_dock_v1.kicad_pcb, resonance_converter_controller_dock_v1.kicad_sch]
2026-03-28 First routing without testpoints
    [analog.kicad_sch, controller.kicad_sch, power.kicad_sch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]
2026-03-29 Add mounting holes and some rework
    [resonance_converter_controller_dock_v1.kicad_pcb, resonance_converter_controller_dock_v1.kicad_sch, resoncance_converter_controller.kicad_pcb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]
2026-04-02 Add reset handler buffer for dac and led
    [controller.kicad_sch, power.kicad_sch, resoncance_converter_controller.kicad_pcb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]
2026-04-06 Add io panel and fix controller pcb
    [analog.kicad_sch, controller.kicad_sch, power.kicad_sch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]
2026-05-07 Add digital pots to auto adjust gain
    [analog.kicad_sch, controller.kicad_sch, power.kicad_sch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]
2026-05-07 Add debug probe idea based on osd32mp1
    [analog.kicad_sch, connectors.kicad_sch, cpu connections.kicad_sch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]
2026-05-07 Add motherboard preview
    [conn.kicad_sch, resonance_converter_controller_mb.kicad_pcb, resonance_converter_controller_mb.kicad_sch]
2026-05-08 Prep for autoroute
    [resonance_converter_controller_mb.kicad_pcb]
2026-05-16 Prep connector board for autoroute
    [connector.kicad_sch, logic.kicad_sch, resonance_converter_controller_connector.kicad_pcb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]
2026-05-17 Add schematic for debug probe
    [analog.kicad_sch, connectors.kicad_sch, cpu connections.kicad_sch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]
2026-05-19 _mb board freerouted
    [resonance_converter_controller_mb.kicad_pcb, resonance_converter_controller_mb.kicad_sch]
2026-05-19 Add I2C line terminator
    [conn.kicad_sch, resonance_converter_controller_mb.kicad_pcb, resonance_converter_controller_mb.kicad_sch]
2026-05-20 connctor board routed
    [connector.kicad_sch, logic.kicad_sch, resonance_converter_controller_connector.kicad_pcb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]
2026-05-20 Fix silkscreen
    [resonance_converter_controller_connector.kicad_pcb]
2026-05-20 Reduce copper layers as it fits on 4
    [resonance_converter_controller_connector.kicad_pcb]
2026-05-20 Kicad 9 -> 10
    [connector.kicad_sch, logic.kicad_sch, resonance_converter_controller_connector.kicad_sch]
2026-05-20 Fix schematic and initial component layout
    [analog.kicad_sch, connectors.kicad_sch, cpu connections.kicad_sch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]
2026-05-21 Add 3.3v regulator and fix silkscreen
    [resonance_converter_controller_mb.kicad_pcb, resonance_converter_controller_mb.kicad_sch]
2026-05-21 Reroute USB fix silkscreen and Kicad 9 -> 10
    [analog.kicad_sch, controller.kicad_sch, power.kicad_sch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]
2026-05-21 Add 3rd row of output connectors
    [connector.kicad_sch, logic.kicad_sch, resonance_converter_controller_connector.kicad_pcb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]
2026-09-29 Update pcb
    [analog.kicad_sch, connectors.kicad_sch, controller.kicad_sch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]
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2026-10-07 Fix things in debug probe pcb
2026-10-15 feat: Add aux-pwm applet, oscilloscope, hardware emulator, and protocol extensions
    - Add aux-pwm applet for PWM generation on TIMx CH1/CH2 with argum CLI parsing
    - Implement oscilloscope with multi-ADC sampling and DMA-based capture
    - Add hardware emulator and emulator connector for host-side testing
    - Introduce applet framework with registry and lifecycle management
    - Add ResponseStatusCode enum and AppletStatus messages to protocol
    - Refactor DAC driver to support per-channel configuration with waveform generation
    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
2026-10-31 feat: Add host-side error types, ADC trigger timer, and build fixes for host emulator
    Controller:
    - Add error_host.hpp/.cc, a HAL-free ControllerError enum with BQ25792,
    TPS55289, DAC, oscilloscope, I2C, memory and ADC error codes plus
    conversion helpers and get_error_message(), so the host emulator and
    hostctl can share controller error semantics without STM32 headers.
    Build system:
    - Add external/stubs/include/termios.h and wire it into the ctl, hostctl,
    test_emulator and test_commands include paths so argum compiles on
    embedded and host targets.
    - Add argum as a proper subdirectory in external/CMakeLists.txt; mark
    TCLAP as deprecated and disable its examples, unit tests and d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
2026-10-31 Fix driver error-category mapping
    The controller defined its own BQ25792/TPS55289 error_category objects,
    but the drivers create error_codes with their own category singletons.
    The category comparison in from_*_error() therefore never matched and
    every driver error was reported as UnknownError/I2CBusError.
    - bq25792_error_category()/tps55289_error_category() now return the
    drivers' category objects; drop the duplicate category classes
    - Add ControllerError::TPS55289_InvalidParameter (27, inside the
    TPS55289 block so no existing value shifts) and map the new driver
    code; mirror it in error_host.hpp/error_host.cc
2026-10-31 Adapt controller to updated drivers
    Charger (BQ25792):
    - Lock once per public call; private *_locked helpers do the reads, so
    there is no nested locking of the non-recursive mutex
    - set_config() validates every present field before writing and honours
    the has_* flags of ChargerConfigRequest; requested settings are kept
    - New service() / charger-service thread (10 s, 1 KB stack): kicks the
    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
2026-10-31 Make os::mutex::lock() block until acquired
    lock() called osMutexAcquire(handle, 0) and ignored the result: a
    non-blocking try that could return without owning the mutex, after which
    the matching unlock() released a lock held by another thread. No
    std::lock_guard on os::mutex gave mutual exclusion.
    - lock() waits with osWaitForever
    - Rename try_unlock() (which acquired) to try_lock(); no callers
    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
2026-10-31 Rework I2C error handling: recovery, retries, error reporting
    Error codes:
    - Add ControllerErrorCode to protocol.proto mirroring ControllerError;
    static_asserts in error.cc and error_host.cc fail the build on drift
    - Add CommandResult message and Response.result (filled in a later commit)
    - Add PSRAM_* (150-162) and MCP44XX_* (170-176) ranges with mappings
    - Map driver Nack/BusError to I2CNACK/I2CBusError; unknown driver codes
    map to UnknownError instead of I2CBusError
    - from_i2c_error() decodes HAL_I2C_GetError(); a timeout is no longer
    reported as a NACK
    - get_error_source() returns a static string and identifies the source
    correctly (every controller-category error was reported as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
2026-10-31 Log PSRAM QSPI configuration when memory training rejects a clock
    When a prescaler is rejected or psram_init() fails, append the output
    of psram_describe_config() (clock, dual-flash, FSIZE, CS high time,
    burst size) so a wrong CubeMX setting can be identified from the log.
    After a rejected prescaler the driver has restored the previous clock,
    so that line is labelled "current".
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2026-11-01 Remove the obsolete DAC controller and fix controller link errors
    Calling controller_system_init() links the controller for the first time,
    which exposed:
    - DACController (dac_controller.cc) was never compiled and no longer matches
    the DAC driver or the protocol. Remove it; set_dac_config is answered with
    RESPONSE_STATUS_UNSUPPORTED_COMMAND and the status reply has no DAC part.
    - g_psram_driver was defined inside namespace memtest, so the global
    declaration used by memtest and ctl had no definition.
    - update submodules
2026-11-01 Add PSRAM-streamed long-trace oscilloscope using injected conversions
    Rewrite the oscilloscope (the previous single-shot 4 KB SRAM version was
    unused) to record long pre-trigger traces into the 16 MB PSRAM.
    Data path, no CPU per sample:
    - TIM8 TRGO (update) starts an injected conversion on every used ADC.
    - TIM8 CHn, placed just after that ADC's conversion, raises DMA request
    TIM8_CHn, which copies the ADC's JDRx into SRAM ring n (circular, 8 KB).
    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
2026-11-01 Add framed host protocol with link broker, scope transfers and aux data link
    - Frame v2 (protocol/inc/frame.hpp): magic, type, length + ~length, seq,
    CRC-32/MPEG-2; resynchronising stream parser shared by firmware and host
    - Links: control UART and aux UART (DMA or IT fallback, runtime baud with
    OVER8) and USB CDC (hooks in usbd_cdc_if.c USER CODE, ZLP handling);
    report a disabled USART interrupt at start
    - Broker: RX thread per request link, single handler thread, responses on
    the origin link, HAL_BUSY when both request slots are taken
    - Oscilloscope protocol: configure/arm/trigger/stop/status and ScopeRead
    bulk transfer as DATA frames on the origin or aux link, completion event,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
2026-11-01 Move hostctl to frame v2 and expose oscilloscope and power controls
    - Connector: frame::Parser per port, request seq counter, io-thread write
    queue, optional aux data port, message/data hooks; the emulator feeds
    its frames through the same parser
    - ScopeClient: ScopeRead download with DATA reassembly by channel/offset,
    stall timeout, resend of missing ranges (up to 3 rounds), CSV output
    - TUI commands: status, ping, poll, charger on/off/set, out on/off/set,
    scope config/arm/trigger/stop/status/read/cancel, link baud/status;
    new Charger / Output Regulator / Scope-Link panels (DAC panel removed)
    - Fix: typed status/ping commands did nothing; periodic tasks (keepalive)
    were never st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
2026-11-01 Add device diagnostics: firmware log forwarding, device info, charger flags
    - os::log gains a sink; Diagnostics forwards log messages to subscribed
    links as LogMessage EVENTs with a 16-entry boot history replayed on
    subscribe (printf output is discarded on this board: no __io_putchar)
    - GetDeviceInfo: board, git version, uptime, RCC reset cause, FreeRTOS
    heap free/minimum, per-thread stack high-water marks, PSRAM state
    - ChargerStatus: raw BQ25792 status (REG1B/1D/1E/1F) and fault
    (REG20/21) flags
    - Static memory for the forwarder thread, queue and history
    - hostctl: info and log commands, --device-log, decoded Fault/Limit/Warn
    lines in the charger panel; emulator support (applies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
2026-11-01 Redesign hostctl TUI: views, scope plot, device log, completion, forms, trends
    - Tab bar with five views (F1-F5): overview, power trends, scope, device
    log, device info; message pane and command line on every view
    - Message pane: 10 lines (F6 half screen, msgs <n>), 2000 lines kept,
    scroll with Ctrl-Up/Down or mouse wheel, stable while scrolled up
    - Scope view: braille plot of the last capture with min/max envelope per
    column, trigger marker, time/div, zoom and pan (keys or wheel);
    scope load <csv>
    - Device log view with level colours, scrolling and log filter
    - Command history (~/.hostctl_history) and Tab completion of commands,
    keys, values and applet names; no single-key shortcu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
2026-11-01 Add fan, encoder and WS2812B drivers and declare remaining board resources
    - board.h: extern declarations for the timer channels, HRTIM outputs,
    DAC/ADC/COMP channels and GPIO pins defined in main.c
    - board_timer: shared timer clock / PSC+ARR planning (used by oscilloscope)
    - Fan: 25 kHz PWM on TIM3_CH1 with duty in percent, minimum duty, inversion
    - Encoder: TIM20 quadrature counter extended to 32 bits, detent position
    and deltas, counts per detent derived from the encoder mode
    - Ws2812b: 800 kHz bit encoding on TIM5_CH4, DMA when CubeMX links a DMA
    channel, polled fallback for short chains; brightness scaling
    - board_io: accessors for the board instances; encoder and LEDs start at bo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
2026-11-01 Add USB-C power delivery: PD sink with charger input limits, dock priority, battery source
    - Sink 5-20 V up to 3 A (highest-power fixed PDO); the contract sets BQ25792
    IINDPM / VINDPM, lowered before a step down; Type-C Rp current without PD
    - Dock (VAC2) preferred with a configurable limit; USB-C source 5 V 3 A via
    BQ25792 OTG when no dock and the battery is good, source gating in the CAD
    - BQ25792: OTG, EN_EXTILIM, AUTO_INDET, VAC1 pull-down, input poll; the
    charger re-applies the input target after watchdog / chip reset
    - ST stack USER CODE: bridge (headers/usbpd_app.h), DRP settings, 1 ms PD
    timer tick, UCPD IRQ priority workaround, static PE thread, dead-battery Rd release
    - Pow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
2026-11-07 Fix DRC in connector
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2026-11-07 Support USB-C dual port role
    * Add depleted switched to allow disconnecting CC lines resistors
    * Add back to back fet to bridge VOUT line with VBUS1 of USB
    * Expose WS2812B drive line to docker connector
2026-11-08 Remove declarations from if conditions and new from firmware
    - Declare results on their own line instead of
    if (auto r = ...; !r) / if (T* p = ...): charger, oscilloscope,
    scope service, links, fan, encoder, board I/O, diagnostics,
    aux PWM applet, log, frame parser, hostctl.
    - No new operator:
    - broker: RX contexts and RX threads in static std::optional storage
    (emplace) instead of placement new / new os::thread
    - os::thread: closure stored in the object, no heap
    - memtest: static 32-byte aligned buffers instead of heap psram::Buffer
    (+8 KB bss)
    - scope_service: braces around the cases that now declare variables.
2026-11-08 Source USB-C from VOUT through the U26 bridge when the dock is present
    The new back-to-back eFuse U26 (TPS259474A, EN = PC13, ~3 A limit)
    connects VOUT (TPS55289) to VBUS_USBC. The OTG path cannot run with the
    dock (VBUS above UVLO), so with the dock the 5 V 3 A source comes from
    VOUT, used as it is: never changed for USB.
    - PowerPath: source path VOUT (dock) or OTG (battery), fixed while VBUS
    is on; a change of the wanted path ends the source role (error
    recovery). Bridge closes only after the charger input is forced to the
    dock (EN_ACDRV1=0); VBUS must reach 4.5 V within 100 ms or VOUT is
    marked unusable until it changes or the dock leaves. Host-forced USB-C
    input blocks the bri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
2026-11-08 Add declarative applet control and a runner; port aux-pwm off argum
    Applets declare their parameters and readouts once (AppletControl:
    ParamDesc / ReadoutDesc, run state, start/stop). Front ends build on
    that declaration instead of parsing each applet's CLI.
    - applet_control:
    - the declarations and check_param() (range, step grid, bool,
    choice);
    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
2026-11-08 Add ship-mode power off through the BQ25792 ship FET
    Q3 (SiR696DP) sits between the charger's BAT pin and the battery, with
    its gate on SDRV, as in datasheet fig. 8-14. With SFET_PRESENT set, the
    charger can cut the battery off (ship mode). /QON (SW1, or SW2 on the
    IO board) or an adapter plug-in turns the board on again.
    - protocol: PowerOffRequest {SOFT, SHIP, CANCEL} (Request.power_off,
    answered with system_status) and SystemStatus.power_off (state,
    USB-C / dock / VBUS / battery present, time to cut-off).
    - Charger:
    - SFET_PRESENT is set with the policy bits at boot and after a
    watchdog reset (CHARGER_SHIP_FET_PRESENT, default 1).
    - set_vbus_discharge(), enter_ship_mode() (SD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
2026-11-09 Fix issues with the main pcb
2026-11-13 Rework the main board analog front end
    FB sync:
    - Replace the TL3116 with a TLV3603 (project symbol in thirdparty/).
    Hysteresis is set on LE/HYS by RV2 100k + R43 50k (about 30-65 mV).
    - Remove the R46/C86 speed-up network that latched the comparator.
    - Clamp the node with BAS70-02V diodes. R27 becomes 2.2k 2512 so the
    input survives 50 Vpk; D8 is DNP to cut node capacitance.
    - FB_REF comes from the PA5 DAC through an OPA365 buffer (U10).
    - The comparator gets its own VCC supply through FB2, C85 and C65.
    - Add R45 33R in series with FB_OUT.
    - Add DNP bench options: R28/R44 (node bias) and C103 (edge blanking).
    OCD/OCD2:
    - Remove the digipots and keep fixed-gain full-wave rectifiers.
    - U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

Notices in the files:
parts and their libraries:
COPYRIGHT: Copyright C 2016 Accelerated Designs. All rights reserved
